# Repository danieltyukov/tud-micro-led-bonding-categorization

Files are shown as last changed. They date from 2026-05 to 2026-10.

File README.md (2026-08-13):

# Micro-LED Bonding Categorization

**A PCB test vehicle, a cleanroom bonding campaign, and an electrical characterization of eight micro-LED assembly conditions.**

TU Delft ECTM + ITEC B.V., February to August 2026. Course project (ET4277 + ET4391) and research contribution, supervised by M. Mastrangeli, H. van Zeijl and A. Abdelwahab, with R. van Hoorn and H. Kuipers (ITEC B.V. / Nexperia). Financed by ITEC B.V. and co-financed by RVO. Extends the v1 board published at [ECTC 2025](https://doi.org/10.1109/ECTC51687.2025.00363).

The question behind the work: when a ~1 mm² LED die is attached to a PCB without mounting pressure (pick-and-release / air-drop), how good is the resulting bond, and what instrument does it take to tell one bonding process from another?

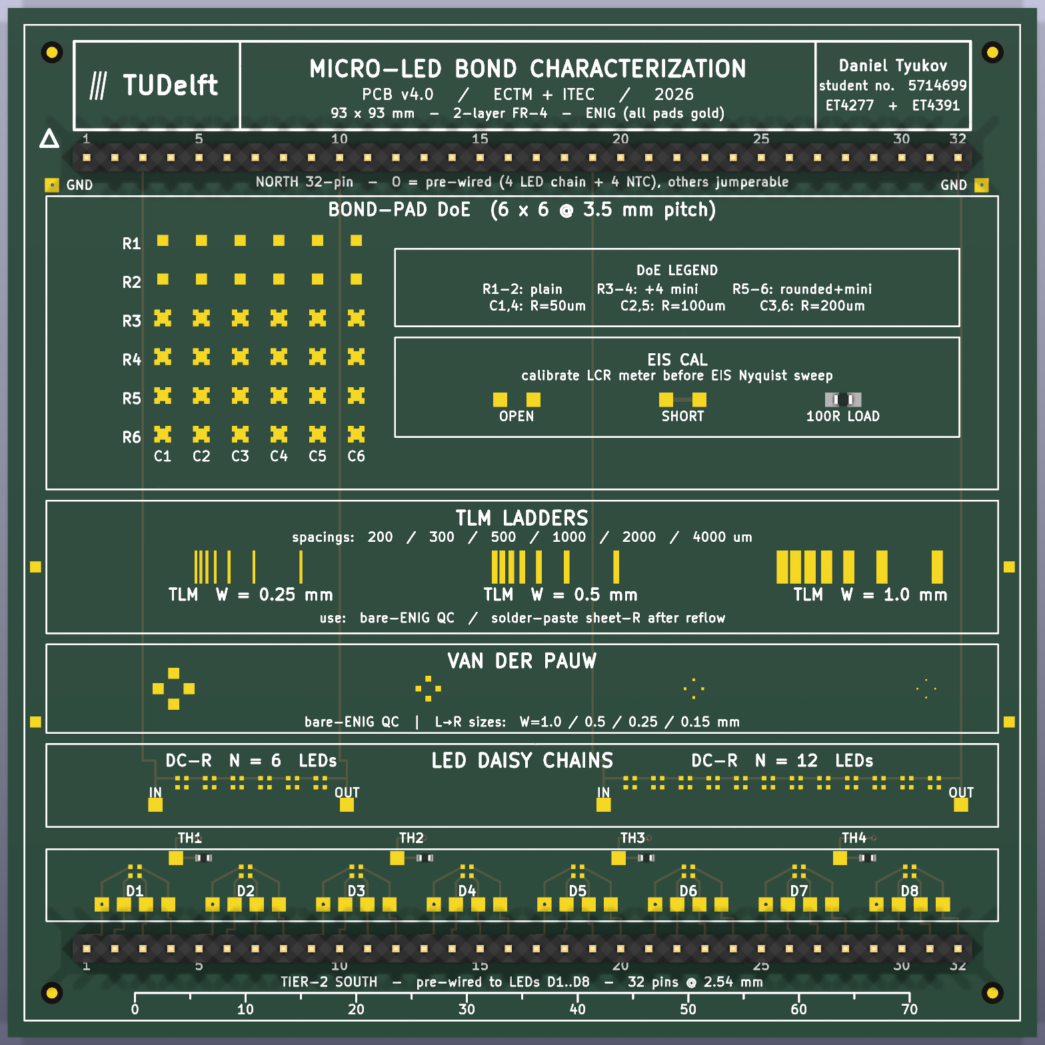
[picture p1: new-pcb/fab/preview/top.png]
Annotated fab render of the v4 micro-LED bond characterization board


---

## Headline result

**Yield and failure mode separate the eight assembly conditions. Series resistance cannot, and the reason is measured rather than assumed.**

| Condition | Channel yield | Failure modes | Assessment |
|---|---:|---|---|
| 1 | 83.3 % | 1 open, 3 detached | under-bonded |
| 2 | 58.3 % | 4 open, 6 detached | under-bonded |
| 3 | 25.0 % | 4 short, 2 open, 2 cross-lit, 1 suspect | over-bonded, 1 shunt confirmed |
| 4 | 66.7 % | 1 short, 1 open, 1 cross-lit, 1 suspect | over-bonded |
| 5 | **100 %** | none | in window |
| 6 | 75.0 % | 3 detached | under-bonded |
| 7 | **100 %** | none | in window |
| 8 | 83.3 % | 2 short | over-bonded, survivors clean |

A χ² test on the yield and failure-mode distribution gives p = 2.2 × 10⁻⁴. Conditions 5 and 7 lost nothing across every channel.

Series resistance does not discriminate: one-way ANOVA over the seven samples with n ≥ 3 gives F(6,21) = 1.96, not significant. Re-seating the same two jumpers on an unchanged channel moves R_s by **0.84 Ω**, which is 85 % of the apparent die-to-die spread, while the bond resistances being chased are **10 to 100 mΩ**. The experiment was never capable of resolving them, and the repeatability study is what proves it.

<table>
<tr>
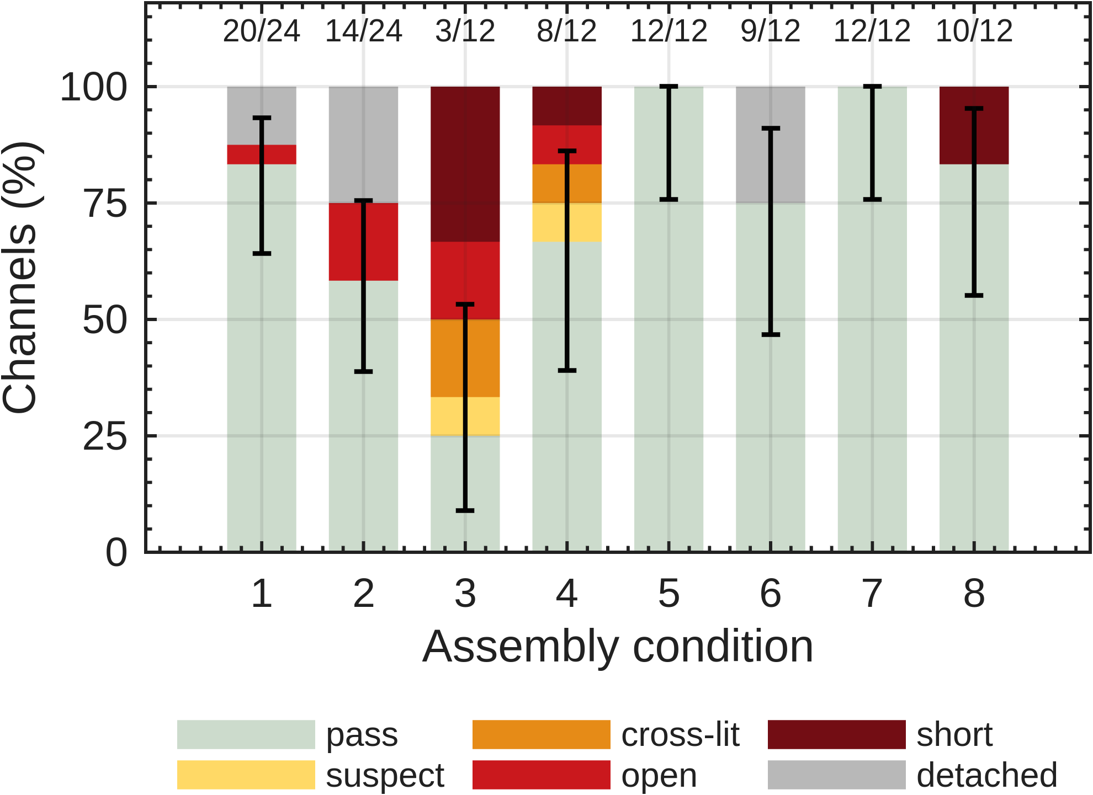
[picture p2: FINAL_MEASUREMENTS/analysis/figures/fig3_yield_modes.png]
Channel yield and failure mode by assembly condition
<td width="50%"></td>
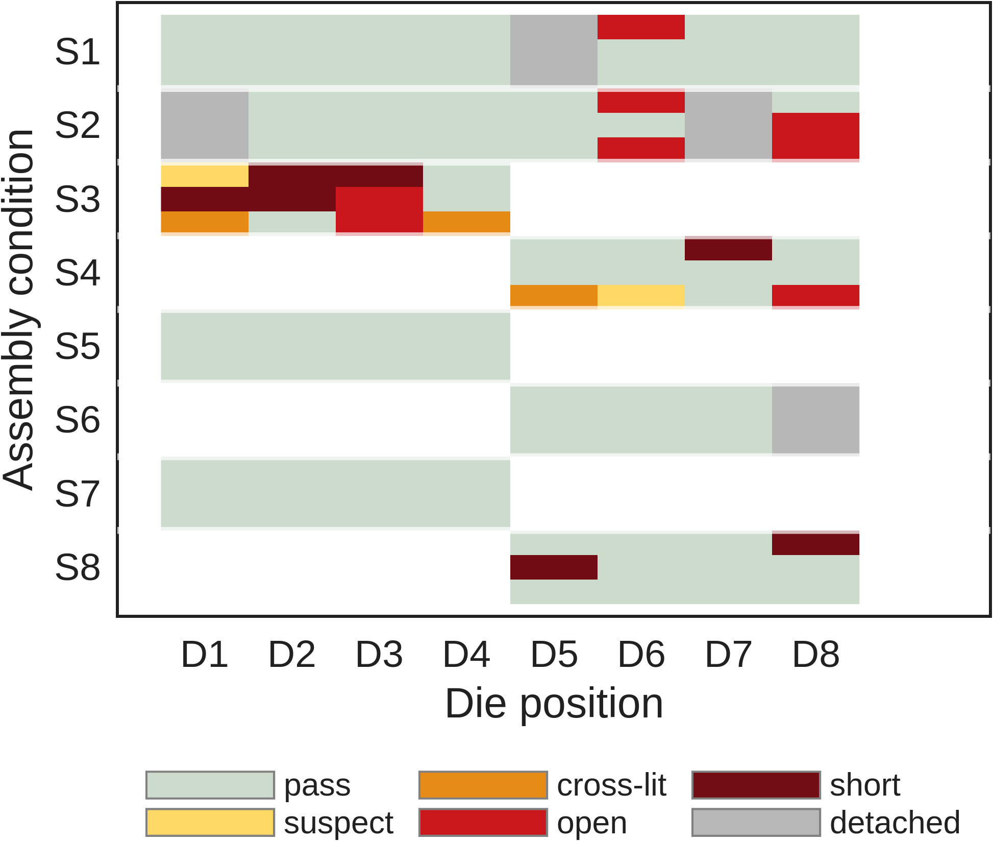
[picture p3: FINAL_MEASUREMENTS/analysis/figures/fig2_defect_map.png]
Per-die defect map across the eight conditions
<td width="50%"></td>
</tr>
<tr>
<td>Yield and failure mode per condition, with Wilson intervals.</td>
<td>Defect map: every die position, every condition.</td>
</tr>
</table>

---

## The three parts of the work

### 1. Board design

A single 93 × 93 mm two-layer FR-4 board (ENIG, all pads gold) carrying every structure needed to characterize a bond on one substrate, so that one cleanroom session yields bond resistance, contact resistivity, sheet resistance and junction thermometry from the same hardware:

- **6 × 6 bond-pad design of experiments** at 3.5 mm pitch: three pad geometries (plain, four corner mini-pads, rounded + mini) crossed with three fillet radii (50 / 100 / 200 µm).
- **TLM ladders** at W = 0.25 / 0.5 / 1.0 mm with spacings 200 to 4000 µm, and **van der Pauw cloverleaves** at W = 1.0 / 0.5 / 0.25 / 0.15 mm.
- **26 Würth WL-SFCC 0404 RGB LEDs**: eight individually addressable, eighteen in 6- and 12-die daisy chains.
- **Four 0402 NTCs** for V_F-based junction thermometry, and an **LCR calibration set** (open / short / 100 Ω 0.1 %).
- Two 32-pin headers breaking every active net out to a breadboard.

Designed in KiCad 9, DRC-clean with full schematic parity, exported fab-ready to the Eurocircuits standard pool. The five SMT parts are reflowed by the fab; the 26 LED bond pads ship as bare gold, because the joint itself is the research subject and has to form under controlled conditions.

Sources, Python generators and the full fab package (gerbers, BOM, CPL, STEP, PDFs) are in [`new-pcb/`](new-pcb/). Report: [`part1/`](part1/ET4277_ET4391_DanielTyukov_5714699_part1_microLED_PCB_electrical_characterization.pdf).

### 2. Cleanroom bonding

Solder paste printed by hand through a 100 µm stencil, dies placed with a Tresky T-3000-PRO die bonder, joint formed on a hot plate with Sn42/Bi57.6/Ag0.4 (T_melt = 138 °C). When the paste melts, surface tension pulls each die toward the centre of its pad set. The same forces can tilt a die and lock it in a crooked position that never recovers, because tilt is the one non-restoring self-alignment mode for a rectangular chip.

<table>
<tr>
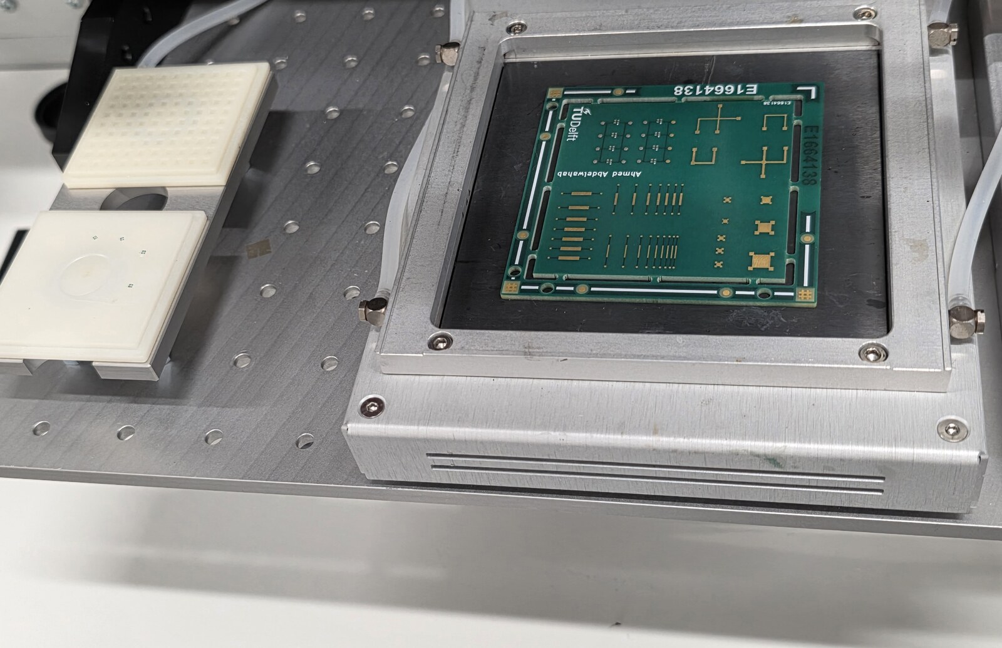
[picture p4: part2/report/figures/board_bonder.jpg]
v1 board mounted in the Tresky die bonder
<td width="50%"></td>
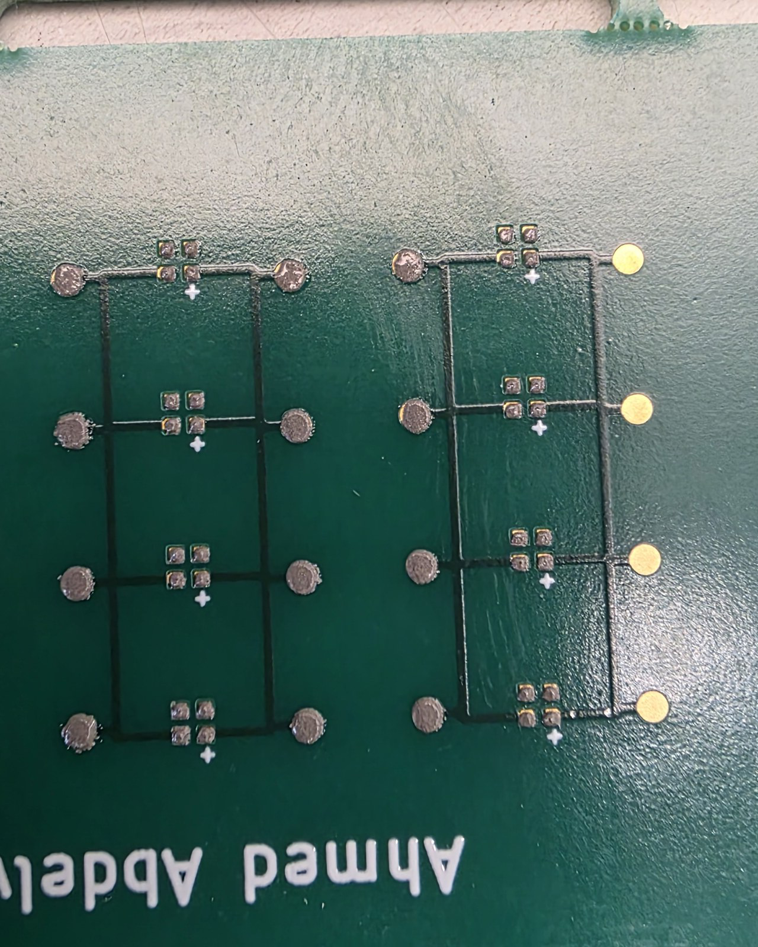
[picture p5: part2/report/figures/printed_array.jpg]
Solder-paste printed bond-pad array before die placement
<td width="50%"></td>
</tr>
<tr>
<td>Board fixtured in the Tresky T-3000-PRO.</td>
<td>Printed bond-pad array before placement.</td>
</tr>
</table>

The analytical contribution is reading the observed self-alignment and tilt against the capillary self-alignment literature to identify which process variable dominates. It is **solder volume**: manual stencil printing gives no volume metering, and volume is exactly the quantity the literature ties most strongly to both placement accuracy and the non-restoring tilt mode.

Report: [`part2/`](part2/ET4277_ET4391_DanielTyukov_5714699_part2_microLED_bonding_self_alignment_die_tilt.pdf). Session photos in [`part2/photos-during-lab2/`](part2/photos-during-lab2/), references in [`part2/downloaded_references/`](part2/downloaded_references/).

### 3. Electrical characterization

Eight blind-coded assembly conditions across five coupons, 40 dice bonded, 4 detached in handling, 36 measurable, 120 individual-die channels. Run as two rounds so that a cheap screen filtered the expensive one.

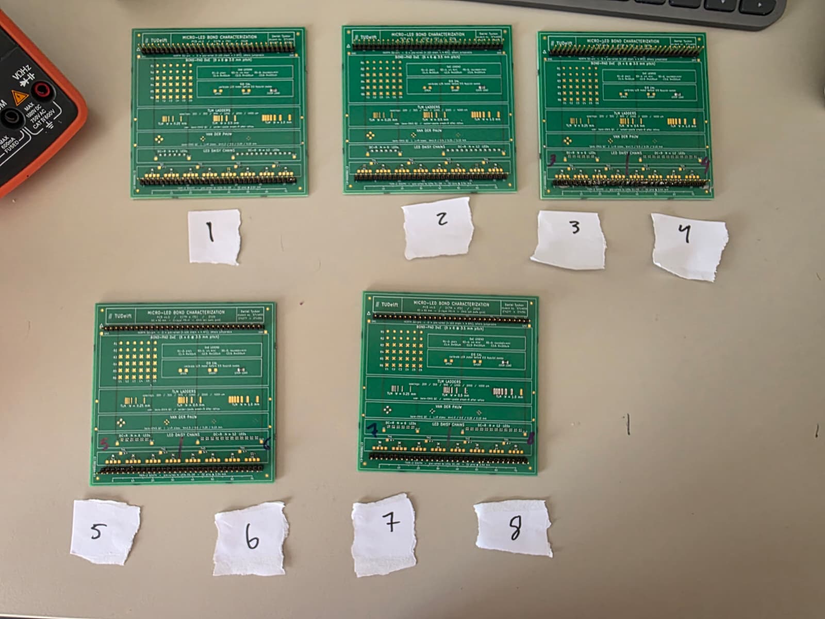
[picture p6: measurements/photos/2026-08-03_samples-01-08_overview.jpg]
The five coupons carrying the eight blind-coded assembly conditions


**Round 1, DMM screen.** Every channel screened for opens, shorts, cross-lighting and detachment with a handheld meter. It called six channels bad; the sweep rig later agreed on all six and disagreed on none in 89 sweeps.

**Round 2, current sweep.** An Arduino UNO rig switching a six-resistor bank (220 Ω to 10 kΩ) against a 100 Ω sense resistor, 63 current levels per sweep, fitting V = V₀ + n·V_T·ln(I) + I·R_s to each channel. 89 channel sweeps plus 9 re-seating repeatability runs.

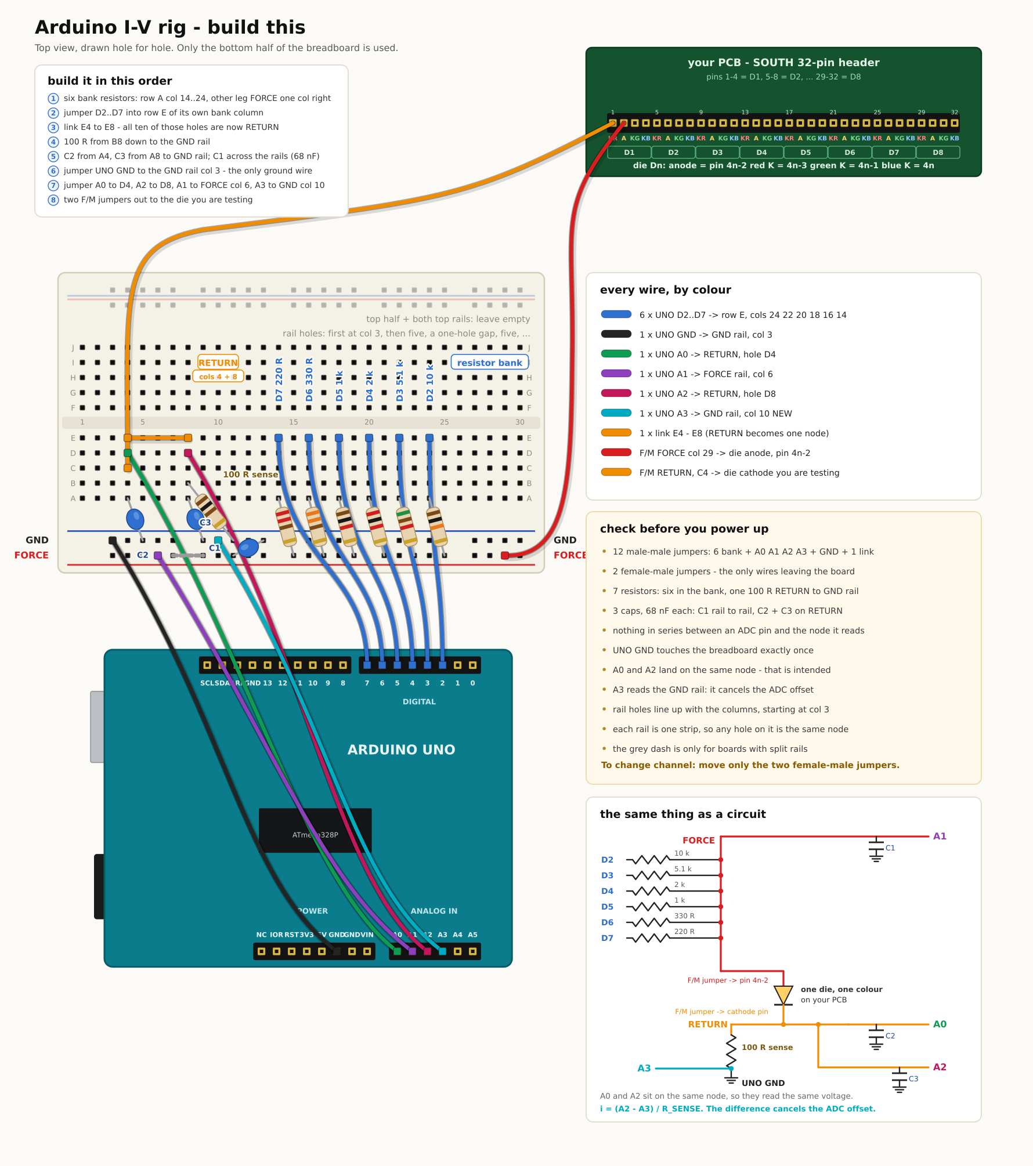
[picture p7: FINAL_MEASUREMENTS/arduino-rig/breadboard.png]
Arduino I-V rig build drawing


<table>
<tr>
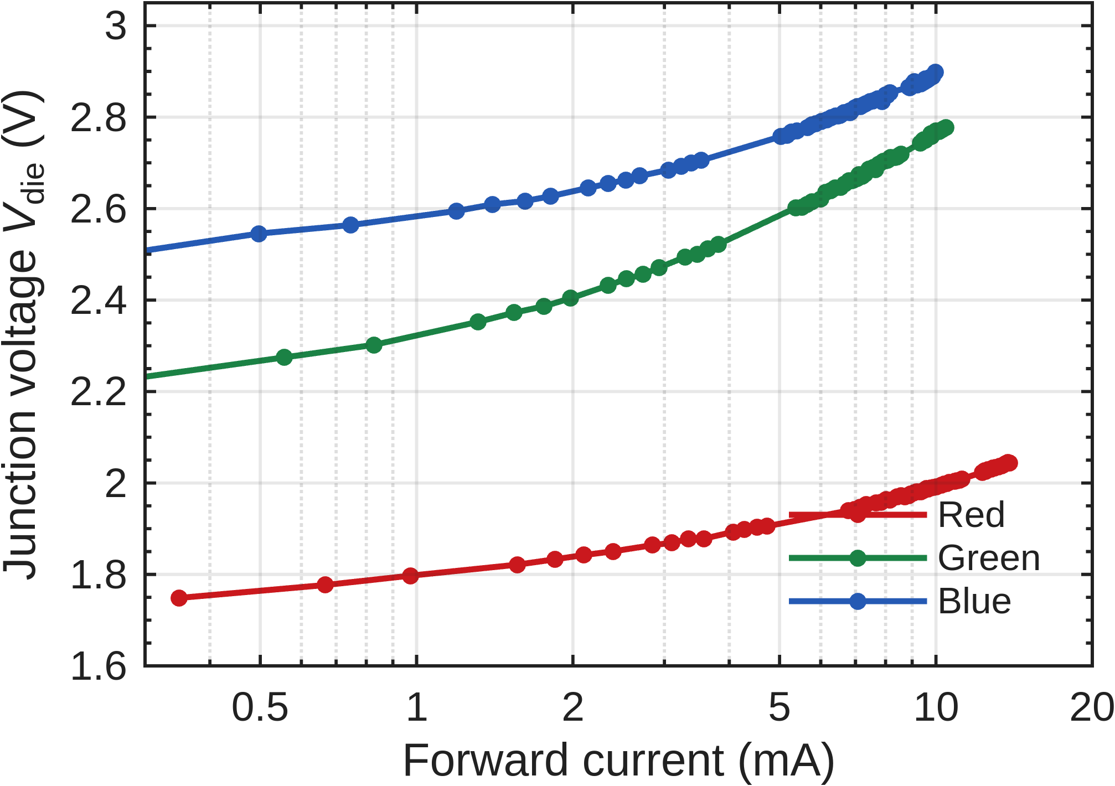
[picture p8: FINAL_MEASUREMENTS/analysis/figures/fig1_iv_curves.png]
I-V curves for the red, green and blue junctions of one die
<td width="50%"></td>
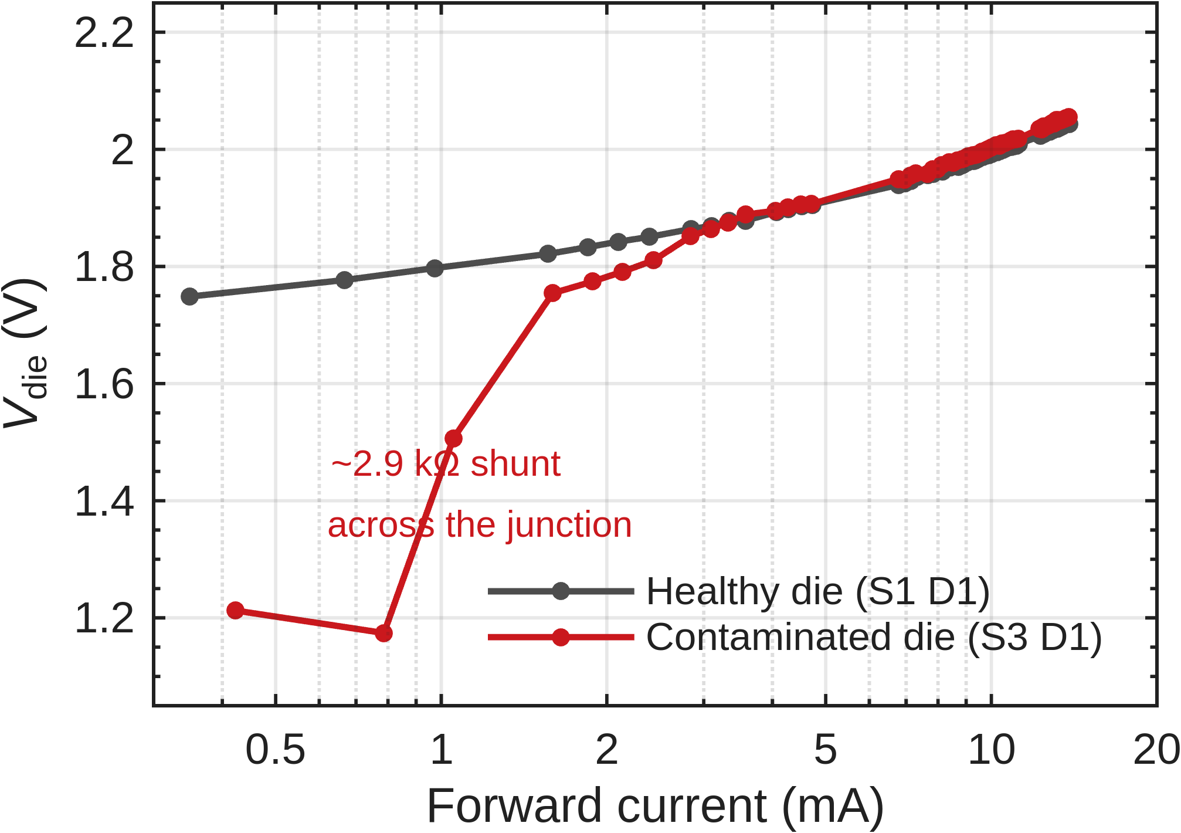
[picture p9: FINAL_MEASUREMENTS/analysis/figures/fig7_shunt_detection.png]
Ideality check exposing a 2.9 kilohm shunt across a contaminated junction
<td width="50%"></td>
</tr>
<tr>
<td>Red, green and blue junctions of one die.</td>
<td>The defect only a current sweep could see.</td>
</tr>
</table>

Three findings about the measurement itself carried more weight than the bond numbers:

- **The ideality factor is a free defect detector.** Any channel fitting outside n = 1.2 to 2.4 has something in parallel with the junction, however normal its curve looks at working current. It caught a ~2.9 kΩ shunt on a contaminated die that the DMM passed at 1.781 V.
- **Green and blue are not fittable at 5 V.** With V_F near 2.8 V the rail leaves only a 20× current range, so V₀, n and R_s trade off and green fits at an unphysical n = 3.2 to 4.0. Red gets 30× and fits cleanly at n = 1.60 to 2.06. Red only.
- **Four instrument defects were found and fixed mid-campaign**, including a hardcoded oversampling shift that would have rescaled every voltage, a 14.4 mV common ADC offset worth 26 % current error at the bottom of the sweep, and an integer-truncated bandgap reference putting a 2 to 3 mV floor on every reading.

Full working log with per-channel results: [`RESULTS/R2_REPORT.md`](RESULTS/R2_REPORT.md). Packaged deliverable with figures, MATLAB and raw data: [`deliverable/`](deliverable/microLED_electrical_characterization/).

**Dummy-die daisy chains (separate experiment, v1 board).** Measured by A. Abdelwahab on the v1 PCB in its own session, six Au-coated 1 mm² dummy dies per chain, one chain per condition. It resolves bond resistance where the LED coupons could not: 0.22 Ω on condition 5 against 0.61 Ω on condition 4, roughly 30 mΩ per joint, with a reported deviation of 11 to 20 mΩ. Its ranking agrees with the LED yield ranking at ρ = −0.92 (p = 0.003). That is agreement between assembly conditions across two different test vehicles and two campaigns, not two structures on one coupon, and it assumes the condition numbering matches. The v2 board carries daisy chains as well, but none were measured: a layout fault left them dead, so they were diagnosed and excluded rather than characterized (see Known limits). Data and figure: [`RESULTS/daisy_chain/`](RESULTS/daisy_chain/).

---

## Known limits

Stated up front, because they decide what these numbers can be used for.

| Limit | Consequence |
|---|---|
| Both voltage taps sit on the breadboard, not on the Tier-1 probe pads | Two female-male jumpers fall inside the measured loop. R_s is not usable for comparing bonds in this build. Kelvin sensing at the probe pads fixes it. |
| 5 V supply | Green and blue fits are unphysical. Red only. |
| Reverse bias measured through the meter's own 10 MΩ input impedance | Detects shunts below ~10 MΩ, cannot grade healthy dies. It confirmed the yield ranking rather than adding to it. |
| Daisy chains read open on every coupon | Layout fault, not a bonding failure: the dice sit rotated 90°, so the chain joins each die's red cathode to its blue cathode and leaves the anode floating. Fixed in the next revision. |
| One coupon carries uncleanable solder smear | Its readings characterize a post-process contamination failure and are excluded from V_F statistics. |
| No NTC readings collected | Ambient drift cannot be separated from self-heating at analysis time. |
| TLM, van der Pauw and impedance spectroscopy | Designed into the board, but the instruments were not available during the campaign. The structures are there for whoever has them. |

---

## Repository layout

| Path | Contents |
|---|---|
| [`new-pcb/`](new-pcb/) | v4 KiCad project, Python generators, Eurocircuits fab package, design notes |
| [`part1/`](part1/) | Board design and characterization-methodology report, project archive, fab quote |
| [`part2/`](part2/) | Bonding process report, cleanroom photos, self-alignment literature |
| [`FINAL_MEASUREMENTS/`](FINAL_MEASUREMENTS/) | Bench procedures, Arduino rig build drawings, MATLAB analysis, figures |
| [`RESULTS/`](RESULTS/) | Raw round 1 and round 2 data, per-channel results, round 2 report |
| [`measurements/`](measurements/) | Measurement plan, equipment limits, sample inventory, decision log |
| [`deliverable/`](deliverable/) | Self-contained characterization package: report, figures, code, data |
| [`old-pcb/`](old-pcb/) | v1 board (ECTC 2025), kept for reference |
| [`docs/`](docs/) | Datasheets, published papers, patent, collaboration notes |
| [`PROJECT_DETAILS.md`](PROJECT_DETAILS.md) | Full project context, v1 board teardown, literature notes |

## Reproducing the analysis

```
cd deliverable/microLED_electrical_characterization/matlab
matlab -batch figures
```

Reads `../data/`, refits every sweep, writes all eight figures, and prints every number quoted in the report. MATLAB R2025b with the Statistics and Machine Learning Toolbox (`anova1`, `chi2cdf`).

Board previews and fab outputs regenerate from `new-pcb/tools/`; see [`new-pcb/README.md`](new-pcb/README.md) and [`new-pcb/FABRICATION_ORDER.md`](new-pcb/FABRICATION_ORDER.md) for the ordering workflow.

## Reports

| Report | File |
|---|---|
| Part 1: A PCB Test Board for Electrical Characterization of Solder-Bonded Micro-LEDs | [PDF](part1/ET4277_ET4391_DanielTyukov_5714699_part1_microLED_PCB_electrical_characterization.pdf) |
| Part 2: Solder-Paste Printing and Die-Bonder Placement of Micro-LEDs, Capillary Self-Alignment and Die Tilt | [PDF](part2/ET4277_ET4391_DanielTyukov_5714699_part2_microLED_bonding_self_alignment_die_tilt.pdf) |
| Electrical characterization section (group deliverable) | [PDF](deliverable/Electrical_Characterization_section.pdf) |

## Tooling

KiCad 9, Python (fab, BOM and drawing generators), MATLAB R2025b, Arduino UNO / ATmega328P firmware, Eurocircuits PCB + PCBA, Tresky T-3000-PRO die bonder, eC-stencil-mate, handheld DMM.

## Credits

Daniel Tyukov (student no. 5714699), MSc Microelectronics, TU Delft. Supervision and cleanroom training: A. Abdelwahab, H. van Zeijl, M. Mastrangeli (TU Delft ECTM). Industrial partner: R. van Hoorn, H. Kuipers (ITEC B.V. / Nexperia). The v1 board and the pick-and-release method are the work of Abdelwahab et al., ECTC 2025, DOI [10.1109/ECTC51687.2025.00363](https://doi.org/10.1109/ECTC51687.2025.00363).

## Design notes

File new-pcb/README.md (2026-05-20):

# new-pcb — v2 Micro-LED Bonding Characterization PCB

**Status: fab-ready.** DRC clean (0 violations, 0 unconnected, 0 schematic-parity). Workflow: *Eurocircuits PCB + PCBA-proto*, all 3 BOM lines set to "Place on board" so the 4 NTC + 1 R + 2 header strips are reflowed / soldered by Eurocircuits. F.Paste has 10 apertures (NTC + R only); the 26 LED footprints stay paste-free and ship as bare ENIG gold for cleanroom bonding at TU Delft EKL.

## Quick links

- **Order from Eurocircuits** → `FABRICATION_ORDER.md`
- **As-built design notes** → `V2_DESIGN_NOTES.md`
- **Original spec** → `PCB_DESIGN_PLAN.md`
- **Electrical characterization workflow** → `ELECTRICAL_CHARACTERIZATION.md`
- **What this v2 contributes vs ECTC 2025** → `PUBLICATION_CONTRIBUTION.md`

## Folder layout

```
new-pcb/
├── tud-microled-v2.kicad_pro     KiCad 9.0.8 project
├── tud-microled-v2.kicad_pcb     PCB layout (130 footprints, DRC clean)
├── tud-microled-v2.kicad_sch     single-sheet A2 schematic
├── PCB_DESIGN_PLAN.md            original design spec
├── V2_DESIGN_NOTES.md            as-built notes
├── VERIFICATION_v4.md            electrical-characterization verification
├── ELECTRICAL_CHARACTERIZATION.md measurement plan + lab tools
├── FABRICATION_ORDER.md          Eurocircuits "Place loose" order checklist
├── PUBLICATION_CONTRIBUTION.md   v2 contributions vs ECTC 2025
├── library/                      Würth WL-SFCC LED symbol/footprint/3D
├── tools/                        Python helpers (PCB patcher, BOM generator)
└── fab/                          gerbers, BOM, pos, PDFs, STEP, top.png
    ├── tud-microled-v2-fab-bom.csv          BOM with TDK + Yageo + Samtec MPNs (Mouser PNs included)
    ├── tud-microled-v2-fab-bom-assembly-only.csv  slim BOM (the 3 assembled rows only)
    ├── tud-microled-v2-pos.csv               7 placements
    ├── tud-microled-v2-top.pdf / -bot.pdf    visual review
    ├── tud-microled-v2-gerbers.zip           26-file gerber + drill bundle
    ├── tud-microled-v2.step                  3D model
    └── preview/top.png                       1600×1600 raytraced render
```

## Design summary

| | |
|---|---|
| Board | 93 × 93 mm, 2-layer FR-4, 1.55 mm |
| Finish | ENIG (Ni 4 µm / Au 0.075 µm) |
| Min track / clearance | 0.20 / 0.30 mm (Eurocircuits Class 4 minimum is 0.15 mm) |
| Min drill / annular ring | 0.30 / 0.15 mm |
| Footprints on board | **130** (1 R + 4 NTC + 2 multi-pin headers + 26 LEDs DNP) |
| Distinct components | **3** (Yageo R, TDK NTC, Samtec header) |
| Placements per board (assembled) | **7** (1 R + 4 NTC + 2 header strips) |
| LED bonding | 26 × Würth WL-SFCC RGB at customer cleanroom (Tresky T-3000-PRO) |
| Solder-paste apertures | **10** on F.Paste (4 NTC × 2 + 1 R × 2). B.Paste empty. 26 LED footprints intentionally paste-free. |

## Bill of materials

3 distinct part numbers — all stocked at Mouser EU (1-day NL delivery) and resolvable through Eurocircuits' supplier scanner:

| Ref(s) | Manufacturer | MPN | Mouser PN |
|---|---|---|---|
| R_EIS_LOAD | Yageo | RT0603BRB07100RL | 603-RT0603BRB07100RL |
| H_N + H_S | Samtec | TSW-140-07-G-S | 200-TSW14007GS |
| TH1..TH4 | TDK | NTCG104BH103HT1 | 810-NTCG104BH103HT1 |

## Quick start

1. Open `tud-microled-v2.kicad_pro` in KiCad 9.0 or newer.
2. Confirm `WE_3DMODEL_DIR` is set in **Preferences → Configure Paths** (see `library/README.md`).
3. Run checks: `kicad-cli pcb drc tud-microled-v2.kicad_pcb` and `kicad-cli sch erc tud-microled-v2.kicad_sch` — both should report 0 violations.
4. Regenerate fab outputs after any PCB edit:
   - `kicad-cli pcb export gerbers --output fab/gerbers/ tud-microled-v2.kicad_pcb`
   - `kicad-cli pcb export drill --output fab/gerbers/ tud-microled-v2.kicad_pcb`
   - `kicad-cli pcb export pos --format csv --units mm --use-drill-file-origin --output fab/tud-microled-v2-pos.csv tud-microled-v2.kicad_pcb`
   - `kicad-cli pcb export pdf --layers F.Cu,F.Silkscreen,F.Mask,Edge.Cuts -o fab/tud-microled-v2-top.pdf tud-microled-v2.kicad_pcb`
   - `kicad-cli pcb render --side top --width 1600 --height 1600 --quality high --output fab/preview/top.png tud-microled-v2.kicad_pcb`
   - `python3 tools/gen_fab_bom.py` to refresh the BOM CSV
   - `(cd fab/gerbers && zip -q ../tud-microled-v2-gerbers.zip *)` to rebundle for Eurocircuits

## tools/ scripts

| Script | Purpose |
|---|---|
| `gen_fab_bom.py` | Reads `fab/tud-microled-v2-pos.csv`, emits `tud-microled-v2-fab-bom.csv` + slim variant |
| `patch_aisler_mpns.py` | Adds Manufacturer + MPN custom fields to each footprint so any fab auto-detects them |
| `consolidate_pcb.py` | One-time refactor that collapsed 64 single-pin headers into 2 multi-pin strips and deleted the 123 bare-pad design-only footprints |
| `strip_all_paste.py` | Removes F.Paste / B.Paste from every pad in the design (used for the loose-components workflow) |
| `clean_dangling.py` | Removes orphan tracks/vias left over by `consolidate_pcb.py` |
| `unify_values.py` | Sets the `Value` field of every footprint to its MPN so Aisler/EC Grouped views collapse them properly |
| `inspect_headers.py` | Read-only debug helper |

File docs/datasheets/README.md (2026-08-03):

# Component Datasheets — v2 PCB

Datasheets for every component ordered for the v2 PCB. All MPNs match the BOM in `new-pcb/fab/tud-microled-v2-fab-bom.csv` and are verified in stock on Mouser EU at order time.

**Components ship loose from Eurocircuits ("Place loose") and are hand-soldered at TU Delft EKL. The 26 LEDs are customer-supplied and bonded at EKL under the Tresky T-3000-PRO with a controlled paste profile.**

---

## Final BOM (3 distinct parts, 7 placements per board)

| Designator(s) | Qty / board | Manufacturer | MPN | Mouser PN | Datasheet file |
|---|---:|---|---|---|---|
| TH1, TH2, TH3, TH4 | 4 | TDK | `NTCG104BH103HT1` | 810-NTCG104BH103HT1 | `TDK-NTCG104BH103HT1-NTC.pdf` |
| R_EIS_LOAD | 1 | Yageo | `RT0603BRB07100RL` | 603-RT0603BRB07100RL | `Yageo-RT0603BRB07100RL-Resistor.pdf` |
| H_N, H_S | 2 | Samtec | `TSW-140-07-G-S` (cut to 1×32) | 200-TSW14007GS | `Samtec-TSW-Series-PinHeader.pdf` |
| D1-D8 + DCL6_L1..6 + DCL12_L1..12 | 26 | Würth | `150044M155220` | 710-150044M155220 | `Wurth-WL-SFCC-0404-RGB-LED-150044M155220.pdf` |

---

## Datasheets in this folder

| File | Pages | Component | Where on PCB |
|---|---:|---|---|
| `TDK-NTCG104BH103HT1-NTC.pdf` | 20 | TDK NTCG104 series — NTC 10 kΩ ±3% 0402, AEC-Q200 | TH1..TH4 |
| `Yageo-RT0603BRB07100RL-Resistor.pdf` | 10 | Yageo RT series — 100 Ω ±0.1% 0603 thin-film, 10 ppm/°C | R_EIS_LOAD |
| `Samtec-TSW-Series-PinHeader.pdf` | 6 | Samtec TSW series — product specification sheet (electrical, mechanical) | H_N + H_S |
| `Wurth-WL-SFCC-0404-RGB-LED-150044M155220.pdf` | 10 | Würth WL-SFCC RGB LED — full electrical/optical/mechanical/reflow | D1..D8, DCL6_L1..6, DCL12_L1..12 |

All downloaded from manufacturer / Mouser EU on **2026-05-19**.

---

## Test-equipment documentation (added 2026-08-03)

For the measurement campaign in `FINAL_MEASUREMENTS/`.

| File | Pages | What it is |
|---|---:|---|
| `INSTRUMENTS.md` | - | **Start here.** Extracted specs for the multimeter and the Arduino, with what is documented, what is not, and the numbers that must be measured at the bench instead. |
| `Arduino-UNO-R3-Datasheet.pdf` | 26 | Arduino UNO R3 board datasheet |
| `Microchip-ATmega328P-Datasheet.pdf` | 294 | Microchip 7810D-AVR-01/15. Source of the ADC specs and the absolute maximum ratings that constrain the current bank |
| `Thsinde-18B-plus-Independent-Review-N8FDY.pdf` | 8 | Independent bench review of this exact meter against a calibrated Keithley DMM6500. **The only source for its diode-test voltage and current.** |
| `Fluke-15B-17B-18B-plus-Users-Manual.pdf` | 23 | **A different instrument.** Cross-reference only, see below |

### On the Thsinde 18B+ multimeter

**No manufacturer manual exists.** The only page that claims to be one
(`manuals.plus/thsinde/...`) is AI-generated SEO filler carrying the Amazon listing spec
table plus invented reviews and a price. It contains no operating instructions, no button
behaviour, and no diode-test specification. It is not worth storing, so its usable content
is transcribed into `INSTRUMENTS.md` instead.

The Fluke 15B+/17B+/18B+ manual is stored as a cross-reference **only**. It is a different
instrument: 4000 counts rather than 6000, no NCV, no REL, no MAX/MIN, and it has a
dedicated LED TEST dial position that the Thsinde does not. The Thsinde borrowed the model
number and the styling. Do not quote its specifications as if they were the Thsinde's.

The gap is filled by the N8FDY independent review, which measured the meter against a
calibrated Keithley DMM6500. Its key result for this project: **diode test open-circuit
voltage 3.245 V, short-circuit current 1.49 mA.** 3.245 V clears the forward voltage of
red, green and blue, so all three channels are testable in round 1 step 6. That had been
the largest open risk in the measurement plan. It is still re-confirmed on the board's own
100 Ω 0.1 % reference at the start of each session.

---

## Component summary

### TDK NTCG104BH103HT1 — SMD 0402 NTC
- 1.0 × 0.5 mm body, 2 SMD pads
- R(25 °C) = 10 kΩ ±3 %, **B25/85 = 4100 K** (datasheet row for this MPN: 4067 / 4092 / 4100 / 4110 K for B25/50, B25/80, B25/85, B25/100)
- **Correction 2026-08-03:** this file previously said 3380 K. That is the B25/50 figure for the *NTCG10xJF/JH* family, a different B-constant grade. The ordered part is the `BH` grade, which is the 4067-4110 K row.
- AEC-Q200 qualified, −55 °C to +125 °C operating range
- Sense current ≤ 100 µA to keep self-heating < 0.01 °C
- For V_F-TSP thermometry calibration: see `new-pcb/VERIFICATION_v4.md` §6.2
- Mouser EU stock: 12,207 (verified 2026-05-19)

### Yageo RT0603BRB07100RL — SMD 0603 thin-film
- 1.6 × 0.8 mm body
- 100 Ω, ±0.1 %, **10 ppm/°C** TCR, 100 mW (1/10 W)
- −55 °C to +155 °C operating range, 75 V max
- Used as the EIS reference load for LCR-meter calibration before Nyquist sweeps
- Mouser EU stock: 15,867 (verified 2026-05-19)
- Note: chosen over the original RT0603BRD07100RL because BRD was out of stock (backorder to Sep 2026); BRB is a strict upgrade (10 ppm/°C vs 25 ppm/°C TCR) at the same form factor

### Samtec TSW-140-07-G-S — THT 1×40 single-row male pin header
- 2.54 mm pitch, gold-plated contacts (Ni underplate + Au flash)
- Pin cross-section: 0.64 mm square
- Pin length above board: 5.84 mm
- Insulator height: 2.54 mm
- Each board uses 2 strips (one trimmed to 32 pins for the north row, one for the south row)
- Drill 1.0 mm, pad 1.7 mm Ø → annular ring 0.35 mm
- Mouser EU stock: 338 (verified 2026-05-19) — sufficient for 20 strips needed by 10 boards

### Würth WL-SFCC 0404 RGB LED — SMD (customer-bonded)
- 0.95 × 0.95 × 0.25 mm body, 4 contact pads at corners (one anode + R/G/B cathodes)
- V_F red ≈ 2.05 V, green/blue ≈ 3.05 V at 10 mA
- Reflow recommended per Würth profile §6 of the datasheet — *not used here* because we bond at EKL with the Tresky's controlled profile
- Bond pads ship as bare ENIG gold (F.Paste gerber is empty — fab applies no paste)

---

## NTC R-T equation (for V_F-TSP calibration)

T(K) = 1 / [ (1/T₀) + (1/B) · ln(R / R₀) ]

with T₀ = 298.15 K, R₀ = 10 000 Ω, **B = 4100 K**. See `new-pcb/VERIFICATION_v4.md` §6.2 for the full thermal-resistance test procedure.

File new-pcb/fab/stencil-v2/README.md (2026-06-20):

# Stencil v2 — corrected solder-paste stencil (Eurocircuits)

Generated from `tud-microled-v2.kicad_pcb` (KiCad 9.0). This folder contains the
data to order a **new top-side solder-paste stencil** that fixes the previous one.

## What was wrong with the first stencil

The previous stencil had apertures on **only 10 pads** — `TH1–TH4` (thermistors)
and `R_EIS_LOAD` — because those were the only pads carrying an `F.Paste` layer.
Every bond/LED/test pad lacked a paste aperture, so the stencil came back
effectively "reversed": openings only where solder had already been hand-applied,
and nothing where paste actually needs to be printed.

## What this stencil does (two aperture types on `F.Paste`)

1. **Paste apertures** (1:1 with the copper pad) on the **277 bond/characterization
   pads**: DoE bond pads (`BP_*`), WL-SFCC LED lands (`D1–D8`, `DCL6_*`, `DCL12_*`),
   thermocouple pads (`TC*`), and the TLM ladders + Van der Pauw structures
   (`TLM_*`, `VDP_*`) — those are part of the solder/contact-resistance
   characterization, so they get solder.

   **Deliberately left bare (no paste)** — only where a probe tip or vision system
   touches: all probe pads (`PP_*` — daisy-chain in/out, per-LED A/KB/KG/KR, NTC,
   GND, EIS open/short cal) and the fiducials (`FID*`). These keep their soldermask
   opening but get no solder.

2. **Clearance reliefs** (a window drawn *around the component body*, not a paste
   dot) so the foil lies flat over parts already on the board — **no bulges**:
   | Part | Relief window (mm) |
   |------|--------------------|
   | `H_N` header (top pin row) | 5.68,12.05 → 87.32,14.95 |
   | `H_S` header (bottom pin row) | 5.68,83.55 → 87.32,86.45 |
   | `TH1` | 16.6,76.15 → 18.8,77.45 |
   | `TH2` | 36.6,76.15 → 38.8,77.45 |
   | `TH3` | 56.6,76.15 → 58.8,77.45 |
   | `TH4` | 76.6,76.15 → 78.8,77.45 |
   | `R_EIS_LOAD` | 73.52,34.41 → 77.48,36.38 |

   The header pins/bodies and the soldered thermistors/resistor pass through these
   windows. **Note:** these are open windows in the paste layer — if you don't want
   paste falling through over the already-soldered parts, simply don't squeegee
   across those windows (or tape them off during print).

## Files

- `tud-microled-v2-F_Paste.gbr` — the stencil aperture layer (**this is the stencil**)
- `tud-microled-v2-Edge_Cuts.gbr` — board outline, for alignment/registration
- `tud-microled-v2-stencil-v2.zip` — both of the above, zipped for upload
- `paste_preview.svg` / `paste_preview.png` — visual check of the aperture pattern
- `drc_report.txt` — KiCad DRC result (0 violations)

## Ordering notes (Eurocircuits stencil service)

- Order **top stencil only** (no bottom-side components/paste).
- Suggested foil thickness **100–120 µm**. The bond pads (0.4 mm LED, 0.5 mm DoE)
  and the wide TLM bars print fine. **Fine-feature caveat:** the smallest Van der
  Pauw apertures are 0.15 mm and 0.25 mm squares — below the reliable paste-release
  limit (area ratio < 0.66) even with a 100 µm foil, so those central squares may
  transfer little or no paste. The openings are there; just don't count on a clean
  deposit on the 0.15/0.25 mm VDP squares. A thinner foil helps marginally.
- The foil can be larger than the 93 × 93 mm board and trimmed after, as discussed.

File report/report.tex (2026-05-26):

\documentclass[conference]{IEEEtran}
\IEEEoverridecommandlockouts

\usepackage{cite}
\usepackage{amsmath,amssymb,amsfonts}
\usepackage{graphicx}
\usepackage{textcomp}
\usepackage[official]{eurosym}
\usepackage{xcolor}
\usepackage{booktabs}
\usepackage{siunitx}
\usepackage{url}
\usepackage{hyperref}
\hypersetup{colorlinks=true,linkcolor=blue,citecolor=blue,urlcolor=blue}

\def\BibTeX{{\rm B\kern-.05em{\sc i\kern-.025em b}\kern-.08em
    T\kern-.1667em\lower.7ex\hbox{E}\kern-.125emX}}

\begin{document}

\title{A PCB Test Board for Electrical Characterization of Solder-Bonded Micro-LEDs\\
{\normalsize Course report — ET4277 + ET4391 — Part 1}}

\author{\IEEEauthorblockN{Daniel Tyukov}
\IEEEauthorblockA{\textit{Department of Microelectronics, ECTM + ITEC}\\
\textit{Delft University of Technology}\\
Delft, the Netherlands \\
Student no. 5714699 \;\textbar\; \texttt{d.a.tyukov@student.tudelft.nl}}
}

\maketitle

\begin{figure}[!t]
  \centering
  
\end{figure}

\begin{abstract}
This work presents a 93~mm $\times$ 93~mm two-layer FR-4 PCB designed to
characterize how different solder pastes perform when bonding micro-LEDs.
The board carries 26 Würth WL-SFCC 0404 RGB LEDs (8 addressable, 18 in two
daisy chains), four 0402 NTCs for forward-voltage thermometry, a 100~$\Omega$
0.1\% reference resistor with OPEN/SHORT/LOAD pads for impedance
spectroscopy, and a set of TLM ladders and van der Pauw cloverleaves on the
same substrate. Putting all of this on one PCB means a single cleanroom
session yields bond resistance, contact resistivity, sheet resistance, and
junction-to-substrate thermal resistance from the same hardware. No
separate test coupons, no inter-board correlation. Two 32-pin headers break
every active net out to a breadboard. The board is fab-ready for the
Aisler or Eurocircuits standard pool with ENIG plating; LEDs are
deliberately left unassembled,
since the bond joint itself is the research subject and has to form under
controlled cleanroom conditions. The report covers the schematic, the
characterization methods, the tools needed to run them, and the four-paste
comparison the design was built for.
\end{abstract}

\begin{IEEEkeywords}
micro-LED, die bonding, solder paste, V$_F$-TSP, electrochemical impedance
spectroscopy, transmission line method, van der Pauw, daisy chain, electrical
characterization, PCB test vehicle
\end{IEEEkeywords}

\section{Introduction}

Mounting a sub-millimeter LED die on a PCB sounds simple until you measure
it. The joint has to carry current with a low voltage drop, pull heat out
of the die fast enough to keep it from cooking itself, and survive whatever
thermomechanical cycling the application throws at it. With SAC305 reflow
paste, the cheap default, the quality of that joint depends on paste
rheology, stencil aperture, reflow profile, and substrate finish.
Alternative chemistries (Au-Sn eutectic \cite{yin2024ausn}, Cu-Cu direct
bonding \cite{wang2023cucu}, polymer-reinforced pastes
\cite{ji2023polymer}) trade one of those parameters for another.

This board extends the v1 design Abdelwahab et al.\ shipped at ECTC 2025
\cite{abdelwahab2025ectc}. The v1 measured bond yield and V$_F$ only. v2
adds three more characterization methods (TLM contact resistivity, van der
Pauw sheet resistance, EIS impedance) on the same substrate, so one
cleanroom session produces a complete electrical fingerprint of whatever
paste-and-reflow combination was run. The design deliberately targets the
Aisler / Eurocircuits standard pool, not a semiconductor fab, to keep the
boards cheap (\textasciitilde\euro40--50 each) and reproducible at any
university lab.

\section{Board Architecture}

\begin{figure*}[!t]
  \centering
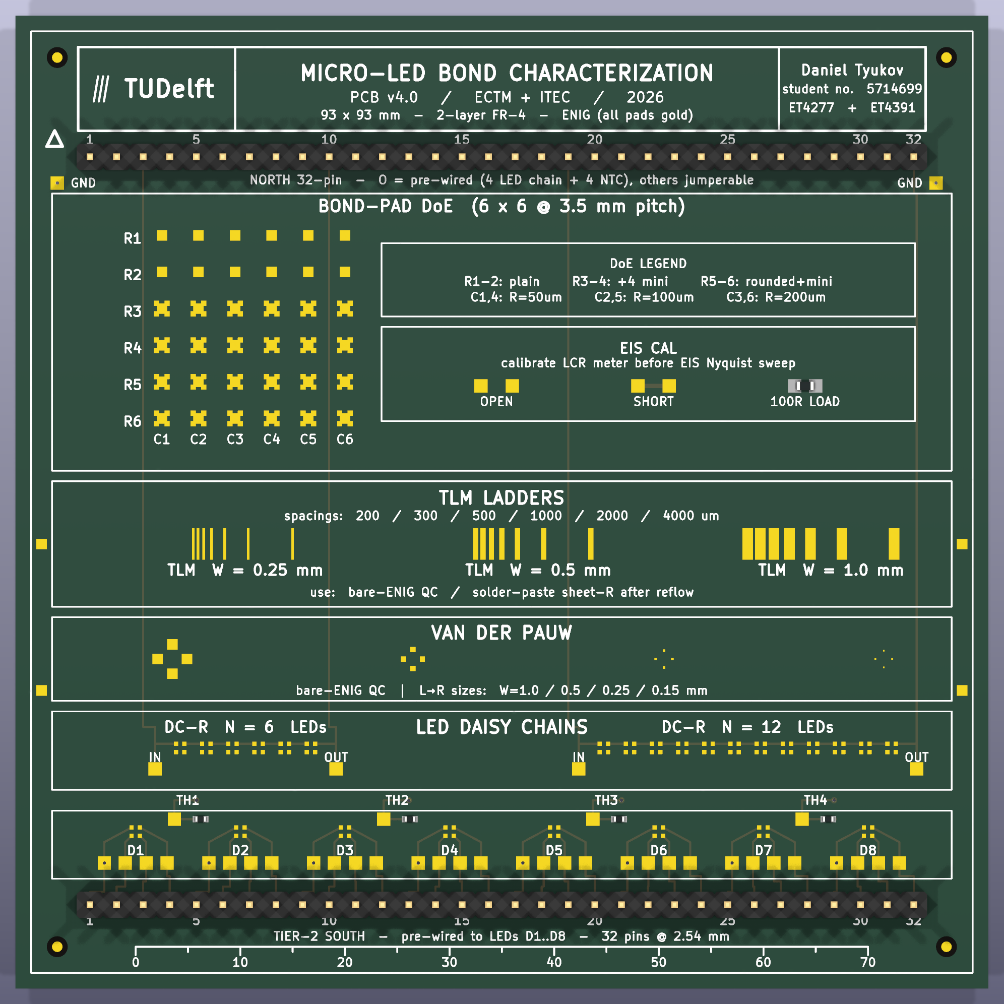
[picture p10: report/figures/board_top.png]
  \hspace{0.04\textwidth}
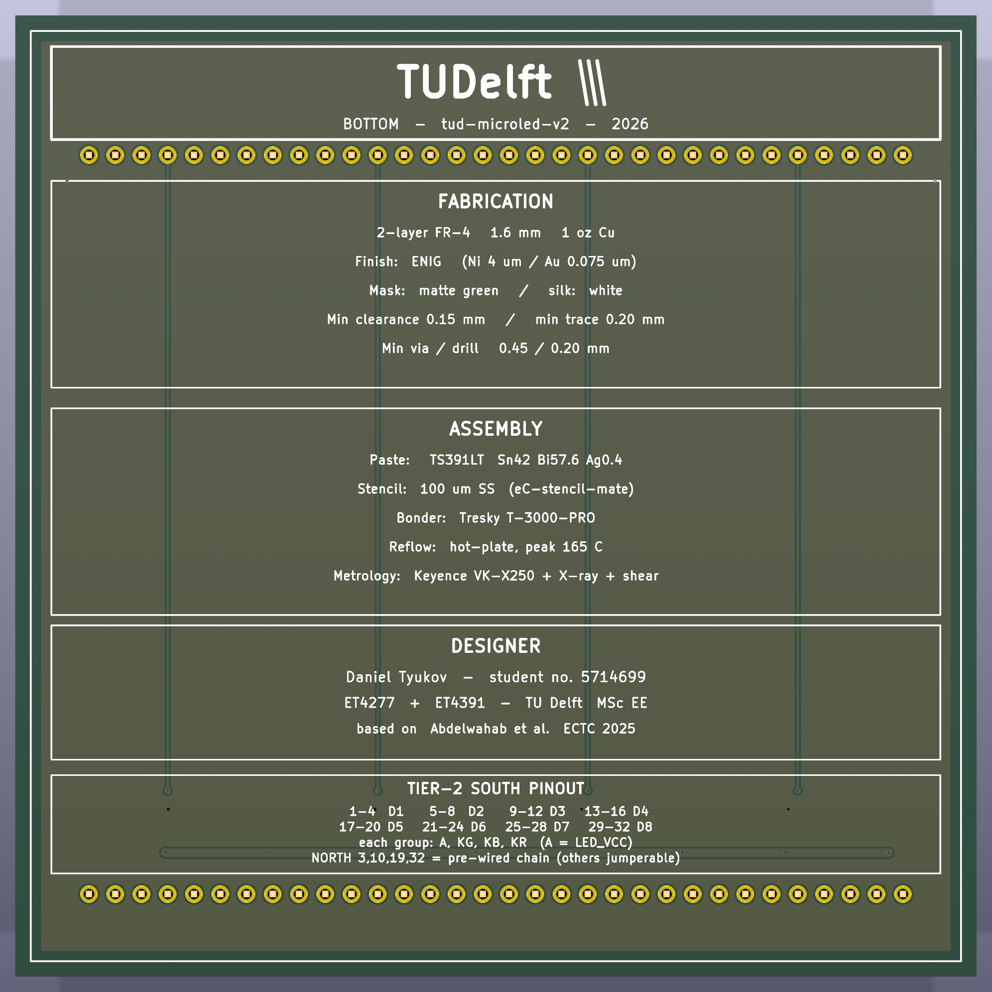
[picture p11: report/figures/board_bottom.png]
  
  \caption{v4.0.7 PCB, 93~mm $\times$ 93~mm, two-layer FR-4, ENIG finish.
  Left: top side, with the DoE bond-pad array and EIS calibration block in
  the upper half, the TLM ladders and VDP cloverleaves in the middle, and
  the LED row plus NTCs at the bottom. Right: bottom side, with the
  fabrication / assembly / designer text blocks and the south-header pinout
  legend that maps the 32 cable wires to the eight LED slots.}
  \label{fig:board}
\end{figure*}

The board (Fig.~\ref{fig:board}) is organized top to bottom into five
strips. The top edge has the title block and the north 32-pin header. Of
the 32 pins, 8 are pre-routed to the chain endpoints and the NTC sense
lines; the other 24 are bare for jumpering, which is useful when bypassing
the breadboard to probe a test structure directly. Below the header sits
the 6$\times$6 DoE bond-pad array at 3.5~mm pitch, with the EIS
calibration block in the same horizontal band: bare OPEN/SHORT pads and a
100~$\Omega$ 0.1\% reference resistor that doubles as the LOAD reference.
The middle strip is the test-structure zone: three TLM ladders at
$W \in \{0.25, 0.5, 1.0\}$~mm with gaps of 200, 300, 500, 1000, 2000, and
4000~$\mu$m, plus four VDP cloverleaves at $W \in \{1.0, 0.5, 0.25, 0.15\}$~mm.
The smallest TLM gap stays above the standard-pool minimum at both Aisler
and Eurocircuits, so the ladders fab in the same run, on the same ENIG
surface, as the LED-side traces. The bottom strip carries the eight WL-SFCC LEDs (D1--D8) with the
four NTCs interleaved between them, the DCL6 and DCL12 daisy chains
(wired through the K$_R$ cathode), and the 32-pin south header that
pre-routes every D1--D8 signal out to a ribbon cable.

Design rule budget: 0.20~mm minimum copper track, 0.30~mm minimum copper
clearance (1.3$\times$ and 2$\times$ over the 0.15~mm standard-pool minimum
at both Aisler and Eurocircuits), 0.30~mm minimum drill, 0.15~mm via
annular ring. DRC returns zero violations and zero unconnected items. ENIG
plating (Ni 4~$\mu$m, Au 0.075~$\mu$m) is non-negotiable: every probe pad
has to be gold for reliable probe contact, and the customer-bonded LEDs
need a gold surface to wet against. Component count: 130 footprints in
total, 7 assembled by the fab (4 NTCs, the reference resistor, and two
32-pin header strips) and 123 left for the customer (the 26 LEDs bonded in
the cleanroom and 97 bare-ENIG test lands).

The companion KiCad schematic captures the 36 electrically active
components (the 26 LEDs, 4 NTCs, the resistor, 3 EIS test points, and the
two connectors) and the 164 named nets. The remaining 123 footprints are
isolated single-pad test structures; they appear on the PCB and in the BOM
but adding them to the schematic would clutter it without information, so
they are documented through the on-board silk and the project README
instead.

\section{Characterization Methods}

\subsection{Forward-voltage thermometry (V$_F$-TSP)}

A diode's forward voltage at a fixed, low sense current falls roughly
linearly with junction temperature over a wide range
\cite{pangallo2018direct}. The slope, $S \equiv -\partial V_F / \partial
T_J$, is constant enough to invert for $T_J$ in real time. For a sense
current $I_S \ll I_{op}$,
\begin{equation}
  T_J(t) \;=\; T_{J,0} \;-\; \frac{1}{S}\bigl[V_F(t) - V_{F,0}\bigr],
  \label{eq:vftsp}
\end{equation}
where $V_{F,0}$ is the forward voltage at the calibration temperature
$T_{J,0}$. The LED $V_F$ is read across the four bonded contacts of the
device under test via the south header. The substrate reference comes from the four
NTCs (TH1--TH4, TDK NTCG104BH103HT1, $R_{25}=10$~k$\Omega$, $B_{25/85}=3380$~K
\cite{tdk_ntcg104}) interleaved between the LED pairs and read through
the north header. The Steinhart-B equation maps NTC resistance to
temperature:
\begin{equation}
  \frac{1}{T} \;=\; \frac{1}{T_0} \;+\; \frac{1}{B}\,\ln\!\left(\frac{R}{R_0}\right),
  \label{eq:ntc}
\end{equation}
with $T_0 = 298.15$~K, $R_0 = 10$~k$\Omega$. To avoid self-heating bias
the sense current is pulsed (100~$\mu$A, 1~ms, 10\% duty), following the
pulsed differential V/I technique of Roscam Abbing and Pertijs
\cite{roscamabbing2011led}, which also has the advantage of requiring
calibration at only a single temperature. The bond-joint thermal resistance is then the
steady-state ratio of the junction-to-substrate temperature difference to
the dissipated power:
\begin{equation}
  R_{th,bond} \;=\; \lim_{t \to \infty}\frac{T_J(t) - T_{NTC}(t)}{P_{op}}.
\end{equation}

\subsection{Electrochemical impedance spectroscopy (EIS)}

EIS sweeps a 10~mV AC excitation from 10$^{-1}$~Hz to 10$^{6}$~Hz and
records the complex impedance $Z(j\omega) = Z' + jZ''$. The Nyquist plot
$Z''(Z')$ separates the series bond resistance (the high-frequency
intercept, $Z' \rightarrow R_s$ as $\omega \rightarrow \infty$) from the
diode's parallel RC dynamics (the low-frequency semicircle). For the
standard LED equivalent circuit ($R_s$ in series with $R_p \parallel C_j$),
\begin{equation}
  Z(j\omega) \;=\; R_s \;+\; \frac{R_p}{1 + j\omega R_p C_j}.
  \label{eq:eis}
\end{equation}
EIS is only as good as its calibration. The board carries three on-PCB
references: \texttt{EIS\_OPEN} (two isolated 1.27~mm gold pads,
$Z \rightarrow \infty$), \texttt{EIS\_SHORT} (paired pads joined by a
solder bridge, $Z \rightarrow 0$), and \texttt{EIS\_LOAD} (the 100~$\Omega$
0.1\% reference resistor, Yageo RT0603BRB07100RL, TCR 10~ppm/K
\cite{yageo_rt0603}). The resistor
pads are oversized so they double as four-wire Kelvin probe lands.

\subsection{Transmission line model (TLM)}

TLM gives sheet resistance $R_{sh}$ and specific contact resistivity
$\rho_c$ from one set of resistance measurements between successive
finger pairs at known gaps $d$. For $N$ identical contacts of width $W$
and characteristic transfer length $L_T$,
\begin{equation}
  R_{tot}(d) \;=\; \frac{R_{sh}}{W}\,d \;+\; 2\,R_c,
  \quad
  R_c \;=\; \frac{R_{sh}\,L_T}{W}\coth\!\left(\frac{L}{L_T}\right),
  \label{eq:tlm}
\end{equation}
where $L$ is the contact length. A linear fit of $R_{tot}$ vs $d$ gives
$R_{sh}$ from the slope and $2 R_c$ from the intercept; $\rho_c$ then
follows from $\rho_c = R_c \cdot W \cdot L_T \cdot \tanh(L/L_T)$. The
three widths in the ladder set make the transfer length's width
dependence directly measurable.

\subsection{Van der Pauw (VDP)}

A symmetric cloverleaf gives $R_{sh}$ directly, with no contact-geometry
correction, from the implicit relation
\begin{equation}
  \exp\!\left(-\pi\,\frac{R_A}{R_{sh}}\right) \;+\;
  \exp\!\left(-\pi\,\frac{R_B}{R_{sh}}\right) \;=\; 1,
  \label{eq:vdp}
\end{equation}
where $R_A$ and $R_B$ are transverse four-point resistances measured
at 90$^\circ$ rotation. For $R_A \approx R_B \equiv R$, this collapses to
$R_{sh} = (\pi / \ln 2)\,R$. The four cloverleaves cross-check the TLM
slope and surface any width-dependent edge effects.

\subsection{Daisy-chain bond yield}

DCL6 and DCL12 put 6 and 12 LEDs in series through the K$_R$ cathode. One
I-V sweep across the endpoints (\texttt{DCL$n$\_IN}/\texttt{OUT}) exercises
$2N$ bonds per chain. A bad bond shows up as a discontinuity in $I(V)$
or a chain $V_F$ that overshoots $N \cdot V_{F,\text{nominal}}$. For
WL-SFCC red at 10~mA, $V_{F,R} \approx 2.05$~V \cite{wurth_wlsfcc}, so the
DCL12 threshold is roughly 25~V at 10~mA. The K$_G$ and K$_B$ cathodes of
every chain LED route to isolated probe pads, so a failure can be
localized to a specific die and a specific color rather than blamed on
the whole chain.

\section{Tooling and Workflow}

\textbf{Software.} KiCad 9.0.8. The \texttt{.kicad\_pcb} is written
programmatically by a Python script
(\texttt{tools/generate\_pcb\_text.py}) rather than placed through the
GUI. Fab outputs come out of \texttt{kicad-cli}: gerbers and drill
(required for Eurocircuits, optional for Aisler since Aisler reads the
native \texttt{.kicad\_pcb}), pick-and-place CSV, top and bottom review
PDFs, a 3D STEP model, and the fab-neutral BOM
(\texttt{tools/gen\_fab\_bom.py}) which parses identically at Aisler
Beagle and Eurocircuits.

\textbf{Fabrication.} Either Aisler or Eurocircuits can produce the board
on a 2-layer FR-4 1.55~mm pool with ENIG. The fab solders the 4 NTCs,
the reference resistor, and the two 32-pin header strips (cut from
1$\times$40 stock). The 26 WL-SFCC LED footprints are marked \emph{do
not populate} in the BOM and called out explicitly in the order notes,
since the LED bonding is the research subject and has to happen in the
TU~Delft cleanroom under controlled paste, reflow, and die-bonder
conditions. Three boards delivered, fully assembled apart from the LEDs,
costs roughly \euro115--125 at Aisler or \euro135--160 at Eurocircuits.

\textbf{Bonding.} LED placement runs on the Tresky T-3000-PRO. Its
95~$\times$~95~mm work envelope fits the 93~$\times$~93~mm board with 1~mm
of margin per side. Solder paste goes down through a 100~$\mu$m laser-cut
stencil keyed to the WL-SFCC pad layout (four corner pads, each
0.4~$\times$~0.4~mm at 0.8~mm pitch \cite{wurth_wlsfcc}). Reflow follows
IPC J-STD-020E with a peak between 245 and 260~$^\circ$C, the exact
profile depending on the paste vendor's datasheet.

\textbf{Measurement.} Keithley 2450 SourceMeter for V$_F$-TSP and DC I-V.
Solartron 1260A frequency response analyzer with a 1296A dielectric
interface for EIS. HP4156 parameter analyzer for the TLM and VDP fits.
T-type thermocouples soldered to the four \texttt{TC$n$} gold lands log
in-situ reflow temperature, which is useful when a paste lot starts
behaving oddly. Probe access is either through 1.27~mm Kelvin tips on the
\texttt{PP\_*} pads or through ribbon-cable breakouts on the 32-pin
headers.

\section{Solder-Paste Comparison}

The motivating experiment is a comparison of four commercial solder pastes
on identical hardware: same LED part, same substrate, same reflow profile
(within vendor spec), same characterization protocol. The four candidates:
\begin{enumerate}
  \item \textbf{SAC305} (Sn 96.5\% / Ag 3.0\% / Cu 0.5\%), the industry baseline.
  \item \textbf{SAC0307}, a low-silver variant. Cheaper, slightly worse on
        thermal cycling, similar V$_F$ drop.
  \item \textbf{Au-Sn eutectic}, the canonical micro-LED flip-chip
        bonding alloy, with reported low post-bond leakage current and
        high shear strength but a strong sensitivity to bonding
        temperature \cite{yin2024ausn}.
  \item \textbf{Polymer-reinforced solder paste}, an impact-tolerant
        chemistry developed for laser-assisted mass transfer that
        preserves solder-joint reliability while absorbing chip-drop
        energy \cite{ji2023polymer}.
\end{enumerate}
For each paste, a three-board batch (1 trial + 1 real + 1 spare, matching
Aisler's bundle size and convenient at Eurocircuits too). Per board,
measure: chain yield ($N_{ok}/N$ across
both DCL6 and DCL12), per-LED V$_F$ at 10~mA, $R_{th,bond}$ from the
V$_F$-TSP transient, $R_s$, $R_p$, and $C_j$ from a fit of EIS data to
(\ref{eq:eis}), and $\rho_c$ from a fit of TLM data to (\ref{eq:tlm}).
Cross-board variance is the headline number, since it captures how wide
each paste's process window actually is.

The same hardware supports a few other experiments. The 6$\times$6 DoE
bond-pad array (plain, minis, rounded variants) quantifies capillary
self-alignment yield against pad geometry. The four TC pads let the
reflow profile be measured and iterated against the paste datasheet. The
daisy chains, driven with a programmable current source, run accelerated
thermomechanical fatigue on a known set of bonds.

\section{Conclusion}

This v2 board puts four characterization methods (V$_F$-TSP, EIS, TLM,
VDP) and a daisy-chain go/no-go test on a single 93~$\times$~93~mm
substrate, so one cleanroom session produces a self-consistent measurement
of bond resistance, contact resistivity, sheet resistance, and thermal
resistance from the same hardware. The board is fab-ready on the
standard pool at both Aisler and Eurocircuits with ENIG plating, with the
design rules cleared at twice the published manufacturing minima. The
schematic, BOM, and tool chain are committed alongside this report so
anyone with KiCad and an account at either fab can re-fab a copy. Part 2 will report the first measurement
results from the four-paste comparison once the boards land and the
cleanroom session is done.

\section*{Acknowledgment}

This work builds on the v1 board of A.\ Abdelwahab \cite{abdelwahab2025ectc}.

\bibliographystyle{IEEEtran}
\bibliography{refs}

\end{document}

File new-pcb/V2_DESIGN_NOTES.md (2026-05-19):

# v2 PCB — Design Notes (v3 iteration, delivered)

> **As-built note (May 2026):** Notes below were written for the v4.0.7 layout (192 footprints). The fab-ordered version has been simplified: 64 single-pin headers consolidated into 2 multi-pin strips, F.Paste/B.Paste gerbers emptied, 26 LED footprints marked DNP. **All bare-pad test structures (BondPad_DoE, TLM, VDP, Probe_1.27mm, TC_Pad_1mm, Fiducial_1mm) remain on the board as bare ENIG gold lands** — they're flagged `exclude_from_bom` + `exclude_from_pos_files` so Eurocircuits ignores them as parts. Current as-built footprint count: **130** (4 NTC + 1 R + 2 strips + 26 LEDs DNP + 97 bare-pad test structures). See `FABRICATION_ORDER.md` and `README.md` for the as-built scope.

What's actually shipped in `tud-microled-v2.kicad_pcb`. Companion to
`PCB_DESIGN_PLAN.md` (spec) and `ELECTRICAL_CHARACTERIZATION.md` (test plan).

---

## Status: **fab-ready** ✅

| Check | Result |
|---|---|
| KiCad version | 9.0.8 (file format 20241229) |
| Board | **100 × 100 mm**, 2-layer FR-4, 1.6 mm |
| Surface finish | ENIG (Ni 4 µm / Au 0.075 µm) |
| Board size | **93 × 93 mm** (under Tresky T-3000-PRO envelope of 95 × 95 mm) |
| **DRC violations** | **0** |
| **Unconnected pads** | **0** |
| Footprints | 194 (incl. 26 WL-SFCC LEDs, 4 NTCs, 1 EIS load R, 64 header pins) |
| Headers | 32 + 32 = 64 pins, both rows aligned to same X grid for breadboard mating |
| Calibration | EIS CAL pads added in v4.0 (OPEN / SHORT / 100Ω LOAD) for full Nyquist calibration |
| Designer | **Daniel Tyukov · student no. 5714699 · ET4277 / ET4391** |

Generated procedurally by `tools/generate_pcb_text.py` (fully reproducible).
Re-run any time to regenerate from scratch.

---

## What's on the board

### Front side (F.Cu + F.SilkS)

| Section | Y range | Contents |
|---|---|---|
| Title block | 3 – 11 | 3 zones: TUDelft mark / project + version + size / Daniel Tyukov + student no. + course codes |
| TIER-2 NORTH header | 13.5 | 30 × 2.54 mm PTH pins, **user-jumperable** |
| DoE BOND-PAD array | 17 – 43 | 6 × 6 isolated test pads at 3.5 mm pitch; plain → +4 minis → rounded; LEGEND box on right |
| TLM LADDERS | 45 – 58 | 3 banks (W = 0.25 / 0.5 / 1.0 mm) × 7 fingers × spacings 5/10/20/50/100/200 µm |
| VAN DER PAUW | 59 – 67 | 4 cloverleaves (W = 1.0 / 0.5 / 0.25 / 0.1 mm) |
| LED DAISY CHAINS | 68 – 77.5 | N=6 + N=12 WL-SFCC LEDs in series via RED chain (A → K_R). 2N bonds tested per chain. K_G / K_B isolated per-LED (probe directly on pad). IN/OUT probe pads at each chain end. |
| WL-SFCC LEDs | 79.5 – 86.7 | 8 × Würth 0404 super-flat RGB; A bus on B.Cu |
| TIER-2 SOUTH header | 89 | **32 × 2.54 mm PTH pins, pre-wired to all 32 LED signals** |
| mm ruler | 93.5 | 0–80 mm with major + minor ticks |

### Back side (B.SilkS)

| Section | Y range | Contents |
|---|---|---|
| Title block | 3 – 12 | TUDelft mark + project name + date |
| FABRICATION | 16 – 36 | Stack-up, finish, mask, clearance/trace specs |
| ASSEMBLY | 38 – 58 | Paste, stencil, bonder, reflow, metrology toolchain |
| DESIGNER | 60 – 72 | Daniel Tyukov, student #, courses, ECTM + ITEC, prior work attribution |
| TIER-2 SOUTH PINOUT | 73.5 – 86 | Pin→LED mapping: `1-4 D1, 5-8 D2, ... 29-32 D8` (A, KG, KB, KR) |

---

## Routing summary

### South header — pre-wired (F.Cu)

**32 of 32 pins routed.** Each pin → its assigned LED probe pad through a 3-segment
Manhattan route:
- Vertical from pin pad → 4-lane horizontal jog → vertical to probe pad
- 4 horizontal lanes (Y = 87.7 / 87.3 / 86.9 / 86.5 mm) — one per role (A / KG / KB / KR)
- All on F.Cu, lanes sit in the 2 mm gap between header pad keepout (y > 88.15) and probe pad top (y < 86.135)

**Common-anode B.Cu bus** ties together all 8 LED A-probe pads via vias at each
A probe, with a horizontal trace on B.Cu at y = 85.5 mm.

### North header — user-jumperable

The 30 north pins are pre-assigned to specific VDP / DC / TLM nets in the
pin pad's NET field, but **no copper traces are routed** to those targets.
The user solders a 0.1" header into the holes and runs jumper wires from
the header pins to the Tier-1 probe pads of whichever structure they want
to access.

Why not pre-route? Several attempts to route 26 long B.Cu traces from
2.54 mm-pitch header pins to scattered VDP/DC/TLM contacts (some at sub-mm
spacing per VDP) introduced unavoidable clearance violations: pin pitch
(2.54 mm) is barely larger than via diameter + clearance, and the per-VDP
contact spacing means horizontal jogs collide with adjacent verticals.

Freerouting got 24 of 26 in one run but was inconsistent across runs.
Manual routing with per-zone fanout reached down to ~46 violations
(crossings between adjacent pin verticals and horizontals) but never to
zero. Deferring to v3.1 (4-layer board with B.Cu fanout bus zone).

---

## Design rules

| Rule | Value |
|---|---|
| Clearance | 0.15 mm |
| Min track width | 0.15 mm |
| Default track width | 0.20 mm |
| Via | 0.6 mm Ø / 0.3 mm drill |
| Min via | 0.45 / 0.20 mm |
| Min hole | 0.20 mm |

Matches both Aisler standard pool and Eurocircuits Class-4 capability.

---

## Fab outputs (in `fab/`)

| File | Purpose |
|---|---|
| `gerbers/` | Per-layer Gerber files (X2 format) + drill `.drl` + `.gbrjob` |
| `tud-microled-v2-gerbers.zip` | Gerber bundle — required for Eurocircuits; optional for Aisler (Aisler reads `.kicad_pcb` natively) |
| `tud-microled-v2.step` | 3D model for mechanical fit |
| `tud-microled-v2-top.pdf` | Top-side review PDF (F.Cu + F.Mask + F.SilkS + Edge.Cuts) |
| `tud-microled-v2-bot.pdf` | Bottom-side review PDF (mirrored, B.Cu + B.Mask + B.SilkS + Edge.Cuts) |
| `tud-microled-v2-pos.csv` | Pick-and-place position file (mm, both sides) |
| `tud-microled-v2-bom.csv` | BOM (LEDs + optional headers) |
| `preview/board_top.png` | 1800×1800 top 3D render |
| `preview/board_bottom.png` | 1800×1800 bottom 3D render |

---

## How to use the south header

1. Solder a 32-pin 0.1" male header strip into the south through-holes (5 min).
2. Plug a 32-pin ribbon cable.
3. The other end maps as follows:

| Cable wire | Pin | Signal |
|---:|---:|---|
| 1 | 1 | `LED_VCC` (D1 A) |
| 2 | 2 | `LED1_KG` |
| 3 | 3 | `LED1_KB` |
| 4 | 4 | `LED1_KR` |
| 5 | 5 | `LED_VCC` (D2 A — redundant) |
| 6 | 6 | `LED2_KG` |
| ⋮ | ⋮ | (pattern repeats for D1…D8) |
| 32 | 32 | `LED8_KR` |

Every 4-pin block = 1 LED. Pin 1 of each block is anode (= common LED_VCC).

---

## Iteration log

| Iter | DRC | Highlight |
|---|---:|---|
| 8 (first routing attempt) | 1802 | Pad SetPosition() bug — all pads stacked at (0,0) |
| ... | ... | (geometric layout convergence) |
| 16 (south routing v2) | 0 | South pre-wired D1–D7, north user-jumperable |
| 19 (silkscreen polish) | 0 | TIER-2 SOUTH PINOUT box on back, all 8 LEDs documented |
| 22-25 (north routing attempts) | 46–293 | Tried manual + freerouting; both hit fundamental geometric limits |
| 27 | 0 | South to D1-D8 (32 pins), north user-jumperable, silkscreen polished |
| 28 (v3.6) | 1 cosmetic | Dummy-die DC replaced with WL-SFCC LED chains (N=6 + N=12, R-series) |
| 29 (v3.7) | 0 | Compressed to 95×95 mm, 4 north pins (1/10/22/30) routed to chain endpoints |
| 30 (v3.8) | 0 | 32-pin north header aligned with south, silk circles on routed pins (pins 3/10/19/32) |
| 31 (v3.9) | 0 | Compressed to 93×93 mm with breathing room, ruler restored, TH1-4 labels relocated |
| 32 (v3.9.1) | 0 | Back-side PINOUT compacted to single line (no truncation, no ambiguous O→U) |
| **33 (v4.0 — delivered)** | **0** | **EIS CAL section added (OPEN/SHORT/100Ω LOAD) — full Nyquist calibration capability for impedance spectroscopy of bonded LEDs** |

---

## What's NOT in this build

- North header pre-routed traces — see "Routing summary" above
~~- Schematic — research test boards traditionally ship PCB-only; can be
  added in a future iteration by reverse-engineering the placement script~~

**Update (v4.0.7):** Single-sheet A2 schematic added — see
`tud-microled-v2.kicad_sch` and `fab/tud-microled-v2-schematic.pdf`.
Generated via KiCad MCP tools, linked to the PCB by matching component
references and footprint paths. 36 components placed (26 LEDs + 4 NTCs +
1 resistor + 3 test points + 2 × 32-pin connectors), 129 net labels
snap-connected to pin endpoints, 24 NC markers on user-jumperable north
pins. ERC residual: 21 expected "single-pin net" warnings on EIS probe
test points and LEDn_{KG,KB} south-header labels (by design — these nets
go to PCB probe pads only, not other components).

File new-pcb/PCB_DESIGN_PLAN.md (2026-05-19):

# Micro-LED Bonding Characterization PCB — v2 Design Plan

> **As-built note (May 2026):** This document captures the full original design scope (LED daisy chains + DoE bond-pad array + TLM/VDP test structures + V_F-TSP probe pads). The version sent to fab (Eurocircuits, "Place loose") was **simplified to LED-bonding only** — bare-pad test structures (BondPad_DoE, Probe_1.27mm, TC_Pad_1mm, TLM, VDP, Fiducial_1mm) were removed from the layout, and the 64 individual single-pin headers were consolidated into 2 multi-pin 1×32 strips. Remaining footprints: 4 NTC + 1 R + 2 header strips + 26 LEDs (DNP). See `FABRICATION_ORDER.md` for the as-built fab spec.

**Status:** Draft. Owner: Daniel (PCB) + Ahmed (process). Target tape-out: TBD.
**Predecessor:** `old-pcb/Electrical test + LED-no solder.kicad_pcb` (ECTC 2025).
**Companion docs:** `../PROJECT_DETAILS.md`, `ELECTRICAL_CHARACTERIZATION.md` (measurements + ports + lab tools), `../docs/ECTC-2025-published Ahmed Abdelwahab.pdf`.

---

## 1. Goals

The v2 board must let us answer the questions that v1 raised but could not
fully close. In priority order:

1. **Reduce die tilt to < 0.5°** on **every** bond pad — by adopting the
   *"four-corner mini-pad"* geometry universally (it eliminated tilt on the
   limited subset where v1 used it).
2. **Quantify the geometry → tilt relationship** with a clean Design Of
   Experiments (DoE): pad shape (square / rounded-corner / circle / cross),
   corner radius (R = 0 / 50 / 100 / 200 µm), and mini-pad spacing.
3. **Measure contact resistivity ρ_c with a proper TLM ladder** — fixed
   finger width, **swept contact-spacing** (5/10/20/50/100/200 µm). The v1
   TLM had only a fixed spacing.
4. **Verify electrical performance on real RGB LEDs** using the Würth WL-SFCC
   super-flat 0404 (`150044M155220`) — the part we already have in the BOM
   and whose KiCad library is now vendored in `library/`.
5. **Be tooling-ready out of the box** — fiducials for the Tresky bonder and
   eC-stencil-mate, silkscreen IDs on every structure, separate paste-layer
   file so the stencil can be re-cut without re-tooling the PCB.

---

## 2. Lessons from v1 (`old-pcb/`)

| v1 behaviour | v2 response |
|---|---|
| Die tilt 5°–8° on plain square pads | Apply 4 corner mini-pads (0.5 × 0.5 mm at the corners of each 1 × 1 mm bond pad) everywhere |
| Tilt only solved on one pad geometry | Sweep geometry: square / rounded / circle / cross + radius sweep |
| TLM fingers fixed | TLM ladder with 6 contact spacings (5/10/20/50/100/200 µm) per finger width |
| No structure labels on silkscreen | Every structure carries an ID ("BP-Sq-R0-A1", "TLM-W0.5-S20", "DC-N6-1", "VDP-1", "LED-R1C1") |
| 165 footprints with empty references | Keep references *populated* but parked off-board on the F.Fab layer — no silkscreen text on bond/probe pads (keeps Keyence scans clean) |
| No fiducials | 3 × 1 mm copper fiducials (top-left / top-right / bottom-right asymmetric) + 4 × 1 mm corner fiducials on the Eco1.User layer for the stencil printer |
| Solder paste off-board | Keep that. Generate F.Paste apertures procedurally and provide both "with stencil" (paste defined) and "no stencil" (current behaviour) variants |
| 165 manually-placed footprints, hand routed | v2 footprints generated from a CSV table → KiCad scripting (see §11) so DoE expansion is just a CSV row |

---

## 3. Board outline & stack-up

- **Outline:** keep 58.75 × 61.51 mm (drop-in compatible with the bonder
  fixture and the stencil frame). Slightly chamfered top-left corner for
  unambiguous orientation.
- **Stack-up:** 2-layer FR-4, 1.6 mm finished thickness, 35 µm (1 oz) copper.
  Top side carries all bond pads and test structures; bottom side carries
  routing only.
- **Solder mask:** matte black or matte green, **opening = pad + 0.0 mm**
  (defined by the pad, NSMD where possible to reproduce v1 behaviour). The
  paper relied on the contact-angle of solder on ENIG (~18°) — keep the
  geometry identical.
- **Surface finish:** **ENIG** (Ni 4–5 µm / Au 0.05–0.12 µm) — paper §III-B,
  Fig. 4(b). Quote both lead-free and RoHS to the fab.
- **Silkscreen:** white, 0.15 mm line / 1.0 mm height; **none** on bond pads
  or probe pads — only in dedicated label rows between rows of structures.

---

## 4. Test-structure inventory (v2 target)

For every structure, give it an on-silkscreen ID matching the table below.
Coordinates are notional — final placement is done after the structure-by-
structure layout.

### 4.1 Main bond-pad DoE array (centre of board, ~30 × 30 mm region)

A 10 × 10 grid (100 sites) at **2.0 mm pitch** centre-to-centre — fits in
20 × 20 mm. ID format: `BP-<shape>-<R>-<row><col>`.

| Site count | Shape | Size (mm) | Corner radius (µm) | Mini-pad corners? |
|---:|---|---|---|---|
| 16 | Square plain | 1 × 1 | 0 | No (control / reference)  |
| 16 | Square + minis | 1 × 1 | 0 | **Yes** (4 × 0.5 × 0.5 mm)|
| 16 | Square rounded | 1 × 1 | 50 | Yes |
| 16 | Square rounded | 1 × 1 | 100 | Yes |
| 16 | Square rounded | 1 × 1 | 200 | Yes |
| 8 | Circle | Ø 1.0 | — | Yes (4 × 0.5 × 0.5 mm at ±45°) |
| 8 | Cross / "+" | 1 × 1 (200 µm w) | — | No |
| 4 | Reference 2 mm | 2 × 2 | 0 | No |

Each site is **electrically isolated** — they connect to two **1.27 × 1.27
mm probe pads** on the side of the board via 0.2 mm traces, so you can
do 4-wire die-shear-and-resistance after bonding.

### 4.2 Daisy chains (north edge of board)

- 3 chains: **N = 6 / 12 / 24** dies in series. v1 had only N = 6.
- Chain ID: `DC-N6-1`, `DC-N12-1`, `DC-N24-1`.
- Bond pad geometry: 1 × 1 mm + 4-corner-mini, **same** as the DoE control
  to make the resistance comparable.
- Each chain terminated by two 1.27 × 1.27 mm probe pads (4-wire access:
  two more probe pads tap the chain mid-point for split measurement).

### 4.3 Van der Pauw (VDP) (west edge)

- 4 VDP cloverleaf structures with 1.0 / 0.5 / 0.25 / 0.1 mm arm width to
  cross-check sheet-resistance scaling.
- ID: `VDP-W1`, `VDP-W0.5`, `VDP-W0.25`, `VDP-W0.1`.

### 4.4 TLM ladders (south edge)

- 3 ladder banks at finger width **W = 0.25 / 0.5 / 1.0 mm**.
- Each bank has 7 identical fingers with **contact spacings** 5 / 10 / 20 /
  50 / 100 / 200 µm (6 gaps between 7 fingers).
- Each finger terminates in a 1.27 × 1.27 mm probe pad.
- ID: `TLM-W0.5-S20` = bank W = 0.5 mm, spacing 20 µm.

### 4.5 RGB LED test row (east edge)

- 8 footprints of **D_Wurth_WL-SFCC-0404superflat** (`150044M155220`).
- 4 wired so all 8 share **anode + 3 individually accessible R/G/B cathodes**
  → smoke-test the assembly visually (just like Fig. 23b of the paper).
- 4 wired into a "small daisy chain" through the LED bodies (anode of LED N
  to common cathode of LED N+1) so a single bonded-joint failure breaks the
  light. Useful go/no-go.
- ID: `LED-R1C1` … `LED-R1C8`.

### 4.6 Connectors / probe access (3-tier strategy)

See `ELECTRICAL_CHARACTERIZATION.md` §4 for the full rationale. Summary:

- **Tier 1 — 1.27 mm probe pads**: on every structure, 4-wire where it
  matters (silkscreened FH/SH/SL/FL). Manual probe station.
- **Tier 2 — 2.54 mm pin-header rows**: two 40-pin rows along N/S edges,
  for soldering 0.1" headers when running repeated / lifetime tests.
- **Tier 3 — Edge / FFC connector**: optional 30-pin connector for
  hot-swap into a benchtop SMU fixture.

### 4.7 Calibration / metrology assists

- 4 × **1.0 mm copper fiducials** (filled circles, 2 mm solder-mask opening)
  near the corners — for the stencil printer and the bonder.
- 1 × asymmetric **L-shape fiducial** top-left so orientation is
  unambiguous even with the board rotated.
- A **graduated mm/µm ruler** along the south edge etched into copper for
  Keyence calibration.

---

## 5. Pad-geometry library (the heart of the DoE)

All bond pads are 1 × 1 mm reference area unless stated. Variations:

```
            Plain        Rounded R = X        +Corner-minis      Circle
            ┌─────┐      ╭─────╮              ┌─────┐ ◾◾         ┌─────╮
            │     │      │     │              │     │            │     │
            │     │      │     │              │     │            │     │
            └─────┘      ╰─────╯              └─────┘ ◾◾         ╰─────╯
```

- **Mini-pad** dimensions per paper: 0.5 × 0.5 mm, placed so their inner
  edge sits 100 µm outside the main pad edge at the corner. Connected to
  the same net as the main pad with a 0.15 mm trace under solder mask.
- **Cross / "+"** uses arm width 0.2 mm; envelope still 1 × 1 mm.
- **Circle** Ø = 1.0 mm (same area envelope, ~78 % of pad copper area).

Document each entry as its own KiCad footprint so the DoE layout is just
placing footprints from the project library.

---

## 6. Schematics & nets

Every structure is its own self-contained sub-schematic. Net naming:

- Bond-pad DoE: `BP_<ID>_P1`, `BP_<ID>_P2` (probe-side high / low).
- Daisy chain: `DC<N>_IN`, `DC<N>_OUT`, `DC<N>_MID`.
- VDP: `VDP_<W>_A` … `VDP_<W>_D` for the four cloverleaf contacts.
- TLM: `TLM_<W>_F1` … `TLM_<W>_F7` for the seven fingers.
- LED row: `LED_<col>_A` (anode), `LED_<col>_KR/KG/KB` (cathodes).

Probe-pad pitch: **2.54 mm** centre-to-centre on a regular grid along the
left/right edges so a Pogo-pin fixture can be used in addition to the
manual probe station.

---

## 7. Solder-paste / stencil strategy

Keep v1's "**-no solder**" convention: the master `.kicad_pcb` does **NOT**
define paste apertures, and the stencil is cut from a separate Gerber set.

- Primary stencil: **100 µm laser-cut SS**, aperture = pad area × 0.9
  (10 % reduction is paper §III-A's working value, ratio matches TS391LT
  Type 4 mesh).
- Secondary stencil: **50 µm**, aperture = pad area × 1.0 (for the smallest
  test pads where 100 µm starves the joint).
- The Gerber set ships with **two** F.Paste layers for each variant
  (`*.gtp`) — produced by a Python script in `tools/gen-paste.py` (see
  §11) so the master never gets two paste layers in conflict.

---

## 8. Bill of Materials (PCB-side)

The board itself only has the LEDs as active parts; everything else is
empty pads.

| Designator | Part | Qty | Source | Notes |
|---|---|----:|---|---|
| D1 … D8 | Würth WL-SFCC 150044M155220 (super-flat RGB) | 8 | DigiKey / Würth | Use vendored footprint in `library/` |
| — | TS391LT Sn42/Bi57.6/Ag0.4 solder paste T4 (jar) | 1 | Chip Quik | Same as paper |
| — | 100 µm SS stencil (eC-stencil-mate frame) | 1 | Eurocircuits | Order with the PCB |
| — | 50 µm SS stencil (secondary) | 1 | Eurocircuits | Optional, for smallest pads only |
| — | 1 mm² test dies (Cu / Au / Ag finish on Si) |  ~60 | EKL clean-room | Wafer-diced 1 × 1 × 0.525 mm |

The dies are fabricated, not bought; spec is in paper §III-B.

---

## 9. Fab & assembly flow

1. **PCB fab** (Eurocircuits, lead-time 5 d): 2-layer FR-4, 1.6 mm, ENIG,
   black mask, **white silk except on metrology areas**, edge-rail tabs
   (3 × 1 mm) for the bonder fixture.
2. **Stencil fab** (Eurocircuits, same lot): 100 µm SS stencil, eC-stencil-
   mate compatible frame.
3. **Paste print** (clean-room, ISO 7): manual print on the eC-stencil-
   mate, inspect 100 % with the **Keyence VK-X250** (3D paste volume + footprint).
4. **Die prep** (EKL): wafer-dice the test dies, verify surface finish
   thickness with ellipsometry.
5. **Die bonding** (Tresky T-3000-PRO):
   - Pick-and-release on the DoE pads (the main experiment).
   - Pick-and-place at 1 MPa on a control row (so we have within-board
     reference).
   - 8 LEDs placed by the same Tresky on the LED row.
6. **Reflow** (hot-plate on the die bonder, paper §III-A reflow profile):
   RT → 90 °C @ 0.72 °C/s → 130 °C @ 0.44 °C/s → 138 °C @ 0.27 °C/s →
   165 °C @ 0.9 °C/s → unforced cooldown.
7. **Geometric metrology** (Keyence VK-X250): 3D scan every site for BLT
   and tilt (paper §IV).
8. **Electrical** (Summit 11K/12K probe station + Keithley): DC chain,
   VDP, TLM, light-on the LED row.
9. **Mechanical** (Nordson DAGE 4000 Bondtester): die-shear at 500 µm/s on
   each DoE site → strength vs. geometry plot.
10. **Failure analysis** (Keyence VK + SEM/EDS) on failed bonds.

---

## 10. Test & data plan

Output of the experiment is a CSV with one row per bonded site:

```
site_id, shape, R_um, mini_pads, die_finish, mounting_pressure_MPa,
BLT_um, tilt_high_deg, tilt_low_deg, shear_MPa, R_chain_ohm, R_contact_ohm
```

Sample sizes per cell of the DoE matrix:

- **n ≥ 5** per (shape, R, die_finish, pressure) combination → tolerable
  variance on tilt (paper reported ±0.93°–±3.02° per cell at n ≈ 5).
- Two replicate boards per condition → 2× the n above.

The CSV feeds a Jupyter notebook (`tools/analysis.ipynb`) that re-makes
the paper's Fig. 10 / 12 / 13 with the new geometry sweep.

---

## 11. Tooling

- `tools/gen-pads.py` — read a CSV of (id, shape, R, mini_pads, x, y,
  rotation) and emit a `.kicad_mod` per geometry plus a `.kicad_sch` /
  `.kicad_pcb` patch placing them. Idempotent.
- `tools/gen-paste.py` — read the master `.kicad_pcb` and the stencil
  shrink % and emit a F.Paste Gerber. Generated, never edited by hand.
- `tools/check-drc.sh` — run `kicad-cli pcb drc` and fail CI if violations.
- `tools/build.sh` — full pipeline: gen-pads → gen-paste → DRC → Gerber
  export → zip for Eurocircuits.

---

## 12. Risks & open questions

| Risk | Mitigation |
|---|---|
| ENIG-finish lot variation skews TLM ρ_c readings | Order all boards in **one fab lot**; record fab batch ID on silkscreen. |
| 50 µm stencil aperture under-prints below process window | Keep 100 µm as primary; 50 µm is an experimental side study. |
| 4 mini-pads on circle / cross is geometrically ambiguous | Specify mini-pad placement at ±45° (circle) or aligned to arms (cross). |
| Pogo fixture vs. manual probe — pad pitch trade-off | Probe pads at 2.54 mm pitch, manual probe still fits because pad = 1.27 mm.|
| Patent: any IP exposure in publishing this PCB? | Cross-check `docs/patent-published-2024-2026.pdf` before open-sourcing the .kicad_pcb (the pick-and-release **method** is patented; the **PCB test substrate** isn't).|
| ECTC paper used a 5 × 5 LED matrix, v2 uses 1 × 8 | Keep one row of v1-style 5 × 5 on a future v2.1 if Ahmed prefers parity. |

---

## 13. Schedule (placeholder)

| Phase | Calendar weeks |
|---|---:|
| Schematic + custom footprint library | 2 |
| Layout + DRC | 2 |
| Review with Ahmed / Massimo | 1 |
| Fab + stencil order | 1 |
| Receive + incoming inspection | 1 |
| Assembly + metrology + electrical | 3 |
| Write-up | 2 |
| **Total** | **12 weeks** |

---

## 14. Deliverables

When this plan is executed, the `new-pcb/` folder should contain:

```
new-pcb/
├── PCB_DESIGN_PLAN.md                    ← this file
├── README.md                             ← getting started
├── library/                              ← vendored Würth + custom DoE footprints
│   ├── symbols/LED_Wurth_WL-SFCC.kicad_sym
│   ├── footprints/LED_SMD_Wurth.pretty/...
│   ├── footprints/BondPads_DoE.pretty/   ← custom (generated)
│   └── 3dmodels/...
├── tud-microled-v2.kicad_pro             ← KiCad project
├── tud-microled-v2.kicad_sch             ← top-level schematic
├── tud-microled-v2.kicad_pcb             ← layout
├── tools/
│   ├── gen-pads.py
│   ├── gen-paste.py
│   ├── check-drc.sh
│   └── build.sh
├── fab/                                  ← Gerbers + drill + paste, zipped per variant
│   ├── tud-microled-v2-PCB.zip
│   ├── tud-microled-v2-stencil-100um.zip
│   └── tud-microled-v2-stencil-50um.zip
└── data/
    ├── doe-matrix.csv                    ← drives gen-pads.py
    ├── results.csv                       ← post-experiment dataset
    └── analysis.ipynb
```

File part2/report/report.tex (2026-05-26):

\documentclass[conference]{IEEEtran}
\IEEEoverridecommandlockouts

\usepackage{cite}
\usepackage{amsmath,amssymb,amsfonts}
\usepackage{graphicx}
\usepackage{textcomp}
\usepackage[official]{eurosym}
\usepackage{xcolor}
\usepackage{booktabs}
\usepackage{siunitx}
\usepackage{url}
\usepackage{hyperref}
\hypersetup{colorlinks=true,linkcolor=blue,citecolor=blue,urlcolor=blue}

\def\BibTeX{{\rm B\kern-.05em{\sc i\kern-.025em b}\kern-.08em
    T\kern-.1667em\lower.7ex\hbox{E}\kern-.125emX}}

\begin{document}

\title{Solder-Paste Printing and Die-Bonder Placement of Micro-LEDs:\\
Capillary Self-Alignment and Die Tilt\\
{\normalsize Course report — ET4277 + ET4391 — Part 2}}

\author{\IEEEauthorblockN{Daniel Tyukov}
\IEEEauthorblockA{\textit{Department of Microelectronics, ECTM + ITEC}\\
\textit{Delft University of Technology}\\
Delft, the Netherlands \\
Student no. 5714699 \;\textbar\; \texttt{d.a.tyukov@student.tudelft.nl}}
}

\maketitle

\begin{figure}[!t]
  \centering
  
\end{figure}

\begin{abstract}
Part 1 described the test board. This part documents the die-bonding
process used to populate it with micro-LEDs and analyses the physics that
governs the result. After completing the EKL safety training and gaining
access to the cleanroom measurement lab, I attended a bonding session run
by Ahmed Abdelwahab, who placed W\"urth WL-SFCC 0404 RGB LEDs on the
existing v1 board and trained me on the workflow. The v2 board from Part 1
was still in fabrication, so the session used the v1 board, which carries
the same LED footprint. The process is deliberately low-tech: solder paste
is printed by hand through a
100~$\mu$m stencil, the dies are placed with a Tresky die bonder, and the
joint forms on a hot plate. The physics worth studying is in the last step.
When the Sn42/Bi57.6/Ag0.4 paste melts, surface tension pulls each die
toward the centre of its pad set, which is convenient, but the same forces
can tilt a die and lock it in a crooked position that never recovers. The
contribution of this report is on the analysis side: it documents the
printing and placement steps, then reads the self-alignment and tilt
behaviour against the capillary self-alignment literature to identify which
process variable matters most. That variable is solder volume. Manual
stencil printing gives no volume metering, and volume is exactly the
quantity the literature ties most strongly to both placement accuracy and
the non-restoring tilt mode.
\end{abstract}

\begin{IEEEkeywords}
micro-LED, die bonding, solder paste, stencil printing, capillary
self-alignment, die tilt, reflow, cleanroom
\end{IEEEkeywords}

\section{Introduction}

The bond joint under a micro-LED is the part of the device that the
electrical tests in Part 1 were built to characterize. Before any of those
measurements can run, the LEDs have to be on the board, and how they get
there decides what the joint looks like. This part documents that step and
analyses why it behaves the way it does.

The plan with Ahmed was straightforward. Part 1 was the design mini-project.
For Part 2, since I am taking ET4277 and ET4391 together, we agreed that he
would assemble LEDs on the die bonder while I documented the workflow and
wrote a literature-based analysis of self-alignment and die
tilt~\cite{abdelwahab2025ectc}. The one hard constraint on the board came
out of this: it has to fit the die-bonder chuck, so the outline was kept at
9.3~cm $\times$ 9.3~cm, inside the 9.5~cm limit.

Solder bonding is attractive for micro-LEDs because it does three things at
once: it mechanically fixes the die, it makes the electrical contact, and,
if the geometry is right, it pulls the die into alignment on its own as the
solder melts~\cite{mastrangeli2017csa}. That last effect, capillary
self-alignment, is the reason this is worth studying rather than just
doing. It can reach micron-level accuracy with no extra
equipment~\cite{vareilles2024solder}, but it is not free of failure modes,
and the dominant one for small dies is tilt~\cite{berthier2015tilt}.

\section{Background: How Micro-LEDs Get onto a Substrate}

A micro-LED is a GaN die between roughly 1 and 100~$\mu$m on a side, grown on
a donor wafer and then moved onto a display or test substrate where it has
to be both mechanically held and electrically
contacted~\cite{li2020masstransfer}. Moving millions of them is the step the
field calls mass transfer, and it is the recognized bottleneck for micro-LED
commercialization~\cite{li2020masstransfer}. The methods split into two
families, and it helps to place where the bonding done in this work sits.

\textbf{Pick-and-place and its variants.} Fine pick-and-place, roll
printing, and laser-assisted transfer move dies deterministically, one or a
batch at a time. They are accurate but serial, and the placement machine's
own accuracy becomes the limit as the die
shrinks~\cite{ji2022selfassembly}. The die-bonder flow in this report is the
prototyping-scale version of this family: a machine picks each die and sets
it on a pad.

\textbf{Self-assembly.} The alternative lets the dies place themselves in
parallel under a field, gravity, or, most relevant here, the capillary force
of a molten alloy~\cite{ji2022selfassembly}. Cho et al.\ pushed this to an
extreme, assembling 19{,}663 GaN micro-LEDs of 45~$\mu$m diameter at 99.9\%
yield in under a minute by shaking them over a substrate patterned with
molten low-melting-point alloy on gold pads, where the capillary force of
the wetting alloy pulls each die onto its site~\cite{cho2019fsa}. The
throughput is enormous because no machine places the dies.

The two families share the physics this report is about. Even in
deterministic placement, once the solder melts the capillary force corrects
the position, so the machine only has to get the die close; self-assembly
takes that same force and makes it do the whole job. Either way the molten
joint aligns the die, and either way the failure mode is the same: the die
can tilt rather than settle flat. Studying self-alignment and tilt on a
die-bonder-placed LED is therefore directly informative for where the field
is heading. The gold (ENIG) pads of the board matter here too, since wetting
of the molten alloy to gold is what generates the aligning
force~\cite{cho2019fsa}.

\section{Cleanroom Access and Training}

Access to the EKL cleanroom needed two things first. I completed the EKL
safety training and was granted access to the cleanroom and its measurement
lab. Ahmed then ran a die-bonding session and trained me on the full flow:
how the stencil and paste are handled, how the Tresky die bonder is set up
and jogged, how the dies are picked and placed, and how the board is
reflowed. The session used Ahmed's existing v1 board (panel E1664138) from
the ECTC 2025 work~\cite{abdelwahab2025ectc}, not the v2 board from Part 1,
which was still in fabrication at the time. The v1 board carries the same
W\"urth WL-SFCC 0404 footprint, so the process and the pad geometry
transfer directly to the v2 board once it arrives. The figures in this
report are from that session; the analysis that follows is my own, built
from the workflow and the self-alignment literature.

\section{Printing and Placement}

\begin{figure}[!t]
  \centering
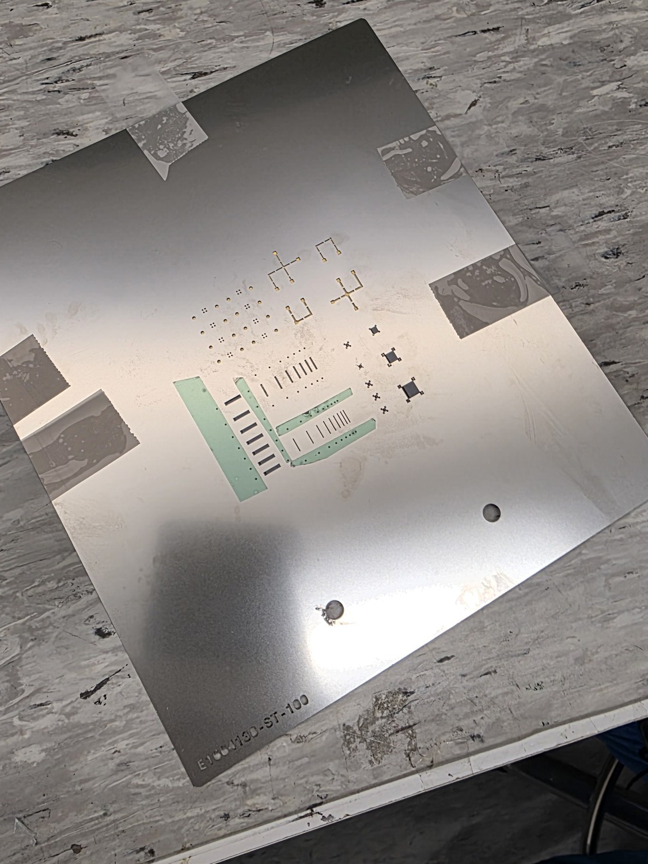
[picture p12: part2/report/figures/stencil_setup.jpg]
  
  \caption{Manual stencil printing. The 100~$\mu$m laser-cut stainless
  stencil is taped flat over the PCB with green polyimide tape; paste is
  pushed across the apertures with a plastic spatula and the excess scraped
  back with a razor blade.}
  \label{fig:stencil}
\end{figure}

\subsection{Stencil printing}

The deposition is manual. The tools are a roll of green polyimide tape, the
PCB, a 100~$\mu$m laser-cut stainless-steel stencil (the same eC-stencil-mate
type Eurocircuits ships with their boards), a plastic spatula, and a razor
blade (Fig.~\ref{fig:stencil}). The stencil is aligned over the board and
taped down flat, paste is dragged across the apertures with the spatula,
and the blade scrapes the excess back. Lifting the stencil leaves a paste
deposit on each LED pad.

The paste is Chip Quik TS391LT, a thermally stable no-clean
Sn42/Bi57.6/Ag0.4 alloy, T4 mesh (20--38~$\mu$m particles), 87\% metal by
weight, with a 138~$^\circ$C melting point~\cite{chipquik_ts391lt}. The low
melting point is the point: a bismuth alloy reflows around
138--165~$^\circ$C instead of the 217~$^\circ$C+ of SAC305, which keeps the
thermal load on the die low.

This method has real advantages. It needs no equipment, it is fast, it is
portable, and it works directly with the Eurocircuits stencils and boards.
The catch is that the deposit is whatever the operator and the stencil give
you: there is no volume metering, the reproducibility is medium, and the
smallest aperture that printed cleanly was 0.4~$\times$~0.4~mm$^2$, right at
the LED pad size. Fig.~\ref{fig:array} shows printed deposits across the
LED array, and Fig.~\ref{fig:paste} is a single site under the die-bonder
camera. The deposits are usable but visibly uneven from pad to pad.

\begin{figure}[!t]
  \centering
  
  \caption{LED footprints after printing, board still in its Eurocircuits
  panel. Each four-pad site carries a small paste deposit; deposit size and
  shape vary noticeably between sites, which is the main limitation of
  hand printing.}
  \label{fig:array}
\end{figure}

\subsection{Die placement}

\begin{figure}[!t]
  \centering
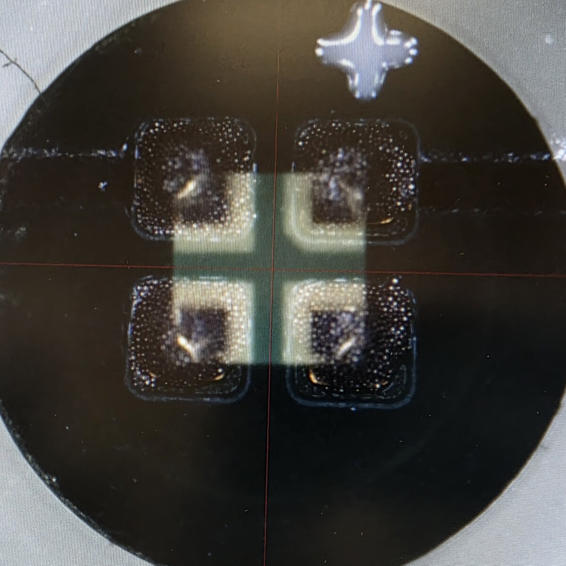
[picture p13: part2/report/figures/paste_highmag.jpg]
  
  \caption{One LED footprint at high magnification through the die-bonder
  camera. The four 0.4~mm pads each hold a grainy paste deposit; the cross
  is a placement fiducial. The dark cross between the pads is the
  soldermask web that separates the anode and the three cathodes.}
  \label{fig:paste}
\end{figure}

Placement runs on a Tresky die bonder (Fig.~\ref{fig:bonder}). The board
sits on the heated vacuum chuck and the dies wait in a ceramic tray. The
machine picks a die, the camera lines it up against the pad fiducial, and
it sets the die down on the paste. The placement parameters used were a
100~g place force, a 20~ms place time, and a 40~ms blow-off. These are
gentle numbers, which is what you want: the paste has to hold the die by
tack until reflow, and pressing too hard squeezes paste out from under the
die and starves the joint.

Placement accuracy by hand-jogged die bonder is only moderate.
Fig.~\ref{fig:placed} shows a die just after it was set down: it sits low
and slightly rotated relative to the crosshair that marks the pad centre.
This offset is normal and, within limits, fine, because the next step is
supposed to correct it.

\subsection{Paste and reflow}

The choice of paste shapes the whole alignment step, because the die only
moves while the solder is liquid. The TS391LT is a near-eutectic
Sn42/Bi57.6/Ag0.4 alloy with a 138~$^\circ$C melting point, well below the
217~$^\circ$C of SAC305. For a GaN micro-LED this low budget matters: less
heat into the die means less thermal stress on the epitaxy and on the
nascent joint. The trade-off is that bismuth alloys are more brittle than
SAC, so the joint is mechanically weaker, which is acceptable here because
the boards are for characterization rather than field service.

Reflow was done on a hot plate toward a peak near 165~$^\circ$C. The window
between melting at 138~$^\circ$C and the peak is the time the joint is
liquid and therefore the time available for self-alignment to act. This is
the part of the process least under control in a manual flow: a hot plate
heats from the bottom and the board's thermal mass and contact set the real
profile, so the liquidus time varies between runs. Since the capillary
restoring motion needs a finite time to bring the die home before the
solder freezes, an inconsistent profile turns directly into inconsistent
alignment, on top of the volume variation from hand printing.

\begin{figure}[!t]
  \centering
  
  \caption{The board mounted on the Tresky die bonder's heated chuck, with
  the LED dies in the white ceramic tray at left. The optical breadboard
  underneath isolates the placement head from vibration.}
  \label{fig:bonder}
\end{figure}

\section{Self-Alignment and Die Tilt}

\subsection{Why the die moves on its own}

When the paste melts, the joint becomes a liquid bridge between the die and
its pads. Surface tension tries to minimize the surface energy of that
bridge, which means it pulls the die toward the position where the molten
solder columns are shortest and most symmetric, i.e.\ centred on the
pads~\cite{mastrangeli2015fluidjoint, mastrangeli2017csa}. For a molten
solder the surface tension is around 500~mN/m and the capillary length is
about 2~mm~\cite{mastrangeli2015fluidjoint}, so for a sub-millimetre die
the capillary force easily dominates gravity. The restoring force scales
with the in-plane offset, so a die placed slightly off-centre
(Fig.~\ref{fig:placed}) gets dragged back during reflow. This is the
mechanism that makes the moderate placement accuracy acceptable.

How much offset the joint can absorb is not small. Krammer et al.\ modelled
the chip during reflow with four forces — surface tension, hydrostatic and
capillary pressure, gravity, and dynamic friction — and showed by
experiment that surface tension dominates the in-plane
motion~\cite{krammer2007reflow}. In their measurements, surface-mount chips
self-aligned even from initial misplacements of
400--500~$\mu$m~\cite{krammer2007reflow}, with average correction distances
around 249~$\mu$m along one axis~\cite{krammer2008movement}. They also found
the alignment is anisotropic and geometry-dependent: parts with metallized
sidewalls (so the solder can wet a vertical face) self-align noticeably
better than parts without~\cite{krammer2008movement}. That is encouraging
for the WL-SFCC, whose four bottom contacts give the molten joint defined
features to pull against, and it sets a generous tolerance budget against
the moderate die-bonder placement of Fig.~\ref{fig:placed}.

The recent work of Lesueur et al.\ puts numbers on the accuracy ceiling.
Using mass reflow of corner solder pillars they reached lateral alignment
better than 2~$\mu$m, and in some configurations under 1~$\mu$m, with
measured z-tilt variation also below 1~$\mu$m, and they showed this
self-alignment absorbs standard flip-chip pick-and-place placement
tolerances outright~\cite{lesueur2025selfalign}. The lesson for the manual
process here is that the achievable accuracy is set by the joint geometry
and the solder, not by how carefully the die is placed.

\begin{figure}[!t]
  \centering
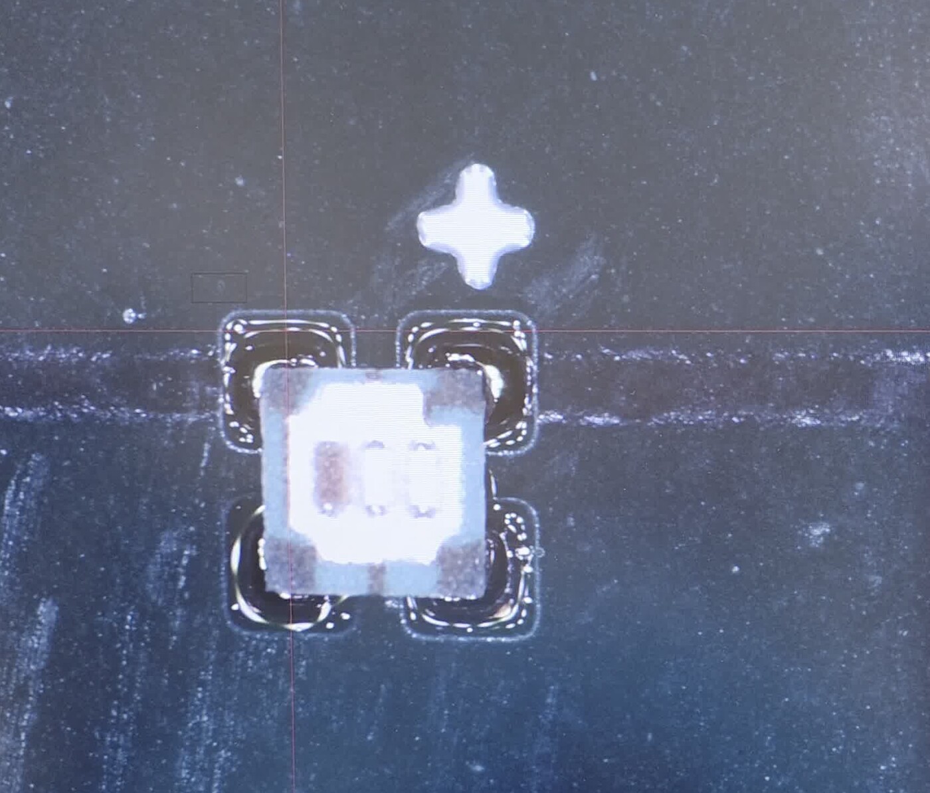
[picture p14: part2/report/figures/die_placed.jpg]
  
  \caption{A WL-SFCC die set down on the printed paste, seen through the
  die-bonder camera. The die straddles the four pads but sits offset and
  rotated relative to the crosshair (pad centre) and the cross fiducial
  above it. Capillary forces are expected to pull this offset out during
  reflow; the risk is that the same forces tilt the die instead.}
  \label{fig:placed}
\end{figure}

\subsection{The tilt problem}

A floating die has four ways to move: shift, twist, lift, and tilt. Three
of them are stable, meaning the capillary force restores the die toward
alignment if it is perturbed. Tilt is the exception: it is
non-restoring~\cite{berthier2015tilt}. Once a die starts to rock, the
solder geometry does not push it flat again, and for a small die with a
thin solder layer the low corner can touch the pad and pin the die in a
tilted position that reflow never undoes. Berthier et al.\ show exactly
this with an LED on solder, and note that avoiding it otherwise requires
near-perfect horizontality at drop-off, which is hard to guarantee on a
hand-jogged machine~\cite{berthier2015tilt}. The older reflow-dynamics
models capture why: the Ellis-Masada picture has the chip rotate about a
corner that stays pinned to the pad~\cite{krammer2008movement}, so any
asymmetry in the solder under the four corners feeds straight into a tilt
the joint cannot correct.

The variable that couples placement, alignment, and tilt is the solder
volume. Vareilles et al.\ measured this directly for sub-millimetre cells
and found the best placement accuracy with low solder volume, a receptor
pad smaller than the die, and an initial offset of about 10\% of the die
size; too much solder both shifts and tilts the part~\cite{vareilles2024solder}.
That is the uncomfortable conclusion for the process I ran: hand stencil
printing has no volume control, and volume is the one knob that matters
most. The uneven deposits in Figs.~\ref{fig:array} and~\ref{fig:paste} are
the visible form of that problem.

\section{Analysis and Suggestions}

Reading the process against the literature, and discussing it with Ahmed,
points to four conclusions:

\textbf{The print is the weak link, not the placement.} The die bonder
places to moderate accuracy and the capillary force forgives the rest, so
chasing tighter placement is not where the effort should go. The deposit
volume and its pad-to-pad consistency are what set how well, and how flat,
each die ends up. A finer or volume-controlled deposition (a thinner
stencil for these pads, or jetting the paste) would attack the actual
limiting variable.

\textbf{Keep the solder volume low and the pad inside the die footprint.}
Following Vareilles et al., a pad slightly smaller than the die and a
modest deposit should give a stronger, flatter pull than a generous
deposit on a matched pad~\cite{vareilles2024solder}. The current 0.4~mm
pads sit right at the die contact size, so there is room to trim them.

\textbf{Tilt is the failure to watch, not shift.} Because shift and twist
self-correct and tilt does not, inspection should look for rocked dies
specifically, ideally in cross-section or with side-view imaging rather
than top-down, which hides tilt. If tilt turns out to be common, the
lyophilic-band trick from Berthier et al.\ — patterning the wettable area
to constrain the liquid and stabilize the tilt mode — is the
design-side fix~\cite{berthier2015tilt}, and it would go straight onto a
future revision of the board.

\textbf{Mind the reflow profile.} The TS391LT melts at 138~$^\circ$C and we
reflowed on a hot plate toward a peak near 165~$^\circ$C. Hot-plate reflow
heats from the bottom and the temperature is not as controlled as an oven
profile, so the time the joint spends liquid, which is the time available
for self-alignment, varies. A logged profile would make the alignment
window repeatable.

\begin{figure}[!t]
  \centering
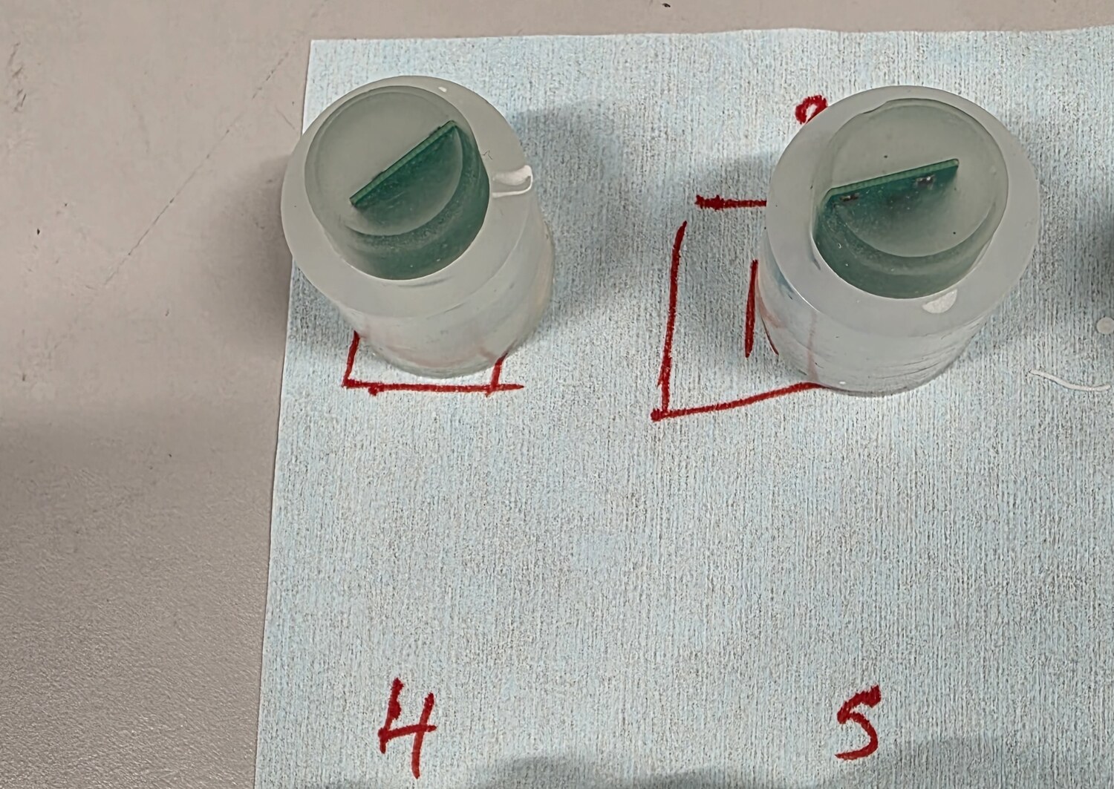
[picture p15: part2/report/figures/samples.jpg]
  
  \caption{Diced board coupons with bonded LEDs, sealed in labelled vials
  after the session. Cutting the board into per-site coupons lets each
  bonded LED be cross-sectioned or imaged from the side, which is the view
  that actually reveals tilt.}
  \label{fig:samples}
\end{figure}

\section{Conclusion}

WL-SFCC micro-LEDs were bonded in the EKL cleanroom in a session run by
Ahmed, which I attended after completing the EKL safety training, gaining
cleanroom and measurement-lab access, and being trained on the die-bonding
flow. The process — hand stencil printing of a low-melting Sn/Bi/Ag paste,
die-bonder placement, hot-plate reflow — is cheap and fast, and the
capillary self-alignment of the molten joint covers the moderate placement
accuracy. The analysis here identifies solder-volume control as the
limiting variable: the literature ties volume to both alignment accuracy
and the non-restoring tilt mode, and hand printing does not control it. The
concrete next steps that follow from this are tighter deposit control, pads
trimmed inside the die footprint, tilt-aware inspection, and a logged
reflow profile. The session was run on the v1 board; once the v2 boards
from Part 1 arrive from the fab, the same process and these same
conclusions apply directly, and the bonded v2 boards are what the
electrical characterization will run on. The samples from this session were
diced and stored for inspection (Fig.~\ref{fig:samples}); side-view imaging
of those coupons is the natural next check, since it is the one view that
shows tilt directly rather than hiding it.

\section*{Acknowledgment}

I thank Ahmed Abdelwahab for the cleanroom training and for the
discussions on self-alignment and tilt that shaped this report.

\bibliographystyle{IEEEtran}
\bibliography{refs}

\end{document}

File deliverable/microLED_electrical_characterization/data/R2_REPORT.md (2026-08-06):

# Round 2 — Arduino I-V sweep: results and conclusions

Written by the analysis side. 89 channel sweeps across 5 boards / 8 samples,
plus 9 repeatability sweeps. Raw data in `../FINAL_MEASUREMENTS/data/R2_sweeps/`.

---

## The headline

**The eight bonding conditions cannot be distinguished by series resistance, and
the reason is now measured rather than assumed: the rig's own repeatability is
larger than the effect.**

    one-way ANOVA over the 7 samples with n>=3:  F(6,21) = 1.96   not significant
    between-sample sd 1.28 ohm    within-sample sd 0.92 ohm

**85 % of that within-sample "die-to-die" scatter is the female-male jumpers, not
the dice.** Three channels re-seated three times each:

| channel | seat 1 | seat 2 | seat 3 | sd |
|---|---|---|---|---|
| s7 D1 R | 10.323 | 12.365 | 10.329 | 1.177 |
| s7 D3 R | 10.424 | 11.130 | 11.769 | 0.673 |
| s8 D6 R | 10.984 | 11.939 | 11.900 | 0.541 |

Pooled seat-to-seat sd **0.843 ohm**, against a within-sample sd of 0.915. Every
channel's minimum is its cleanest seating, and contact resistance can only add, so
the true red R_s is near the **mean of the minima, 10.58 ohm**, with roughly
**0.85 ohm of wiring** sitting on top of every reported number.

Bond resistances are 10-100 mOhm. The instrument floor is 840 mOhm. The experiment
was never capable of resolving them.

### Root cause

`2_ARDUINO_IV.md` takes both sense taps from the breadboard (A1 on FORCE, A0 on
RETURN) rather than from the Tier-1 probe pads. That folds both female-male
jumpers and both header contacts into `v_die`. `ARDUINO_IV_RIG.md` section 4.2
specified the Kelvin arrangement precisely to keep them out. Dropping it is the
single most consequential decision in the round 2 design.

---

## What the data does support

**Yield separates the conditions clearly, and R_s does not.**

| sample | channels lost / 24 | failure modes |
|---|---|---|
| 1 | 2 | 1 detached die, 1 open |
| 2 | 7 | 2 detached dice, 4 opens |
| 3 | 9 of 12 | 5 shorts, 3 opens, 4 cross-lit, 1 shunted — solder contamination |
| 4 | 3 of 12 | 1 short, 1 open, 1 cross-lit |
| 5 | 0 | — |
| 6 | 3 | 1 detached die |
| 7 | 0 | — |
| 8 | 2 | 2 shorts |

Samples 5 and 7 lost nothing. Sample 3 lost 75 %. That is a far stronger
discriminator between processes than any R_s difference, and it does not depend on
the instrument at all.

---

## Findings about the measurement itself

**Round 1's DMM screening was completely reliable.** Six channels it called open
or shorted drew no current on the rig; every channel it passed swept normally.
Zero disagreements in 89 sweeps.

**The rig found one defect the DMM could not.** `s3 D1 R` fits to ideality 13.0 and
R_s = -27 ohm, which is impossible. Below 3 mA the junction sits at 1.21 V — under a
red LED's turn-on — while 0.42 mA flows, so the current is going around the die. A
~2.9 kOhm shunt, consistent with the solder smear round 1 noted. A DMM diode test at
1 mA reads 1.781 V and passes it. Only a current sweep resolves it. Round 1 flagged
it "suspect" without knowing why; that instinct was right.

**The ideality check is a defect detector.** Any channel fitting outside
n = 1.2 to 2.4 has something in parallel with the junction regardless of how normal
its curve looks at working current. It cost nothing and caught the one defect the
DMM missed. All 29 usable reds fit at n = 1.60 to 2.06.

**Green and blue R_s are not usable at 5 V.** Green fits at ideality 3.2 to 4.0,
which is unphysical; blue at 2.2 to 2.5 is borderline. With V_F near 2.8 V the bank
only spans 20x in current, so V0, n and R_s trade off against each other. Red gets
30x and fits cleanly. **Report red only.** More current range would fix this; more
current precision would not, so an SMU is not the answer for green.

---

## Rig defects found and fixed during the campaign

| defect | effect | resolution |
|---|---|---|
| `SHIFT = 4` hardcoded in the original sketch | correct only at OVERSAMPLE 256; step 4 would have rescaled every voltage 4x and 1/4x | divide by `1024 * OVERSAMPLE` |
| Common ADC offset, 14.4 mV | cancels in `v_die`, not in current; 26 % current error at the bottom of the sweep | measured three independent ways, added back in firmware |
| `bandgapRaw()` truncated to integer | quantised the rail to 0.455 %, putting a 2-3 mV floor on `v_die` and costing ~13x in fit precision | return a float over 64 samples |
| Link jumper contact, 2.9 ohm | outside both measurement loops, but a canary | reseated to 0.4-0.7 ohm |

The differential-current fix (A3 to the GND rail) **did not work** and could not:
the GND rail sits at ~0 V, and a channel reading low cannot report a negative count,
so the offset is clipped there and subtracting it does nothing. A3 remains as a
monitor of the ground path.

Verification was bracketed with a 100 ohm dummy. Boards 1, 2 and 5/6 closed at
98.398 / 98.626 / 100.372 ohm with intercepts of -0.72 / -0.78 / -0.42 mV. Board 3/4's
verify failed on a worn dummy fixture, not on the rig: its die sweeps have fit
residuals of 1.29-1.54 mV, indistinguishable from the other boards' 1.55.

---

## Per-channel results, red

| sample | die | R_s (Ω) | n |
|---|---|---|---|
| 1 | D1 | 10.01 | 1.74 |
| 1 | D2 | 11.12 | 1.78 |
| 1 | D3 | 10.05 | 1.75 |
| 1 | D4 | 10.55 | 1.74 |
| 1 | D7 | 12.12 | 1.81 |
| 1 | D8 | 10.77 | 1.67 |
| 2 | D2 | 10.88 | 1.80 |
| 2 | D3 | 10.75 | 1.66 |
| 2 | D4 | 11.22 | 1.77 |
| 2 | D5 | 11.64 | 1.66 |
| 2 | D8 | 11.11 | 1.66 |
| 3 | D1 | -27.46 **excluded** | 12.98 |
| 3 | D4 | 10.92 | 1.65 |
| 4 | D5 | 12.13 | 1.81 |
| 4 | D6 | 13.43 | 1.69 |
| 4 | D8 | 12.81 | 1.78 |
| 5 | D1 | 10.43 | 1.70 |
| 5 | D2 | 12.79 | 1.82 |
| 5 | D3 | 11.24 | 1.81 |
| 5 | D4 | 10.67 | 1.92 |
| 6 | D5 | 10.69 | 1.69 |
| 6 | D6 | 12.37 | 1.67 |
| 6 | D7 | 13.01 | 1.80 |
| 7 | D1 | 10.32 | 1.79 |
| 7 | D2 | 12.03 | 1.87 |
| 7 | D3 | 10.42 | 1.76 |
| 7 | D4 | 13.05 | 1.77 |
| 8 | D5 | 12.66 | 2.06 |
| 8 | D6 | 10.98 | 1.93 |
| 8 | D7 | 11.18 | 1.75 |

| sample | n | mean R_s | sd |
|---|---|---|---|
| 1 | 6 | 10.770 | 0.785 |
| 2 | 5 | 11.120 | 0.344 |
| 3 | 1 | 10.918 | — |
| 4 | 3 | 12.788 | 0.650 |
| 5 | 4 | 11.283 | 1.062 |
| 6 | 3 | 12.023 | 1.201 |
| 7 | 4 | 11.456 | 1.319 |
| 8 | 3 | 11.606 | 0.916 |

Grand mean 11.426 ohm, sd 0.995, N = 29. Corrected for the wiring term, true red
R_s is approximately **10.6 ohm**.

---

## Not collected

- **NTC readings.** None, for any board. Ambient drift cannot be separated from
  self-heating at analysis time.
- **Step 6, reverse leakage.** Skipped by operator decision after the rig was
  assembled. It was the only remaining measurement insensitive to contact
  resistance, and the only one that would have quantified the s3 D1 R shunt.
  Rewire diagram kept at `../FINAL_MEASUREMENTS/arduino-rig/leakage_step6.pdf`.
- **Opening verifies** for boards 2 and 3/4.

---

## If this were repeated

1. **Sense at the Tier-1 probe pads, not the breadboard.** This is the whole
   result. Without it, R_s measures the jumpers.
2. **Report red only,** or raise the supply above 5 V so green and blue get a
   usable current range.
3. **Seat repeats from the start,** not at the end. Three seatings on one channel
   per board would have exposed the problem on day one.
4. **Keep the ideality check.** It is a free defect detector.
5. Self-heating is real but not limiting: R_s falls 1.49 ohm between a 5 ms and an
   80 ms pulse, and 64x oversampling (5 ms) is indistinguishable from 256x.

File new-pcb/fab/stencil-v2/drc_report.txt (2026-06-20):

** Drc report for tud-microled-v2.kicad_pcb **
** Created on 2026-06-20T11:40:44+0200 **
** Report includes: Errors, Warnings **

** Found 0 DRC violations **

** Found 0 unconnected pads **

** Found 0 Footprint errors **

** End of Report **

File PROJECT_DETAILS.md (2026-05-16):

# TU Delft / ITEC — Micro-LED Bonding Categorization Project

Working notes that consolidate everything in this repository: project goal, the
existing KiCad PCB, the supporting papers and datasheet, and links to outside
designs that can serve as inspiration for a new board revision.

---

## 1. Project Goal

This project investigates how to attach small (≈1 mm²) semiconductor / LED dies
onto a PCB **without applying mounting pressure** (the "pick-and-release" / air
drop method) and to **characterize the resulting bonds** geometrically,
mechanically and electrically. It is a collaboration between
**TU Delft (ECTM / Microelectronics, M. Mastrangeli, H. van Zeijl, A. Abdelwahab)**
and **ITEC B.V. / Nexperia (R. van Hoorn, H. Kuipers)**, financed by ITEC B.V.
and co-financed by the Netherlands Enterprise Agency (RVO).

### Work-plan with Ahmed (`Work with Ahmed.md`)

1. **Design of the PCB** for LED characterization.
2. **Clean-room assembly**: solder-paste stencil printing → pick-and-place /
   pick-and-release of LED dies onto either the existing PCB or a newly
   shipped revision.
3. **Geometric characterization** of the LED dies: 3-D laser scans, **bond
   line thickness (BLT)** and **die tilt**. Post-bonding alignment is *not*
   expected to be corrected.
4. **Electrical measurement** and full characterization once assembly is
   complete.

---

## 2. Existing PCB — `Electrical test + LED-no solder.kicad_pcb`

KiCad 6 board (file format version `20221018`, `pcbnew` generator). 4,141
lines of S-expression source.

### Board outline

- **Size**: 58.75 mm × 61.51 mm (Edge.Cuts rectangle `47.85,15.77` →
  `106.6,77.28`).
- **Stack-up**: standard 1.6 mm two-layer FR-4 (`thickness 1.6`), F.Cu / B.Cu.
- **Surface finish (per paper)**: **ENIG** — chosen for solderability and the
  reliable electrical connectivity it gives to the test structures.
- **Silkscreen designer credit**: "Ahmed Abdelwahab" at `(84.1, 50.96)`.

### Footprint inventory

165 footprints total. None carry a populated `reference` or `value` — every
text field is empty / hidden, which is intentional for a research test
board (no part numbers; structures are identified by position only).

Pad-size histogram (count × `width × height` mm):

| Count | Size (mm) | Likely role |
|---:|---|---|
| 645 | 1.27 × 1.27 | Probe pads for VDP / TLM / DC structures |
|  68 | 0.5  × 0.5  | Bond-pad geometry under test |
|  43 | 1.0  × 1.0  | "Reference" 1 mm² bond pad (matches die size) |
|  32 | 0.4  × 0.4  | Bond-pad geometry under test (matches LED land)  |
|  16 | 0.64 × 0.64 | Bond-pad geometry under test |
|  16 | 0.48 × 0.48 | Bond-pad geometry under test |
| 9 | 0.25 × 4 | TLM-style elongated finger |
| 8 | 0.5  × 5 | TLM / current-injection finger |
| 8 | 0.3  × 5 | TLM / current-injection finger |
| 7 | 1.0  × 5 | Wide TLM finger |
| 7 | 0.5  × 4 | TLM finger |
| 4 | 0.25× 0.25  | Smallest bond-pad geometry under test |
| 1 | 4 × 4 / 3 × 3 / 2 × 2 / 1.5 × 1.5 | Larger reference pads |

Pads use both **rect** and **circle** primitives at varying rotations (0°,
90°, 180°, 270°). According to Fig. 12 of the ECTC paper the board also
features the **"+ four corner mini-pads" geometry** (0.5 mm pads added to
the four corners of the 1 mm² bond pads) that *almost eliminated die tilt*
in their experiments.

### Test structures present (from the paper, Fig. 23a)

The PCB integrates:

- **5 × 5 array of 1 mm² bond pads** — the main array on which dummy dies and
  LEDs are mounted (Cu, Ag, Au, ENIG finish variants on the *die* side).
- **Daisy-chain (DC)** structure — bridges six 1 mm × 1 mm dummy dies so a
  single current path runs through six bonds in series → catches detached
  dies and broken chains via X-ray follow-up.
- **Van der Pauw (VDP)** structure — measures **effective sheet resistivity
  of the ENIG-finished pads**: reported value 2.94 × 10⁻⁵ Ω·m.
- **Transmission Line Model (TLM)** structures — measure contact resistivity
  ρ_c via ρ_c = R_c · W · a (Eq. 2 of the paper). The 0.25/0.3/0.5/1 mm × 4–5 mm
  rectangular fingers in the pad table above are the TLM fingers.
- **RGB-LED footprints** matching the **Würth WL-SFCC 0404** (see §3) — used
  to verify that current actually flows through the bonded joints (Fig. 23b
  in the paper shows the LEDs lit up).

The file name **"…-no solder"** signals this is the version with **no solder-
paste apertures defined on the Paste layers**; the solder is screen-printed
through a separate 100 µm laser-cut stainless-steel **stencil with TS391LT
Sn42 / Bi57.6 / Ag0.4 paste**, applied with a manual Eurocircuits
**eC-stencil-mate**.

---

## 3. Supporting Documents in the Repo

### 3.1 `ECTC-2025-published Ahmed Abdelwahab.pdf`
A. Abdelwahab, H. van Zeijl, R. van Hoorn, H. Kuipers, M. Mastrangeli,
**"Pick-and-Release: A Novel Contactless Bonding Method for Die Attachment"**,
*2025 IEEE 75th ECTC*, pp. 2125–2132, **DOI: 10.1109/ECTC51687.2025.00363**.

The directly relevant publication for this PCB. Headline numbers:

- Dies: **1 mm × 1 mm × 525 µm** silicon with Cu / Au / Ag (200–300 nm)
  top finishes over the appropriate adhesion stack (Si₃N₄ or SiO₂ + Cr/Ti).
- Solder: **TS391LT Sn42Bi57.6Ag0.4**, T_melt = 138 °C; reflow peak 165 °C.
- Pick-and-release: free-fall drop from **100–250 µm**, terminal velocity
  ≈ **125 µm/ms** (boosted from gravitational 44–70 µm/ms by the release air
  pulse).
- Contact angle of solder on ENIG pad: **≈ 18°** (lowest of all surfaces
  tested — Si, Cu, Ag, Au all > 18°).
- **Bond Line Thickness (BLT)**: 50–75 µm depending on finish and pressure
  (lower & more reproducible with 1 MPa pick-and-place, irrespective of
  finish).
- **Die tilt**: 5.4°–8.1° "high-tilt" axis without optimization. With the
  **rounded-corner + four corner mini-pads** geometry tilt is reduced to
  **≈ 0.2°** (Ag die, with pressure, Fig. 12).
- **Die-shear strength**: 42.99 ± 4.76 MPa for Ag (best); 9–11 MPa for Cu
  (worst — Cu dies lack an adhesion layer between Cu and Si₃N₄ so failure is
  adhesive at the solder/die interface).
- **Voiding**: 1 MPa mounting pressure eliminates voids for Cu and Ag;
  negligible effect for Au.
- **Electrical**: DC chain resistance lowest for Ag-with-pressure (0.199 ±
  0.019 Ω); highest for Au-without-pressure (0.380 ± 0.025 Ω). Sheet
  resistance of the solder on ENIG: **4.404 × 10⁻⁸ Ω·m**.

### 3.2 `Stabilization of the tilt motion during capillary self-alignment of.pdf`
J. Berthier, K. A. Brakke, S. Mermoz, C. Frétigny, L. Di Cioccio,
**"Stabilization of the tilt motion during capillary self-alignment of
rectangular chips"**, *Sensors and Actuators A*, **234** (2015) 180–187,
DOI: 10.1016/j.sna.2015.09.008.

Foundational reference for the *tilt problem*: among the four self-alignment
modes (shift, twist, lift, tilt), only **tilt is non-restoring** for square /
rectangular chips. Their remedy — **lyophilic / wetting bands patterned on
the substrate** — is conceptually the same trick as the four mini-corner
pads added in §3.1.

### 3.3 `s41586-023-06167-5 (1).pdf`
Lee *et al.*, **"Fluidic self-assembly for MicroLED displays by controlled
viscosity"**, *Nature* **619**, 755 (2023), DOI: 10.1038/s41586-023-06167-5.

State of the art for **massively-parallel** microLED assembly: 19 000 disk-
shaped 45 µm × 5 µm GaN chiplets self-assembled at **99.88 % yield** in 60 s
by adding poloxamer to thicken the carrier liquid. Different regime
(thousands of LEDs, liquid-phase agitation) but the same surface-tension
physics drives the placement.

### 3.4 `patent-published-2024-2026.pdf`
B. V. Nexperia, **"A method for mounting an electronics component at a
particular placement location on a carrier as well as a pick-and-place
apparatus for mounting an electronics component at a particular placement
location on a carrier"**, *PCT Patent Application PCT/EP2024/070643*, 2024.

The patent covers the **pick-and-release / air-drop** method itself (gripper
120, die 11, substrate 50, solder droplet 60 in Fig. 1; controller 140
issues a release pulse at height Δh). Reference [9] of the ECTC paper.

### 3.5 `150044M155220-RGB LEDs.pdf`
Würth Elektronik **WL-SFCC 150044M155220** SMT Full-color (RGB) Chip LED,
0404 package. Key dimensions for the PCB:

- Body: **0.95 mm × 0.95 mm × 0.25 mm**.
- Four pads, **0.275 mm × 0.275 mm**, on a 0.4 mm pitch grid (recommended
  land pattern: **0.4 × 0.4 mm pads, 0.4 mm gap**).
- V_F ≈ 2.0 V (R) / 3.0 V (G,B); I_F = 10 mA nominal, 20 mA peak.
- Peak λ: 630 nm (R) / 520 nm (G) / 460 nm (B).
- Polarity mark on pad 1; common anode (pin 1) per the schematic.
- Operating range −30 °C … +85 °C; ESD HBM 1 kV; MSL 3.

---

## 4. KiCad / PCB Inspiration Found Online

No public open-source KiCad project exactly matches this purpose
(micro-LED-die capillary-bonding characterization with VDP / TLM / DC test
structures on a single board). The relevant building blocks live in
separate repos / datasheets:

### 4.1 RGB-LED footprint for the 0404 Würth WL-SFCC
- **SnapEDA** — `150044M155220` footprint & symbol downloadable as KiCad:
  https://www.snapeda.com/parts/150044M155220/Wurth%20Elektronik/view-part/
- **Ultra Librarian** — companion 150044M155260 part (same family) with
  KiCad export and STEP model:
  https://app.ultralibrarian.com/details/fd6816a2-515d-11ea-a124-0ad2c9526b44/Wurth-Electronics/150044M155260
- **Würth official datasheet** (recommended land pattern, top of §3.5):
  https://www.we-online.com/components/products/datasheet/150044M155220.pdf

Use any of the above and *verify* against the 0.4 × 0.4 mm pads / 0.4 mm
pitch land pattern before committing.

### 4.2 LED sample / reference card boards
- **Kaouthia/LED-Sample-Board** (GPL-3.0): a small KiCad / Gerber project
  whose only purpose is to expose SMT LEDs on solderable pads, useful as a
  layout reference for densely-packed LED footprints —
  https://github.com/Kaouthia/LED-Sample-Board

### 4.3 Flip-chip / die-attach templates
- **jaylogue/dec-flip-chip-templates** (CC-BY-4.0): KiCad templates for
  retro DEC flip-chip modules; uses ENIG / hard-gold finish at 1.4–1.6 mm
  thickness — same fab constraints as ours. Useful as a *pad-on-edge*
  reference even though the application is unrelated —
  https://github.com/jaylogue/dec-flip-chip-templates
- Hackaday writeup: https://hackaday.com/2021/11/07/flip-chip-kicad-templates/

### 4.4 KiCad standard footprint libraries (always check first)
- LED_SMD library: https://kicad.github.io/footprints/LED_SMD
- Würth connector library (community): https://github.com/savenlid/kicad/tree/master/footprints/Wurth-Elektronik

### 4.5 Test-structure references (not KiCad, but design-side)
- TLM theory and contact-resistance extraction:
  https://en.wikipedia.org/wiki/Transfer_length_method and
  https://cleanroom.byu.edu/contact_resistance
- Practical Components BGA daisy-chain test kit — commercial reference
  showing pad/via patterns that connect die-side and PCB-side halves of a
  daisy chain: https://www.practicalcomponents.com/Evaluation-PCB-Boards/product.cfm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

### 4.6 Underlying research literature on substrate / pad design
- M. Mastrangeli, **"Capillary self-alignment of microchips on soft
  substrates"** (open-access via PMC):
  https://pmc.ncbi.nlm.nih.gov/articles/PMC6190098/
- M. Mastrangeli profile (links to the full surface-tension-driven
  self-assembly publication list):
  https://microelectronics.tudelft.nl/People/bio.php?id=514

---

## 5. Suggested next steps for a board revision

Driven by the paper's own conclusions:

1. **Always include the four-corner mini-pads** on every 1 mm² bond pad
   variant — die tilt drops from ~6° to ~0.2°.
2. Add a **rounded-corner** variant of the 1 mm² pads explicitly; the paper
   only references it qualitatively. A radius sweep (R = 50 / 100 / 200 µm)
   would close that gap.
3. **Increase TLM finger length range**: current 4–5 mm fingers; a
   conventional TLM ladder uses contact spacings of e.g. 5/10/20/50/100/200 µm
   between identical fingers. Verify the pattern is a true TLM ladder, not
   a single width-varied finger set.
4. **Bring the Würth WL-SFCC 0404 land pattern** in as official Würth
   footprint (SnapEDA / Ultra Librarian) rather than a hand-drawn copy —
   future-proofs against tolerance creep.
5. **Add fiducials** for the Tresky T-3000-PRO bonder and stencil-mate
   alignment.
6. **Annotate** the silkscreen with structure IDs ("DC1", "VDP1", "TLM-W0.5",
   etc.). The current board carries no on-board labels at all.

---

## 6. Quick filesystem map

```
.
├── Electrical test + LED-no solder.kicad_pcb   # KiCad 6 board, 165 footprints, 58.75 × 61.51 mm
├── Work with Ahmed.md                          # 4-step work-plan with Ahmed Abdelwahab
├── ECTC-2025-published Ahmed Abdelwahab.pdf    # The published paper this PCB was used for
├── Stabilization of the tilt motion ...pdf     # Berthier 2015, tilt-instability theory
├── s41586-023-06167-5 (1).pdf                  # Nature 2023, FSA microLED at 99.88 % yield
├── patent-published-2024-2026.pdf              # PCT/EP2024/070643, pick-and-release patent
└── 150044M155220-RGB LEDs.pdf                  # Würth WL-SFCC 0404 RGB LED datasheet
```

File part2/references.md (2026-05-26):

# Part 2 — References (micro-LED bonding, capillary self-alignment, die tilt)

All IEEE links go through the TU Delft proxy (`ieeexplore-ieee-org.tudelft.idm.oclc.org`) so they open directly with library access. Verified to exist on IEEE Xplore on 2026-05-26.

## Already downloaded (shared by Ahmed, in `RE_ PCB Design for electrical tests/`)

1. **J. Berthier, K. A. Brakke, S. Mermoz, C. Frétigny, L. Di Cioccio**, "Stabilization of the tilt motion during capillary self-alignment of rectangular chips," *Sensors and Actuators A: Physical*, vol. 234, pp. 180–187, 2015. DOI: 10.1016/j.sna.2015.09.008
   - The key tilt reference: of the four CSA displacement modes (shift, twist, lift, tilt), only **tilt is non-restoring/unstable**; tilting can trigger direct chip–pad contact that jams alignment. Shows an LED-on-solder tilt example. Stabilized by lyophilic bands patterned on the substrate.

2. **V. Vareilles et al.**, "Experimental and Simulative Correlations of the Influence of Solder Volume and Receptor Size on the Capillary Self-Alignment of Micro Solar Cells," *J. Microelectromechanical Systems*, vol. 33, no. 2, pp. 290–xxx, Apr. 2024. DOI: 10.1109/JMEMS.2024.3352396
   - IEEE: https://ieeexplore-ieee-org.tudelft.idm.oclc.org/document/10413356/
   - Guideline: **low solder volume + receptor pad smaller than the chip + initial offset ≈10 % of chip size → best placement accuracy.** Solder volume drives both translation and tilt.

3. **M. Mastrangeli**, "The Fluid Joint: The Soft Spot of Micro- and Nanosystems," *Advanced Materials*, vol. 27, no. 29, pp. 4254–4272, 2015. DOI: 10.1002/adma.201501260
   - Fluid-joint physics. Molten-solder surface tension γ ≈ 500 mN/m, capillary length L_c ≈ 2 mm; surface tension dominates gravity below that scale.

4. **M. Mastrangeli, Q. Zhou, V. Sariola, P. Lambert**, "Surface tension-driven self-alignment," *Soft Matter*, vol. 13, no. 2, pp. 304–327, 2017. DOI: 10.1039/C6SM02078J
   - Definitive review of capillary self-alignment statics and dynamics.

## To download from IEEE Xplore (TU Delft proxy)

5. **O. Krammer, B. Sinkovics, B. Illes**, "Studying the Dynamic Behaviour of Chip Components during Reflow Soldering," *30th ISSE*, 2007.
   - https://ieeexplore-ieee-org.tudelft.idm.oclc.org/document/4432814/
   - Chip movement and self-alignment dynamics during reflow.

6. **O. Krammer, Z. Radvanszki, Z. Illyefalvi-Vitez**, "Investigating the movement of chip components during reflow soldering," *2nd ESTC*, 2008.
   - https://ieeexplore-ieee-org.tudelft.idm.oclc.org/document/4684463/
   - Follow-up quantifying chip self-alignment displacement during reflow.

7. **T. Lesueur et al.**, "Self-Alignment of Active Si Bridge using Solder Joints Capillary Forces," *IEEE 75th ECTC*, 2025.
   - https://ieeexplore-ieee-org.tudelft.idm.oclc.org/document/11038257/
   - Most recent: solder-joint capillary self-alignment of an active component, same year as Abdelwahab's ECTC work.

8. **"Micro-LED Mass Transfer Technologies"** (review).
   - https://ieeexplore-ieee-org.tudelft.idm.oclc.org/document/9201923/
   - Context: where solder/self-assembly bonding sits among micro-LED mass-transfer methods.

9. **"An Alternative Micro LED Mass Transfer Technology: Self-Assembly."**
   - https://ieeexplore-ieee-org.tudelft.idm.oclc.org/document/9873296/

10. **"Fluidic Self-Assembly Transfer Technology for Micro-LED Display."**
    - https://ieeexplore-ieee-org.tudelft.idm.oclc.org/document/8808352/

## Component / process datasheets (already in repo)

- Würth WL-SFCC 0404 RGB LED (150044M155220) — `docs/datasheets/Wurth-WL-SFCC-0404-RGB-LED-150044M155220.pdf`
- ChipQuik TS391LT solder paste, Sn42/Bi57.6/Ag0.4 T4, mp 138 °C — from `part2/manual printing.pdf` (Ahmed's KET3 deck)

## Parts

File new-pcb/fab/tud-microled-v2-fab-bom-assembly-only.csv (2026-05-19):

Reference | Value | Footprint | Quantity | Manufacturer | MPN | Distributor | DPN | DNP
R_EIS_LOAD | 100R 0.1% 0603 thin-film 10ppm | EIS_Load_0603 | 1 | Yageo | RT0603BRB07100RL | Mouser | 603-RT0603BRB07100RL | No
H_N,H_S | Pin 2.54mm THT 1x40 single-row male gold | Header_2.54mm | 2 | Samtec | TSW-140-07-G-S | Mouser | 200-TSW14007GS | No
TH1,TH2,TH3,TH4 | NTC 10k 0402 3% AEC-Q200 | NTC_0402 | 4 | TDK | NTCG104BH103HT1 | Mouser | 810-NTCG104BH103HT1 | No

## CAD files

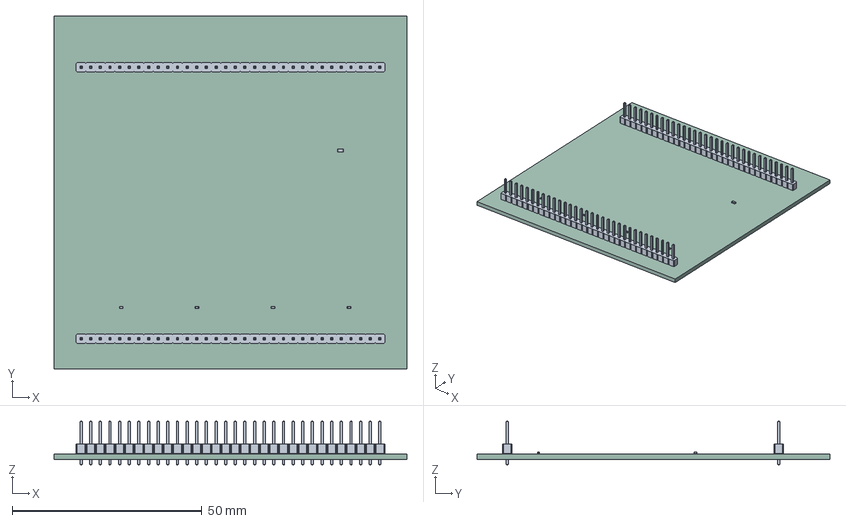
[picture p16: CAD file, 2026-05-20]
new-pcb/fab/tud-microled-v2.step
93.0 x 93.0 x 11.5 mm
R_0402_1005Metric x 4
R_0603_1608Metric
PinHeader_1x32_P2.54mm_Vertical x 2
tud-microled-v2_PCB

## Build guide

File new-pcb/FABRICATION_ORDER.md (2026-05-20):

# Fabrication Order — Eurocircuits PCB + Assembly

**Project:** TUD micro-LED v4 · **Designer:** Daniel Tyukov · 5714699 · ET4277 / ET4391
**Board:** 93 × 93 mm · 2-layer FR-4 · 1.55 mm · ENIG · DRC clean (0 violations, 0 unconnected, 0 schematic-parity)

Order path: **Eurocircuits PCB-proto + PCBA-proto, all 3 BOM lines set to "Place on board"** (Eurocircuits sources the parts through their European distributor network, reflows the 5 SMD placements on the SMT line, and hand-solders the 2 THT header strips). The 26 LEDs stay off the PCB entirely (DNP — bonded later at TU Delft EKL under the Tresky T-3000-PRO with a controlled paste profile). The boards arrive fully assembled except for the LEDs.

The PCB's F.Paste gerber has **exactly 10 apertures** — only the 4 NTCs (8 pads) and 1 resistor (2 pads). The 26 LED footprints have no paste apertures so the SMT stencil never deposits paste on the bond pads.

---

## TL;DR

1. Bare PCB: 10 × 93 mm × 93 mm, 2-layer FR-4 1.55 mm, **ENIG**, white silk, green soldermask.
2. PCBA service: upload BOM + pos, all 3 BOM lines set to **"Place on board"**, no stencil add-on needed.
3. Components sourced and assembled by Eurocircuits: 4 × TDK NTC + 1 × Yageo R + 2 × Samtec headers per board × 10 boards.
4. 26 LED footprints are marked DNP (`exclude_from_bom` + `exclude_from_pos_files` in the .kicad_pcb) — Eurocircuits ignores them entirely and the LED pads ship as bare ENIG gold.

---

## Spec

| Field | Value |
|---|---|
| Layers | 2 |
| Dimensions | **93 × 93 mm** (fits Tresky T-3000-PRO die-bonder with 1 mm margin to its 95 × 95 mm envelope) |
| Thickness | 1.55 mm |
| Quantity | **10 boards** |
| Surface finish | **ENIG (Gold)** — Ni 4 µm + Au 0.075 µm RoHS — mandatory for LED bonding and probe-pad ohmic contact |
| Outer copper | 35 µm (1 oz) |
| Solder mask | Green |
| Silk | White |
| Min clearance / track | 0.30 / 0.20 mm (design); clears Eurocircuits Class 4 (0.15 mm minimum) with 2× headroom |
| Min drill / annular ring | 0.30 / 0.15 mm |
| Solder paste | F.Paste 10 apertures (4 NTC + 1 R) · B.Paste empty · 26 LED pads paste-free |

---

## Bill of materials — 3 distinct parts, 7 placements per board

All 7 placements are soldered on the Eurocircuits SMT/THT line. Only the 26 LEDs ship as bare ENIG gold lands for EKL bonding.

| Ref(s) | Footprint | Manufacturer | MPN | Mouser part # | Qty per board | Qty for 10 boards |
|---|---|---|---|---|---:|---:|
| **R_EIS_LOAD** | 0603 thin-film | Yageo | `RT0603BRB07100RL` | 603-RT0603BRB07100RL | 1 | 10 |
| **H_N** + **H_S** | 1×32 THT (cut from 1×40) | Samtec | `TSW-140-07-G-S` | 200-TSW14007GS | 2 strips | 20 strips |
| **TH1, TH2, TH3, TH4** | 0402 NTC | TDK | `NTCG104BH103HT1` | 810-NTCG104BH103HT1 | 4 | 40 |

Total assembled placements per board: **7** (1 × R + 2 × header strips + 4 × NTC).

### Do-Not-Populate (LEDs — customer bonds at EKL)

| Ref pattern | Qty | Component |
|---|---:|---|
| `D1..D8` | 8 | Würth WL-SFCC RGB LED (`150044M155220`) |
| `DCL6_L1..L6` | 6 | same |
| `DCL12_L1..L12` | 12 | same |

**Total: 26 LEDs per board, customer-supplied, customer-bonded.** The `.kicad_pcb` flags each WL-SFCC_0404 footprint with `exclude_from_bom` + `exclude_from_pos_files` so Eurocircuits' tooling treats them as bare gold lands.

---

## Files to upload

| File | Where in Eurocircuits |
|---|---|
| `fab/tud-microled-v2-gerbers.zip` | PCB visualiser (auto-extracts gerbers + drill) |
| `fab/tud-microled-v2-fab-bom.csv` (or the slim `-assembly-only.csv` variant) | eC-stencil-mate → BOM |
| `fab/tud-microled-v2-pos.csv` | eC-stencil-mate → Pick-and-Place |
| `fab/tud-microled-v2-top.pdf` / `-bot.pdf` | Visual review |
| `fab/tud-microled-v2.step` | Optional 3D verification |

---

## Step-by-step at eurocircuits.com

1. **Create a PCB-proto order** — upload `tud-microled-v2-gerbers.zip`. Configure: 2-layer, 1.55 mm FR-4, **ENIG** (chemical Ni/Au), white silk, green mask, 10 boards.
2. **Add PCBA service** to the same order — upload `tud-microled-v2-fab-bom.csv` and `tud-microled-v2-pos.csv`.
3. In the eC-stencil-mate BOM editor, leave every line in the default **"Place on board"** mode. There are exactly 3 lines (Yageo R, Samtec strip, TDK NTC), all marked DNP=No.
4. The 26 LED rows do not appear because `exclude_from_bom` filters them out at the .kicad_pcb layer.
5. Eurocircuits' supplier scanner will resolve the 3 MPNs through Mouser/Farnell. They may show "NI" (No Info) for ~1 working day while an engineer confirms European pricing — normal.
6. Pay; lead time ~7 WD PCB + 5 WD PCBA. Fully-assembled boards (minus the 26 LEDs) arrive in one shipment.

---

## When the boards arrive — sanity-check inspection

1. **26 LED footprints are bare ENIG gold** — no solder, no tin, no paste residue. If there is ANY paste film on the LED bond pads, reject the boards (the bonding step at EKL will fail).
2. **4 NTCs and 1 resistor are reflowed cleanly** — no tombstoning, no bridging, no solder balls.
3. **2 Samtec header strips are soldered into the 64 THT holes** (32 north + 32 south), pins vertical, no missing pins, no cold joints.
4. **Probe pads, TLM/VDP, DoE bond pads, TC pads, fiducials** all bare gold — no tin, no HASL.
5. **Cross-check labels** on the parts against the BOM CSV: TDK NTCG104BH103HT1, Yageo RT0603BRB07100RL, Samtec TSW-140-07-G-S.

If anything is wrong, contact Eurocircuits within their 1-week claim window — they re-fab without quibble.

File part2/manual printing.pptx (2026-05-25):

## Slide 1

KET3
Ahmed

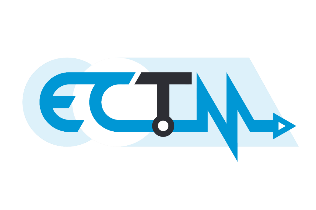
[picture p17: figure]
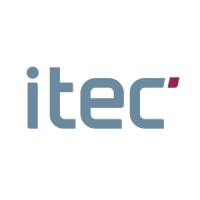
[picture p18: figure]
ITEC | LinkedIn

, 2025

## RGB-LEDs

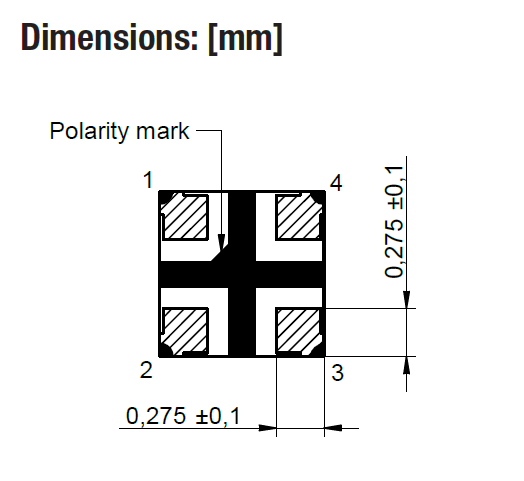
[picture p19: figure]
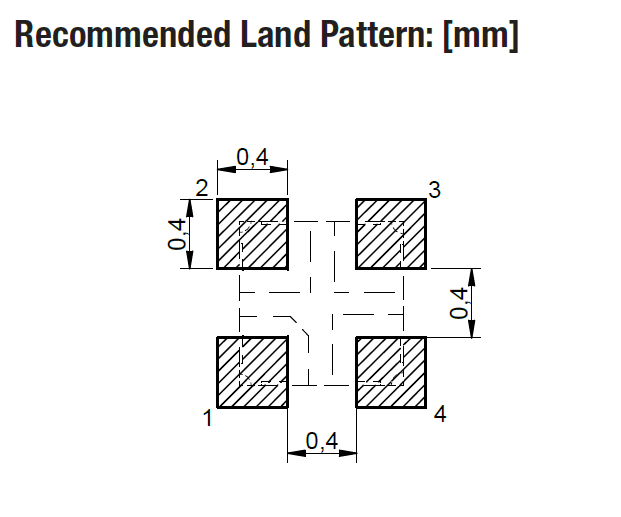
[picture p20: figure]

## PCB

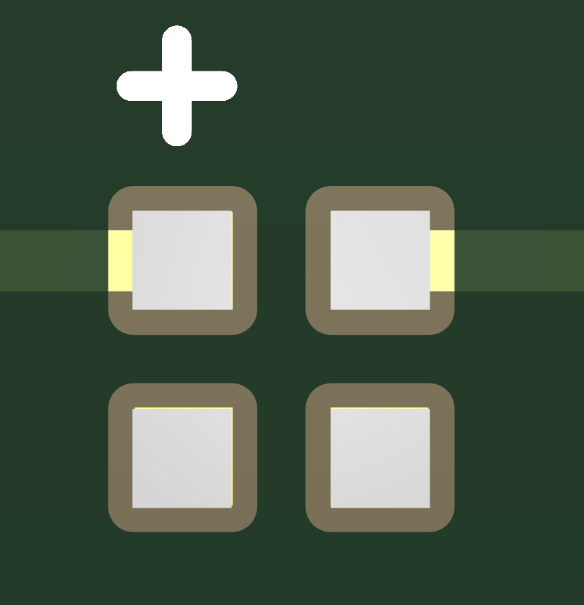
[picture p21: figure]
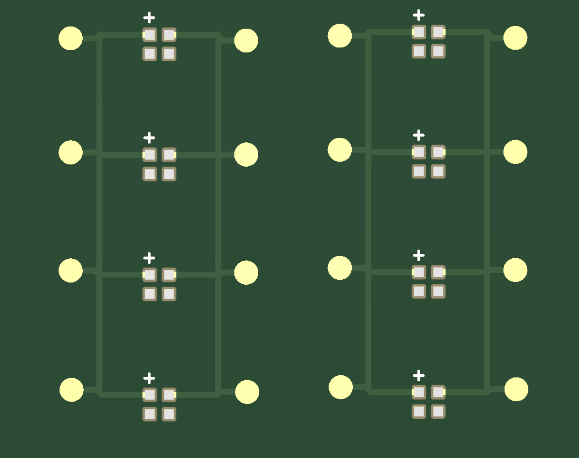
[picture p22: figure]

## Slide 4

Setup

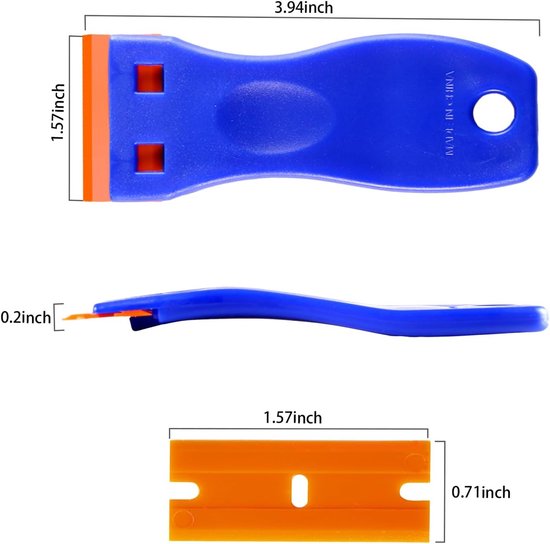
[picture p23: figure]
Kunststof schrapers - Kunststof schrapers - Krasvrije kunststof schrapers - Schrapers voor raamstickers - Reinigingsschrapers voor verwijderaars, lijmen, stickers, decals, glas, etiketten, autoruiten

Tape, PCB, stencil mask (100um), plastic mouth spatula, razor blade

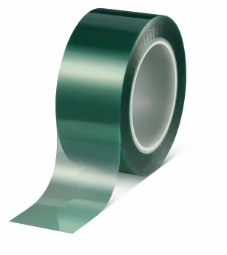
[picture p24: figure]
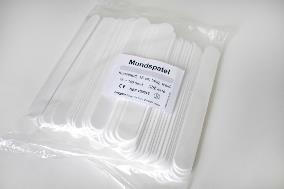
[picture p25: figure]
Mundspatel aus Kunststoff ➡ ab 8,27 €
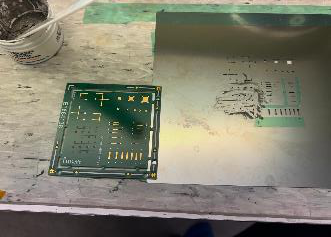
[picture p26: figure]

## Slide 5

Setup

Tape, PCB, stencil mask (100um), plastic spatula, razor blade

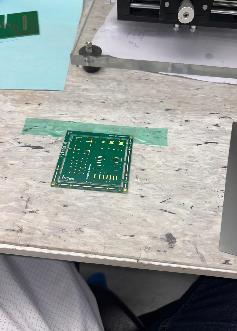
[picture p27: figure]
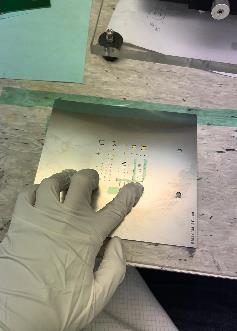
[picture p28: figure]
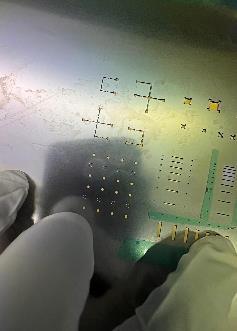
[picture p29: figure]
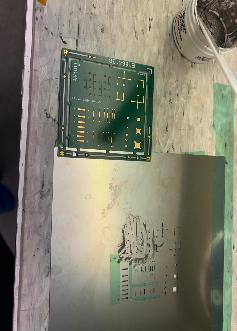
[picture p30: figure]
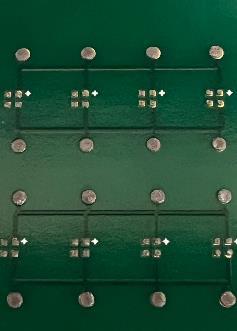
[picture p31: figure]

## Print

Die-bonder camera

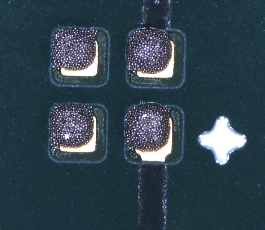
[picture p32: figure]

Advantages | Disadvantages
Very Simple (no equipment) | Medium accuracy
Fast | Only Printing on Small areas
portable | No volume control
Compatible with Eurocircuits stencils and PCBs | Medium reproducibility
| Max. resolution tested 0.4x0.4mm2

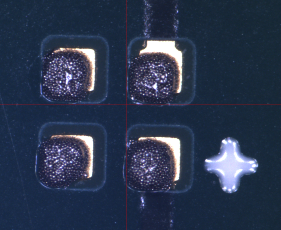
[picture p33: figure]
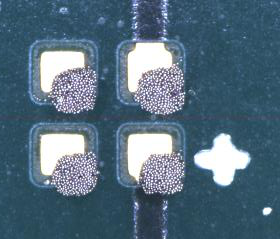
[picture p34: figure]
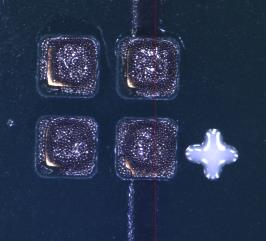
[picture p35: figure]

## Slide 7

Solder paste

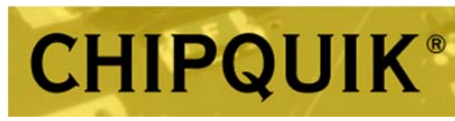
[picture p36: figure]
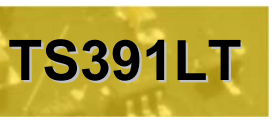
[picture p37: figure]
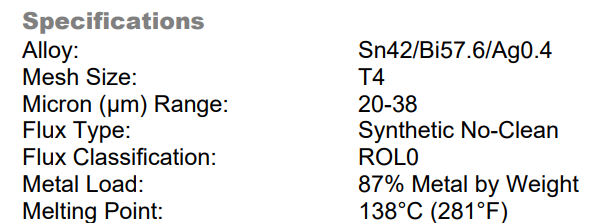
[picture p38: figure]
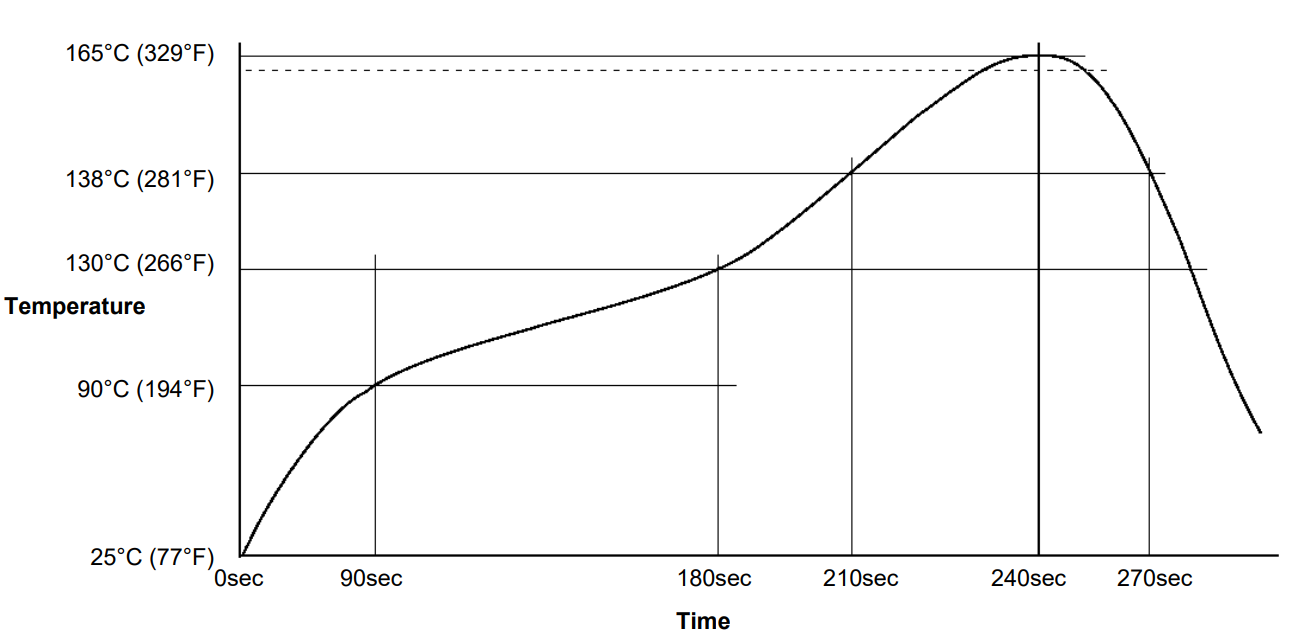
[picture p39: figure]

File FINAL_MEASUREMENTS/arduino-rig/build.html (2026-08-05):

FINAL_MEASUREMENTS / round 2

# Arduino I-V rig: the breadboard, hole for hole

This is the wiring in 2_ARDUINO_IV.md drawn out. Nothing is added and nothing is left out: 11 male-male jumpers, 2 female-male, 7 resistors, 3 caps, one Arduino UNO, one breadboard. Rail holes follow the column numbers: first one under column 3, then five in a row, a one-hole gap, five more, and so on.

## The build

Fit width Full size

Top view. Wires are drawn passing over the board where they physically would. Only the bottom half of the breadboard is used.

## Close-up: the RETURN cluster

Fit width Full size

Columns 2 to 13 at twice the size. The orange shading is one node: five holes per column joined inside the board, and the link jumper ties column 4 to column 8. Note the rail gap at column 8, which the A2 wire runs straight through.

## Every hole, by net

### FORCE

bottom outer rail

col 6

jumper to UNO A1

col 11

C1, other leg on the GND rail at col 13

15 17 19

bank resistors, lower legs

21 23 25

bank resistors, lower legs

col 29

F/M jumper out to the die anode, header pin 4n−2

7–9

a link across the gap, only if your board's rails are split rather than continuous

The rail is one strip, so any hole on it is electrically the same. These columns just keep the leads short.

### GND

bottom inner rail

col 3

jumper to UNO GND — the only ground wire in the rig

col 5

C2, other leg in A4

col 9

C3, other leg in A8

col 11

100 Ω sense, other leg in B8

col 10

jumper to UNO A3 — senses the bottom of the 100 Ω

col 13

C1, other leg on the FORCE rail at col 11

Column 3 is the first hole the rail has. Columns 8, 14, 20 and 26 are the gaps and have no hole at all.

### RETURN

cols 4 + 8, rows A–E

A4

C2 down to the GND rail

C4

F/M jumper out to the cathode of the channel under test

D4

jumper to UNO A0

E4 ↔ E8

the link that makes both columns one node

A8

C3 down to the GND rail

B8

100 Ω sense down to the GND rail

D8

jumper to UNO A2

These eight hole numbers are the only ones that matter in the whole build.

## The resistor bank

Each branch is one jumper into row E and one resistor from row A across to the FORCE rail one column to the right. The diagonal keeps the resistor body clear of the GND rail so you can see at a glance that it is not plugged into it.

UNO pin | jumper lands | resistor | row A | lower leg on FORCE | branch current, red
D7 | E14 | 220 Ω | A14 | col 15 | 10.06 mA
D6 | E16 | 330 Ω | A16 | col 17 | 7.49 mA
D5 | E18 | 1 kΩ | A18 | col 19 | 2.93 mA
D4 | E20 | 2 kΩ | A20 | col 21 | 1.53 mA
D3 | E22 | 5.1 kΩ | A22 | col 23 | 0.62 mA
D2 | E24 | 10 kΩ | A24 | col 25 | 0.32 mA

## Count before you power up

12male-male jumpers: 6 bank, A0, A1, A2, A3, GND, 1 link

2female-male jumpers, the only wires leaving the board

7resistors: six in the bank, one 100 Ω sense

3capacitors, 68 nF each: C1 rail to rail, C2 and C3 on RETURN

1. Six bank resistors: one leg in row A at columns 14, 16, 18, 20, 22, 24, the other leg in the FORCE rail one column to the right.
2. Jumper D2–D7 into row E of each bank column: D7 to E14, up to D2 at E24.
3. Link E4 to E8. All ten of those holes are now RETURN.
4. 100 Ω from B8 down to the GND rail at column 11.
5. C2 from A4 and C3 from A8 down to the GND rail; C1 from FORCE col 11 across to GND col 13.
6. Jumper UNO GND to the GND rail at column 3. No second ground wire anywhere.
7. Jumper A0 to D4, A2 to D8, A1 to the FORCE rail at column 6, and A3 to the GND rail at column 10.
8. Two female-male jumpers out to the die: FORCE to pin 4n−2, RETURN C4 to the cathode pin of the colour you are sweeping.

To move to the next channel, move only those last two jumpers. Everything else stays put for the whole session.

## Why A3 is there

Step 3 was run on a 100 Ω dummy and the rig failed it. A pure resistor must fit v_die = i·R through the origin. It fitted 99.32 Ω but with a +13.8 mV intercept, which is not something a resistor can do.

level | branch | i predicted | i measured | deficit across R_sense
1 | 10 kΩ | 0.4943 mA | 0.3634 mA | +12.9 mV
4 | 2 kΩ | 2.3030 mA | 2.1916 mA | +11.0 mV
16 | 330 Ω | 9.0636 mA | 8.9553 mA | +10.7 mV
32 | 220 Ω | 11.3966 mA | 11.2726 mA | +12.2 mV

Constant in millivolts across a 30× current range, so it is an additive ADC offset of about 10 mV, not a resistance or reference error, which would both scale with current. A diagnostic sweeping ADC prescaler (/32, /64, /128) against discarding a conversion after each mux change — six combinations — gave the same offset every time, so it is neither clock speed nor mux settling.

The offset cancels in v_die, because that is a difference of two channels. It does not cancel in the current, which was an absolute voltage. At the bottom of the sweep the current was wrong by 26 %.

A3 makes the current a difference too. It taps the GND rail in the same five-hole group as the 100 Ω's lower leg, and the sketch computes i = (v_A2 − v_A3) / R_SENSE. The offset subtracts out exactly, and the IR drop in the single GND jumper leaves the measurement with it.

### Also found: 2.9 Ω in the E4–E8 link

A0 and A2 are the same node by design and must read identically. A0 read high by an amount strictly proportional to current, 2.9 ± 0.2 Ω across levels 2 to 32. That is contact resistance in the link jumper or its sockets. In this topology it sits outside both the v_die loop and the current tap, so it is not corrupting R_s, but it is thirty times the bond resistances being measured and a joint that loose will not stay put. Reseat it.

## Capacitor value

68 nF for all three. Anything from about 47 to 100 nF works and the tolerance does not matter, since nothing in the measurement depends on the value. Put the smallest of the three on C1, which is the only one whose settling is tight.

C1 | τ = 10 kΩ · C | settle, red V_F ≈ 2 V | settle, blue V_F ≈ 3 V
68 nF | 0.68 ms | 0.35 ms | 0.63 ms
100 nF | 1.0 ms | 0.51 ms | 0.92 ms
220 nF | 2.2 ms | 1.1 ms | 2.0 ms
1 µF | 10 ms | 5.1 ms | 9.2 ms

The slow node is FORCE with only the 10 kΩ branch on, at the bottom of the sweep, charging through t = R·C·ln(5/(5−V_F)). The sketch allows SETTLE_MS = 2, so 100 nF is the ceiling. Below about 30 nF the ADC's 14 pF sample-and-hold starts stealing a visible fraction of the charge on every one of the 256 oversampled reads.

### §4.5 of the background doc says up to 1 µF. It cannot.

At 1 µF a blue channel needs 9.2 ms to reach V_F on the lowest current step, against a 2 ms settle. The ADC would read a node still on its way up, the fit would see too little voltage at low current, and that lands squarely on R_s as series resistance that is not there. The same section's own worked example (0.7 ms at 68 nF, comfortably inside 2 ms) is the reasoning that rules out its own upper bound.

## Two things in the doc that do not agree

### The Build block still lists the old resistor values

The parts table in 2_ARDUINO_IV.md says 10 k, 5.1 k, 2 k, 1 k, 330 Ω, 220 Ω, and the current table underneath it (0.32 / 0.62 / 1.53 / 2.93 / 7.49 / 10.06 mA) is computed from exactly those. The ASCII Build block a few lines lower still says 4k7, 2k2 and 470, carried over from measurements/ARDUINO_IV_RIG.md. The drawing uses the parts table. The ASCII block is the one that needs editing.

### A0 and A2 land on the same node, so this is not Kelvin sensing

Section 4.2 of ARDUINO_IV_RIG.md puts A1 and A0 on the Tier-1 probe pads so that jumper wire and header contact resistance sit outside the sense loop. Round 2 instead takes both from the breadboard, which folds both female-male jumpers and both header contacts back into V(A1) − V(A0). That is a few tens to a couple of hundred mΩ, the same size as the bonds you are chasing.

It is not fatal, and it is the reason the plan already asks for seat2 and seat3 repeats: the wiring term is what re-seating changes. But quote R_s from this rig as die + wiring, and treat the seat-to-seat spread as the error bar on the wiring part rather than as noise.

Drawn from FINAL_MEASUREMENTS/2_ARDUINO_IV.md · pad mapping from round 1: pad 1 = red cathode, pad 2 = anode, pad 3 = green, pad 4 = blue · the “A KG KB KR” order silkscreened on board-probe-map.png is the old, wrong one.

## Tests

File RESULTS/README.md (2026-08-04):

# RESULTS

Live data from the round 1 bench session. **You do not write in these files. I do.**

Every row that can be known in advance is already filled in: board tag, sample number, die,
channel, which header pins to touch. The only empty cells are the ones that need a meter
reading.

Procedure: `../FINAL_MEASUREMENTS/1_MULTIMETER_ONLY.md`

---

## How to report a reading

Say the location and the number. Nothing else. Examples:

```
board 1, D3, red, 1.812, lit
board 1, D3, green, OL, dark
3/4 board, D6, blue, 2.71, lit
board 2, D1, pin 4 to pad, 0.3
lead zero rep 4, 0.1
TH1 through TH4 on board 1: 10240, 10190, 10210, 10230
```

Rules that matter:

- **Say `OL` when the meter says `OL`.** Never convert it to a number or skip it.
- Read the digits exactly as displayed, including trailing zeros. `1.810` and `1.81` are
  different pieces of information about the last digit.
- If you re-land a probe and get a different number, give me both. Do not pick one.
- Anything odd, say it in words. Bad contact, probe slipped, reading drifting, die looked
  wrong. It goes in the note column and it is often the finding.

You can report in any order and jump around between boards. Every row is addressable, so I
fill whichever one you name.

## Files

| File | Rows | Pre-filled | You supply |
|---|---:|---|---|
| `R1_meter.csv` | 19 | item, dial, range, REL state | the reading |
| `R1_board.csv` | 65 | board, check, which pins | the reading, pass/fail |
| `R1_temp.csv` | 5 | board tag | four NTC resistances per visit |
| `R1_dies.csv` | 76 | board, sample, die | present, alignment, solder, the three isolation readings |
| `R1_channels.csv` | 156 | board, sample, die, channel, both pin numbers | diode volts, lit/dark, two isolation readings |
| `R1_chain_ends.csv` | 4 | board, sample, chain | forward and reverse readings |

`R1_channels.csv` is the main one: **120 individual-die channels** across the five boards.
The 36 chain-die rows are present but marked `excluded`, see below.

## Daisy chains are excluded

The chains on boards 1 and 2 are **electrically dead by a board design fault**, not by any
bond failure. The dice sit rotated 90°, so the chain wiring joins each die's red cathode to
its blue cathode and leaves the anode floating. Every chain die is two back-to-back diodes
and no series path exists.

Measured: `OL` in resistance mode on all four chains, and 0 V under a torch where a working
6-die chain would have given 5-9 V. Full reasoning in `../measurements/DECISIONS.md` D3.

Samples 1 and 2 are therefore worth **7 and 6 dice**, not 25 and 24.

## Board 3/4 is contaminated

Heavy solder smear around the pads, not cleanable. Confirmed to cause shorts. Every row for
that board carries a flag.

Its readings characterise a **post-process contamination failure**, not the bond. Keep them
in the analysis as a process result, but exclude them from any V_F statistics, otherwise
they will poison the comparison between the other samples.

## Blind

Do not tell me which bonding process belongs to which tag until every reading is in. The
mapping gets joined on afterwards, by sample number.

## Timestamps

The `when` columns stay blank unless you say a time. Rough is fine, and it only matters for
correlating drift against the temperature log.

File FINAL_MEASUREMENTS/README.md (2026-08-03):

# FINAL_MEASUREMENTS

Bench procedures, in order. Self-contained: everything you need at the table is here.

| File | Hardware needed |
|---|---|
| `1_MULTIMETER_ONLY.md` | the 5 boards and the Thsinde 18B+ multimeter |
| `2_ARDUINO_IV.md` | the above, plus Arduino UNO, breadboard, jumpers, resistors, caps, and grabber clips for the chain dice |
| `board-probe-map.png` | where to put the probes, referenced by both |

Do round 1 completely before round 2. Round 1's short-and-bridge screen catches a fault
the Arduino rig cannot see.

Raw data goes into `data/` as it is collected:

```
FINAL_MEASUREMENTS/
└── data/
    ├── R1_meter.csv
    ├── R1_board.csv
    ├── R1_temp.csv
    ├── R1_dies.csv
    ├── R1_channels.csv
    ├── R1_chain_ends.csv
    ├── R1_photos/
    ├── R2_rig.csv
    ├── R2_index.csv
    ├── R2_selfheat.csv
    ├── R2_reverse.csv
    └── R2_sweeps/
```

Hand the folder back raw. No fitting, no averaging, no dropped rows.

Background and reasoning live in `../measurements/`: `EQUIPMENT_DMM.md` (what the meter
can and cannot resolve), `SAMPLES.md` (which tag owns which die, and the n = 4 problem),
`ARDUINO_IV_RIG.md` (rig theory, the sketch, the error budget), `DECISIONS.md` (why no SMU
yet).

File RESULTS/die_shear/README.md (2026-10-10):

# Die shear strength, 8 conditions

Die shear strength per assembly condition, measured by A. Abdelwahab and received on
9 October 2026. Not my measurement. He asked for it to be plotted in the same style as
the daisy chain resistance figure (`../daisy_chain/`).

| File | Contents |
|---|---|
| `die shear strength MPa.xlsx` | Source workbook as received (numbers stored as text, unit written "Mpa") |
| `die_shear_strength.csv` | Same numbers, machine readable |

Columns: `condition` 1-8, `shear_MPa` mean die shear strength, `shear_dev_MPa` the
deviation reported alongside it in the workbook.

## Figure

`../../deliverable/for_ahmed_2026-10-10/die_shear_figure.m` writes
`die_shear_strength_bars` (bars, matching the daisy chain bar figure he pasted back) and
`die_shear_strength` (markers). Same settings as `figures.m`: Helvetica 9 pt, 8.9 cm wide,
600 dpi PNG and vector PDF.

## Against the chain resistance

Conditions 5, 7 and 1 are the three strongest (44.2, 35.2, 32.1 MPa) and also the three
lowest chain resistances (0.22, 0.24, 0.40 ohm). Condition 4 breaks the pattern: mid-range
strength (25.1 MPa) but the highest chain resistance (0.61 ohm). Across all eight,
Spearman rho = -0.57, p = 0.14 (Pearson r = -0.73, p = 0.04). Against the LED channel
yield, rho = 0.59, p = 0.12. Eight points, so a trend at most.

## Caveats

- Number of dies sheared per condition, and whether the deviation is a standard deviation
  or a range, are not in the workbook. The figure calls it deviation, as for the chains.
- Which test vehicle and die type were sheared is not stated. Comparisons with the chain
  data or the LED coupons assume the condition numbering is shared, as before.
- Reported deviation is 6 to 13 % of the mean.

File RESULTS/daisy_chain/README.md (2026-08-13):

# Daisy-chain resistance, dummy dies, v1 board

Total daisy-chain resistance measured by A. Abdelwahab on the DC test structure of the
**v1 PCB**: a chain of six 1 x 1 mm2 Au-coated dummy dies, one chain per assembly
condition, eight conditions.

**This is a separate experiment.** Not my measurement, not my board, not the same session.
It was run on its own on the v1 board, which is the vehicle described in the ECTC 2025
paper (`../../docs/article/references/ECTC2025_Abdelwahab_pick_and_release.pdf`, Section E,
where the same DC structure and the same CDE ResMap 178 and Summit 11K/12K probe station
are described). The LED coupons in the rest of `RESULTS/` are a different test vehicle
measured in a different campaign.

Reproduced here because it is the one dataset that resolves bond resistance directly.

The v2 board carries daisy chains too, but **no daisy-chain measurements were taken from
it**. A layout fault left each chain die's anode floating, so those chains were diagnosed
as dead and excluded rather than characterized (`../README.md`, and
`../../measurements/DECISIONS.md` D3). The only daisy-chain data anywhere in this
repository is the v1 set on this page.

| File | Contents |
|---|---|
| `Total daisy chain resistance (8 conditions).xlsx` | Source workbook as received, 12 August 2026 |
| `daisy_chain_resistance.csv` | Same numbers, machine readable, used by the MATLAB figure |

Columns: `condition` 1-8, `R_total_ohm` mean total chain resistance, `R_dev_ohm` the
deviation reported alongside it in the workbook.

## Why it matters here

The LED coupons could not resolve bond resistance. Re-seating two jumpers moved the fitted
series resistance by 0.84 ohm, against bond resistances of 10 to 100 mohm, so the one-way
ANOVA over conditions was never going to find anything (`../R2_REPORT.md`, and the
repeatability section of the characterization report).

This structure does resolve it. The spread across conditions is 0.39 ohm from the lowest
(condition 5, 0.22 ohm) to the highest (condition 4, 0.61 ohm), carried by 12 joints, so
roughly 30 mohm per joint. The reported deviation is 11 to 20 mohm, about 20 to 35 times
smaller than the between-condition spread.

The ranking agrees with the LED yield ranking:

| | lowest chain resistance | highest chain resistance |
|---|---|---|
| Chain, v1 board | 5 (0.22), 7 (0.24) | 4 (0.61), 3 (0.56) |
| LED channel yield, my coupons | 5 (100 %), 7 (100 %) | 3 (25 %), 4 (66.7 %) |

Spearman rho = -0.92, p = 0.003 across the eight conditions.

**Read that as agreement between assembly conditions, not between two structures on one
coupon.** The two datasets share condition numbering, nothing else: different board,
different session, different operator, no shared hardware. So it is an independent
replication of the process ranking rather than a within-sample cross-check, and it carries
whatever session-to-session drift sits between the two campaigns.

It also rests on the assumption that conditions 1 to 8 mean the same eight recipes in both
datasets. That mapping came with the workbook and has not been independently confirmed. If
it is wrong the correlation is meaningless, so confirm it before the number goes in a paper.

## Figure

`figures.m` in `../../FINAL_MEASUREMENTS/analysis/` reads `daisy_chain_resistance.csv` and
writes `fig9_daisy_chain` (markers, matching the style of figures 4 and 6) and
`fig9b_daisy_chain_bars` (bar variant).

## Caveats

- Chain totals include the v1 board traces and the probe landing, which are common to all
  conditions but were not subtracted. The figures are comparative, not absolute per-joint
  resistances.
- Sample size behind each mean, and whether the deviation is a standard deviation or a
  range, are not recorded in the workbook. The figure calls it deviation for that reason.
- Dummy dies are Au-coated and unpatterned, so the chain measures the joint and the trace
  only. No junction is involved, unlike the LED channels.

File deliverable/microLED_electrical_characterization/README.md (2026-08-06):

# Micro-LED bonding: electrical characterization

Electrical characterization of eight micro-LED assembly conditions across five coupons.
Round 1 screened every channel with a DMM. Round 2 swept the current through each surviving
channel and fitted the diode equation.

## Result in one line

Channel yield and failure mode separate the eight conditions (chi-square, p = 2.2e-4) and
place conditions 5 and 7 ahead of the rest. Series resistance does not separate them, because
the measurement fixture repeats to only 0.84 ohm while bond resistances are 10 to 100 mohm.
A reverse-bias check on 34 channels found one partial shunt, on condition 3, and confirms the
yield ranking rather than adding to it.

| condition | yield | failure modes | assessment |
|---|---|---|---|
| 1 | 83.3 % | open 1, detached 3 | under-bonded |
| 2 | 58.3 % | open 4, detached 6 | under-bonded |
| 3 | 25.0 % | suspect 1, cross-lit 2, open 2, short 4 | over-bonded, 1 shunt confirmed |
| 4 | 66.7 % | suspect 1, cross-lit 1, open 1, short 1 | over-bonded |
| 5 | 100 % | none | in window |
| 6 | 75.0 % | detached 3 | under-bonded |
| 7 | 100 % | none | in window |
| 8 | 83.3 % | short 2 | over-bonded, survivors clean |

## Contents

    report/     the section as .docx and .pdf, figures embedded
    figures/    all 8 figures, PNG at 600 dpi and vector PDF
    matlab/     analysis code, R2025b
    data/       raw measurements, both rounds
    firmware/   the Arduino sketch and the rig wiring diagram

## Reproducing the figures

Open MATLAB in `matlab/`, adjust nothing, and run:

    figures

It reads `../data/`, refits every sweep, writes the eight figures into `figures/`, and prints
every number quoted in the report. Requires the Statistics and Machine Learning Toolbox for
`anova1` and `chi2cdf`.

    readsweep.m   read one sweep CSV
    fitdiode.m    three-parameter fit of V = V0 + n*VT*ln(I) + I*Rs
    collect.m     fit every channel, one table row each
    figures.m     main script

## Data

`data/round1_dmm/` is the DMM screening: one row per channel with the diode voltage and a
verdict. `data/round2_sweeps/` is one CSV per sweep, 63 current levels each, with columns
`level, i_mA, v_die_V, v_anode_V, v_cath_V, v_sense_V, v_gnd_V, vcc_V`. Files ending `_OPEN`
are channels that drew no current, kept because they confirm the round 1 verdict. Files
`heat_os*` are the self-heating study, `verify_100R_*` the fixture verification against a
100 ohm reference, and `_seat2`/`_seat3` the re-seating repeatability runs.

`data/fit_results.csv` holds the fitted parameters for every channel.
`data/R2_REPORT.md` is the working log of the round 2 campaign, including the four
instrument defects found and fixed during it.

## Caveats worth reading before using the numbers

Series resistance is not usable for comparing bonds in this build. Both voltage taps sit on
the breadboard rather than on the Tier-1 probe pads, so the two female-male jumpers fall
inside the measured loop. Re-seating them on an unchanged channel moves R_s by 0.84 ohm,
which is 85 % of the apparent die-to-die spread. Sensing at the probe pads would fix it.

Green and blue fits are not physical. Their ideality factors come out at 3.2 to 4.0 because
the 5 V rail leaves only a 20-fold current range at V_F near 2.8 V. Red only.

Reverse bias was measured as a shunt check, not as a leakage measurement. The die sits in a
divider with the 100 kohm and the meter reads across the die, so the floor is the meter's own
10 Mohm input impedance: it detects shunts below about 10 Mohm and cannot grade healthy dies.
Reading millivolts across the sense resistor instead does not work with a handheld meter, since
1 nA through 98 kohm is 0.1 mV. Results in `data/R2_leakage.csv`.

TLM, van der Pauw and impedance spectroscopy need instruments that were not available.

The DCL6 and DCL12 daisy chains read open on every coupon. The chain routes each die's
top-left pad to its top-right pad, and with the dice rotated 90 degrees those are the red and
blue cathodes, so every element is a pair of back-to-back diodes. Layout fault in this coupon
revision, not a bonding failure.

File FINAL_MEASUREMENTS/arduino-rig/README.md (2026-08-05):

# Arduino I-V rig, build drawings

Offline copy of the build sheet for `../2_ARDUINO_IV.md`. Drawn hole for hole, so nothing
in it needs interpreting against the ASCII in the markdown.

| File | What it is |
|---|---|
| `build.pdf` | the whole sheet: both drawings, wiring tables, build order, capacitor sizing. 4 pages, 330 x 470 mm |
| `build.html` | same thing, opens in a browser with no network |
| `breadboard.pdf` / `.png` / `.svg` | the full rig, one page, native size. Print this for the bench |
| `closeup.pdf` / `.png` / `.svg` | the RETURN cluster and both rails at 2x |

Breadboard conventions used in the drawings:

- Rail holes follow the column numbers. First one under column 3, five in a row, a one-hole
  gap, five more. Columns 8, 14, 20 and 26 are gaps and have no rail hole.
- Bottom outer rail is FORCE, bottom inner rail is GND. Both top rails and the whole top
  half of the board stay empty.
- Only eight hole numbers matter: A4, C4, D4, E4 and A8, B8, D8, E8. Everything else is a
  rail, where any hole on the strip is the same node.

Regenerate from `gen.py` / `closeup.py` if the wiring changes; they emit the SVGs, and the
PDFs come from `rsvg-convert -f pdf` and headless Chrome respectively.

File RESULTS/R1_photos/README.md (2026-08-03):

# R1_photos

| File | Board tag | Samples |
|---|---|---|
| `2026-08-03_board1_overview.jpg` | 1 | 1 |
| `2026-08-03_board2_overview.jpg` | 2 | 2 |
| `2026-08-03_board3-4_overview.jpg` | 3/4 | 3 (D1-D4), 4 (D5-D8) |
| `2026-08-03_board5-6_overview.jpg` | 5/6 | 5 (D1-D4), 6 (D5-D8) |
| `2026-08-03_board7-8_overview.jpg` | 7/8 | 7 (D1-D4), 8 (D5-D8) |

Strips of the LED row, about 1600 x 350 each.

## Do not use these photos to decide whether a die is present

An attempt was made to read die presence from them. It got **two of three calls wrong**:

| Site | Photo said | Truth (physical board) |
|---|---|---|
| board 2, D7 | absent | **present** |
| board 5/6, D6 | present | **absent** |
| board 1, D5 | absent | not yet confirmed |

The failure mode is that at the zoom needed to resolve a 0.95 mm die against its pads,
these images are already blurred, and glare on a bare pad looks like a die while a dark
die looks like bare board. The two errors went in opposite directions, so there is no
correction to apply. The photo-derived presence data has been discarded.

**Presence, alignment and solder all come from the physical board.** These photos are
useful only as a record of what the boards looked like on the day, and for locating
features.

Anything worth documenting properly needs a microscope pass at roughly 20x, one frame per
die.

## Observation that does survive

Boards 5/6 and 7/8 show noticeably more white residue around the die sites than 1, 2 and
3/4. Consistent with flux. Not a defect on its own, but worth remembering if those four
samples read oddly.

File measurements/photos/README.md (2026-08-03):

# measurements/photos

Reference photos for the lab sessions. Filenames are `YYYY-MM-DD_subject.jpg`.

| File | Date | What it shows |
|---|---|---|
| `2026-08-03_samples-01-08_overview.jpg` | 2026-08-03 | All 8 bonded samples on 5 v2 PCBs, laid out with paper number tags. Basis for `SAMPLES.md`. |
| `2026-08-03_dmm-thsinde-18B-plus.jpg` | 2026-08-03 | The digital multimeter available for phase 1. Basis for `EQUIPMENT_DMM.md`. |
| `2026-08-03_microcontrollers.jpg` | 2026-08-03 | Arduino UNO R3 (ATmega328P-PU) and Arduino Nano ESP32 (u-blox NORA-W106). Basis for `ARDUINO_IV_RIG.md`. The UNO is the one used; the Nano ESP32 is not suitable for the analog path. |

Notes on the overview photo:

- The handwritten purple marks are the sample numbers and, on PCBs C/D/E, the
  left/right divider line between the two bonding conditions on that PCB.
- Confirmed by the user, not readable from the photo: samples 1 and 2 (PCBs A and B)
  have D1 - D8 plus both daisy chains; samples 3 - 8 have **only** their four
  individual LEDs bonded, no chains. The DoE array, TLM ladders and Van der Pauw
  cloverleaves are bare ENIG on every board.
- Resolution is not sufficient to call per-site alignment or solder state. Do not use
  this photo as the site map. That comes from a microscope pass
  (`PHASE1_DMM_ONLY.md` step 0).

Photos to add as they are taken:

- One whole-board top shot per PCB, in focus, with the number tag in frame
- One close-up per LED daisy chain (DC-A N=6 and DC-B N=12)
- One close-up per anomaly (missing die, tombstone, bridge, shifted die), named
  `YYYY-MM-DD_<sample>_<site>_<anomaly>.jpg`

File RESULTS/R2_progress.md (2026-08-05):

# Round 2 progress and what to measure next

Written by the analysis side. Operator does not edit this file.

## Immediate next action

**Put the 100 Ω dummy back and run the closing verify for board 3/4.**
FORCE rail to B4, both F/M jumpers off the PCB. This is outstanding and it blocks
the sample 4 result below. Boards 1 and 2 each closed at 98.4 and 98.6 Ω; board 3/4
has no closing bracket at all yet.

## Done

| board | samples | live channels | opens confirmed | verify open | verify close |
|---|---|---|---|---|---|
| 1 | s1 | 20 | 1 | pass | 98.398 Ω, −0.72 mV |
| 2 | s2 | 14 | 4 | — | 98.626 Ω, −0.78 mV |
| 3/4 | s3, s4 | 12 | 0 (11 skipped on R1 verdicts) | — | **MISSING** |

Rig constants in use: `R_SENSE = 98.61`, `VCC_DMM = 5.034`, `VBG_X1024 = 1110.70`,
`ADC_OFFSET = 0.0144`, `OVERSAMPLE = 64`.

## Red R_s so far, the only colour with physical fits

| sample | n | mean | sd |
|---|---|---|---|
| 1 | 6 | 10.770 Ω | 0.785 |
| 2 | 5 | 11.120 Ω | 0.344 |
| 3 | 1 | 10.918 Ω | — |
| 4 | 3 | **12.788 Ω** | 0.650 |

s1 vs s2 not significant (t = −0.92). **s1 vs s4 t = −3.81 and s2 vs s4 t = −4.87, both
significant.** Provisional until board 3/4 has a closing verify.

Green and blue are not usable for R_s: green fits at ideality 3.2–4.0, which is
unphysical, because the 5 V rail only gives a 20× current range at V_F ≈ 2.8 V.
Blue at 2.2–2.5 is borderline. Report red only.

## Board 5/6 — next board. 21 channels, all pass on R1

Sample 5 = D1–D4, sample 6 = D5–D8. **D8 is die_detached, skip all three of it.**
This is the cleanest board in the set and should give a full n = 4 on sample 5.

| sample | die | FORCE pin | RETURN R / G / B |
|---|---|---|---|
| 5 | D1 | 2 | 1 / 3 / 4 |
| 5 | D2 | 6 | 5 / 7 / 8 |
| 5 | D3 | 10 | 9 / 11 / 12 |
| 5 | D4 | 14 | 13 / 15 / 16 |
| 6 | D5 | 18 | 17 / 19 / 20 |
| 6 | D6 | 22 | 21 / 23 / 24 |
| 6 | D7 | 26 | 25 / 27 / 28 |
| 6 | D8 | — | detached, skip |

## Board 7/8 — last board. 22 channels

Sample 7 = D1–D4 (all 12 pass), sample 8 = D5–D8.
**Skip s8 D5 green and s8 D8 red, both shorts on R1 (0.002 V).**

| sample | die | FORCE pin | RETURN R / G / B |
|---|---|---|---|
| 7 | D1 | 2 | 1 / 3 / 4 |
| 7 | D2 | 6 | 5 / 7 / 8 |
| 7 | D3 | 10 | 9 / 11 / 12 |
| 7 | D4 | 14 | 13 / 15 / 16 |
| 8 | D5 | 18 | 17 / **skip G** / 20 |
| 8 | D6 | 22 | 21 / 23 / 24 |
| 8 | D7 | 26 | 25 / 27 / 28 |
| 8 | D8 | 30 | **skip R** / 31 / 32 |

Samples 7 and 8 will both give a full n = 4 on red. With 5, 6, 7, 8 complete you get
four samples at n = 4 and two at n = 5–6, which is the strongest the DoE can be.

## Still outstanding

- **NTC readings.** Never taken, for any board. Four per board, read with the DMM off
  the TH1–TH4 pads. They separate ambient drift from self-heating and cannot be
  reconstructed later. Take them before each board goes on the bench.
- **Seat repeats.** One channel per board re-seated and re-swept as `_seat2` and
  `_seat3`. None taken. This is what measures the F/M jumper and contact term, and
  after the 2.9 Ω link episode it is not optional.
- **Opening verify** for boards 2 and 3/4 was never run, only closing. From board 5/6
  on, run the dummy at both ends of every board.

## Known open items on the rig

- ~1.3 mV residual on red not fully accounted for.
- Green ideality unphysical, headroom limited, not fixable at 5 V.
- Link contact resistance 0.4–0.5 Ω, outside the measurement loops but a sign of
  worn sockets. C4 is where the cathode jumper lives.
- USB path ~2.8 Ω, rail sag 20–46 mV, divided out per point by the bandgap.

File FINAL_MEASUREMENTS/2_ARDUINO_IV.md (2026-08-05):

# Round 2 — do this

Do round 1 first.

For single readings, read the value out to me. For sweeps, save the serial output to a file
and send me the file. I write everything into `../RESULTS/`. You write nothing.

Background if you ever want it: `../measurements/ARDUINO_IV_RIG.md`.

---

## Parts — built from what you have

**One of each. No duplicates needed.**

### Resistors — 8, all different values

| Value | Where it goes |
|---|---|
| 10 kΩ | bank, on D2 |
| 5.1 kΩ | bank, on D3 |
| 2 kΩ | bank, on D4 |
| 1 kΩ | bank, on D5 |
| 330 Ω | bank, on D6 |
| 220 Ω | bank, on D7 |
| 100 Ω | sense resistor, RETURN to GND |
| 100 kΩ | reverse leakage, step 6 only |

### Capacitors — 3

Any three from **68 nF / 72 nF / 66 nF / 60 nF / 33 nF / 31 nF**. The value is not
critical, they are only charge reservoirs for the ADC. One from each of A0, A1, A2 to GND.

### Everything else

| Part | How many |
|---|---|
| Breadboard | 1 |
| Male-to-male jumpers | 11 |
| Female-to-male jumpers | 2, plus spares |
| Arduino **UNO** | 1, not the Nano ESP32 |
| USB cable + computer | 1 |

### What this bank gives you

Currents on a red channel, one branch at a time:

| Branch | Current |
|---|---|
| 10 kΩ | 0.32 mA |
| 5.1 kΩ | 0.62 mA |
| 2 kΩ | 1.53 mA |
| 1 kΩ | 2.93 mA |
| 330 Ω | 7.49 mA |
| 220 Ω | 10.06 mA |
| all six | 15.6 mA |

63 combinations spanning 0.32 to 15.6 mA. Port D total peaks at 15.6 mA against its 30 mA
limit, and the busiest single pin carries 7.6 mA against 40 mA. Comfortable.

Tolerance does not matter anywhere. Step 1 measures the 100 Ω against the board's 0.1 %
reference, and every sweep point measures its own current. Use the same physical 100 Ω
every session and do not hold it between sweeps.

## Pads and pins

Left to right under each die:

| Pad | Is | Header pin, die Dn |
|---|---|---|
| 1 | red cathode, **common to all 8 dice** | 4n−3 |
| 2 | anode | 4n−2 |
| 3 | green cathode | 4n−1 |
| 4 | blue cathode | 4n |

So D1 is pins 1,2,3,4 and D2 is 5,6,7,8, up to D8 at 29,30,31,32.

---

## Build

Six resistors, one leg each into UNO **D2-D7**, other legs all into one breadboard rail
called **FORCE**:

```
  D2 ──[10k ]──┐
  D3 ──[4k7 ]──┤
  D4 ──[2k2 ]──┤
  D5 ──[1k  ]──┼── FORCE
  D6 ──[470 ]──┤
  D7 ──[220 ]──┘
```

Then:

```
  FORCE ────F/M jumper────► die's ANODE pin (4n−2)

  die's CATHODE pin ────F/M jumper────► breadboard node RETURN
        red   = pin 4n−3
        green = pin 4n−1
        blue  = pin 4n

  RETURN ──[100 Ω]── UNO GND

  FORCE  ─────────► UNO A1     (+ cap from A1 to GND)
  RETURN ─────────► UNO A0     (+ cap from A0 to GND)
  RETURN ─────────► UNO A2     (+ cap from A2 to GND)
```

No series resistors on the ADC inputs. They were only there for protection and filtering,
and neither is needed: nothing in this rig can exceed 5 V because it all runs off the UNO's
own rail, and the caps do the filtering. A cap straight onto the pin is the better
arrangement anyway, since it feeds the sample-and-hold from a low impedance.

UNO GND touches the board once, through the 100 Ω. No second ground wire.

---

## Step 1 — calibrate the sense resistor

DMM: dial 4 clicks clockwise from OFF, tips together, `RANGE` once, `REL Δ` once.

- Touch the two ends of `100R LOAD` on the board. **Read out.**
- Touch the two ends of your loose 100 Ω. **Read out.**
- Touch each of the six bank resistors. **Read out each.**
- Touch the 100 kΩ. **Read out.**

## Step 2 — measure the 5 V rail

DMM: dial **2 clicks** clockwise from OFF (DC volts). Leave on `AUTO`.

- Red probe on the UNO's `5V` pin, black on `GND`, USB plugged in. **Read out.**
- Repeat later with the rig sweeping at full current. **Read out.**

## Step 3 — verify the rig on a plain resistor

No LED in the loop yet.

- Put your loose 100 Ω where the die would be: `FORCE` to one leg, other leg to `RETURN`.
- Flash the sketch from `../measurements/ARDUINO_IV_RIG.md` section 5, with `R_SENSE` and
  `VCC` from steps 1 and 2.
- Capture the serial output:

```
stty -F /dev/ttyACM0 115200 raw -echo
cat /dev/ttyACM0 | tee verify.csv
```

- **Send me `verify.csv`.**

Do this at the start of every session.

## Step 4 — self-heating check

Pick one healthy red channel.

- Sweep it three times, changing only `OVERSAMPLE` in the sketch: **64**, then **256**,
  then **1024**.
- Save each to its own file: `heat_os64.csv`, `heat_os256.csv`, `heat_os1024.csv`.
- **Send me all three.**

Wait for my answer before step 5. It sets the `OVERSAMPLE` value you use for everything.

## Step 5 — sweep every channel

For each die, for each of red, green, blue:

- Move the two jumpers: `FORCE` to the anode pin, `RETURN` to that channel's cathode pin.
- Run one sweep.
- Save as `s<sample>_<die>_<channel>_seat1.csv`, e.g. `s1_D1_R_seat1.csv`.

Skip the four detached dice: board 1 D5, board 2 D1, board 2 D7, board 5/6 D8.

Re-seat and re-sweep **one channel per board** a second and third time, saving as
`_seat2` and `_seat3`.

Log the four NTC resistances with the DMM each time you pick up a different board, same as
round 1 step 3. **Read those out.**

Work through the boards in rotation, not one board at a time.

**Send me the files.**

## Step 6 — reverse leakage

Unplug the bank from `FORCE` first.

```
  UNO 5V ──[100 kΩ]──► die's CATHODE pin
  UNO GND ──────────► die's ANODE pin (4n−2)
```

DMM: dial 2 clicks clockwise from OFF (DC volts), `RANGE` until it shows `mV`.

- Probes across the 100 kΩ.
- Wait 5 seconds, then **read out the millivolts.**
- Red channel on every die. Green and blue only where round 1 flagged something.

---

## Done

Tell me when every step is finished. Only then, tell me which bonding process each tag was.

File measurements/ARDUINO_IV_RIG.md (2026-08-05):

# Arduino I-V rig: a real current sweep without a bench PSU

Photo: `photos/2026-08-03_microcontrollers.jpg`

Sits between `PHASE1_DMM_ONLY.md` (screening only) and `MEASUREMENT_PLAN.md` (bench PSU).
Built from an Arduino UNO, six resistors, a breadboard and jumper wires.

---

## 1. Why this beats the 9 V battery, and what it actually buys

The battery gives one or two operating points. That is not enough, and the reason is
worth stating precisely. An LED's forward characteristic is

```
  V(I)  =  V₀ + n·V_T·ln(I / I_s)  +  I·R_s
```

The first term is the diode's exponential; the second is the series resistance, which is
where the bond lives. Between 1 mA and 10 mA the exponential term alone contributes
n·V_T·ln(10) ≈ 0.12 V for n = 2, while I·R_s contributes about 0.05 V for R_s = 5 Ω.
**A two-point slope mixes them and reports neither.** You need enough points to fit and
separate them, which is exactly what a microcontroller gives you and a battery does not.

The standard separation, once you have a sweep:

```
   dV        n·V_T                    dV
  ────  =  ─────── + R_s     →    I·────  =  n·V_T + I·R_s
   dI          I                     dI
```

Plot I·(dV/dI) against I: the slope is R_s and the intercept is n·V_T. Or fit V(I)
directly by nonlinear least squares over all points, which is better conditioned.

| | 9 V battery + R | Arduino UNO rig |
|---|---|---|
| Points per channel | 1 - 2, by hand | 63, automatic |
| R_s extraction | impossible | yes, by fit |
| Self-heating control | none | pulsed, fixed duty cycle |
| 4-wire Kelvin sensing | needs 2 DMMs and 4 hands | native, 2 ADC channels |
| Time for 120 channels | days | about 4 h |
| Repeats and statistics | no | free |

## 2. Which board

**Use the UNO.** ATmega328P at 16 MHz, 5 V rail, 10-bit ADC.

**Do not use the Nano ESP32 in the measurement path.** Two reasons:

1. 3.3 V logic. A green or blue channel is V_F ≈ 3.0 V at 10 mA. After the current-sense
   drop there is no headroom left to push current through anything. Even red is marginal.
2. The ESP32-S3 ADC has substantial integral nonlinearity and a per-chip calibration
   curve. It is fine for reading a potentiometer, poor for a 0.1 % DC measurement.

Keep the Nano ESP32 for logging or wireless if you want it, driven over serial by the
UNO. It contributes nothing to the analog front end.

## 3. Resolution: what a 10-bit ADC can actually do here

Raw, a 10-bit ADC on a 5 V reference is 4.88 mV per LSB. Useless. Two techniques fix it.

**Oversampling.** Averaging 4ⁿ samples and right-shifting by n adds n effective bits,
provided there is at least 1 LSB of noise to act as dither, which a real circuit always
has (AVR121). 256 samples, shift 4, gives **14 effective bits**:

```
  5.0 V / 16384  =  0.305 mV effective LSB
```

**Set the ADC clock properly.** Arduino's default prescaler is /128, giving 125 kHz and
104 µs per conversion. 256 samples then take 27 ms, too long for a short pulse. Prescaler
/32 gives 500 kHz and 26 µs, so 256 samples take 6.7 ms. That is outside the datasheet's
50 - 200 kHz "maximum resolution" window, but with oversampling on top it is the better
trade. Verify empirically: sweep once at each prescaler and check R_s agrees.

### What that resolution means for the science

With R_sense = 100 Ω:

| Quantity | Resolution |
|---|---|
| Current | 0.305 mV / 100 Ω = **3 µA** (0.03 % at 10 mA) |
| V across the die | 0.43 mV (two channels subtracted, noise adds in quadrature) |
| R_total from a single point at 10 mA | 43 mΩ |
| **R_s from a 63-point fit** | **about ±10 mΩ, 1σ** |

That last number is the headline. A fit over the full sweep beats a single point by
roughly √N, and ±10 mΩ is genuinely at the scale of a solder bond.

**Read that as precision, not accuracy.** It is the statistical scatter of the fit.
Systematic errors are larger and are covered in section 7. For comparing eight samples
that is the right figure of merit, because systematics that are common to all samples
cancel in the comparison.

## 4. Circuit

### 4.1 Current source: a binary-weighted resistor bank on six pins

No op-amp, no transistor, no DAC. Six digital pins, each through a resistor, into the
common anode. A pin set to `OUTPUT`+`HIGH` sources current; set to `INPUT` it is
high-impedance and contributes nothing. 2⁶ − 1 = **63 distinct current levels**.

| Pin | Resistor | Approx. current (red, V_F ≈ 2.0 V) |
|---|---|---|
| D2 | 10 kΩ | 0.20 mA |
| D3 | 4.7 kΩ | 0.43 mA |
| D4 | 2.2 kΩ | 0.91 mA |
| D5 | 1 kΩ | 2.0 mA |
| D6 | 470 Ω | 4.3 mA |
| D7 | 220 Ω | 9.1 mA |

Currents assume 5 V minus V_F minus the 100 Ω sense drop. They do not need to be
accurate: **every point measures its own current.** The resistors only have to give a
spread of levels, so any E12 values you have will do.

Green and blue at V_F ≈ 3.0 V leave less headroom, so the same bank tops out around
10 mA instead of 17 mA. That is fine, 10 mA is the target anyway.

Pin loading, from the ATmega328P absolute maximum ratings table (see
`../docs/datasheets/INSTRUMENTS.md`):

| Limit | Value |
|---|---|
| DC current per I/O pin | 40.0 mA |
| DC current VCC and GND pins | 200.0 mA |
| **Maximum current per port** | **±30 mA** |

**The per-port limit binds, not the per-pin one.** Arduino D0 - D7 are all Port D, so the
six bank branches share one 30 mA budget. Solving the bank against the loop
(I = G·(5 − V_F) / (1 + 100·G), with G = 8.44 mS) gives **13.7 mA total on a red channel
and 9.2 mA on blue**, both under half the limit, and the largest single branch (220 Ω)
carries about 7.4 mA against a 40 mA pin limit. Adding branches means redoing that sum.
The pin's own output impedance (roughly 25 Ω) sits in series with each resistor and
shifts the levels slightly, which does not matter since the current is measured.

*Upgrade, if you have one NPN transistor:* PWM on a timer at 62.5 kHz into an RC filter,
into the base of an emitter follower with an emitter resistor, gives a smoothly
programmable current sink with 8-bit control. More elegant, and it removes the headroom
tangle. The resistor bank needs no active parts and is the safer starting point.

### 4.2 Sensing: 4-wire Kelvin, using the board's own probe pads

This is the part that makes the measurement worth doing, and the v2 board was laid out
for it. Force current through the **south header pins**, sense voltage at the **Tier-1
probe pads** on the same nets. The 0.1 - 0.5 Ω of header trace, jumper wire and contact
resistance then sits outside the sense loop and disappears from the result. The ADC draws
essentially no current, so the sense wires carry no drop.

Three ADC channels:

| Channel | Connect to | Reads |
|---|---|---|
| `A1` | `PP_Dn_A` probe pad (y = 81, x = 8.5 + 10·(n−1)) | anode-side potential |
| `A0` | `PP_Dn_Kc` probe pad (K_R at x = 14.5 + 10·(n−1)) | cathode-side potential |
| `A2` | breadboard node at the top of R_sense | current |

```
  V_die  =  V(A1) − V(A0)                 (Kelvin, trace and contact excluded)
  I      =  V(A2) / R_sense
```

**A2 is separate from A0 on purpose.** A0 sits at the probe pad, upstream of the header
pin, the jumper wire and the contact. A2 sits directly across R_sense. Using A0 for the
current would fold all of those resistances back into the measurement and undo the
Kelvin arrangement.

### 4.3 R_sense: use the board's own 100 Ω

`R_EIS_LOAD` is a Yageo RT0603BRB07100RL, **100 Ω at 0.1 % tolerance**, already on the
board with probe access at (75.5, 35.39), nets `EIS_LOAD_A` / `EIS_LOAD_B`. It is on the
board precisely to be a calibration artefact. Wiring it into the return path makes the
current measurement traceable to 0.1 % with no calibration step of your own.

If you would rather keep the board's resistor out of the loop, use an external 1 % metal
film 100 Ω and measure it against `R_EIS_LOAD` with the DMM (REL-zeroed, both on the
600 Ω range, take the ratio). Do not trust a 2-wire DMM reading of a 100 Ω resistor to
better than about 0.5 % on its own.

### 4.4 Full wiring for one channel

```
  UNO D2 ──[10k ]──┐
  UNO D3 ──[4k7 ]──┤
  UNO D4 ──[2k2 ]──┤
  UNO D5 ──[1k  ]──┼──── H_S pin 4(n−1)+1     (anode, common LED_VCC net)
  UNO D6 ──[470 ]──┤
  UNO D7 ──[220 ]──┘

                        PP_Dn_A  ─────────► A1      (+ cap to GND)
                            │
                       [ die Dn, channel c ]
                            │
                        PP_Dn_Kc ─────────► A0      (+ cap to GND)
                            │
  H_S pin 4(n−1)+1+k ───────┴──┬──[ R_sense 100 Ω ]── UNO GND
                               │
                               └─────────► A2       (+ cap to GND)
```

**Revised 2026-08-03: no series resistors, and the cap value is not critical.** The series
resistors were for protection and anti-aliasing. Neither is needed, because everything in
this rig runs off the UNO's own 5 V rail so no input can exceed it, and the caps alone do
the filtering. A cap straight onto the pin is in fact the better arrangement: it feeds the
sample-and-hold from a low impedance, which is what the datasheet's "approximately 10k or
less" recommendation is really asking for.

Anything from about 30 nF to 1 µF works. The cap has to recharge through the bank between
current levels, so with the largest branch at 10 kΩ and a 68 nF cap the time constant is
0.7 ms, comfortably inside the sketch's 2 ms settle.

Connect the UNO GND to the board **once**. Do not create a second ground path.

### 4.5 Working through 24 channels per board

The anode is a common net, so the force side never moves. Plug a ribbon from the south
header to a breadboard; then for each channel you move **one jumper** (the cathode into
R_sense) and **two sense needles** (to that die's probe pads). 24 channels per PCB, about
2 min each including the sweep, so roughly 50 min per PCB and 4 h for all five.
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

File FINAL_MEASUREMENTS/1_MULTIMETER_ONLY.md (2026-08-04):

# Round 1 — do this

Read every value out to me. I write it into `../RESULTS/`. You write nothing.

Say `OL` when the meter says `OL`. Read digits exactly, trailing zeros included.
If you re-land and get a different number, give me both.

Pad locations: `board-probe-map.png`.
Background, if you ever want it: `../docs/datasheets/INSTRUMENTS.md`.

---

## Setup

- Black probe into `COM`.
- Red probe into the far right jack (`VΩHz`).
- Dial: from `OFF`, **4 clicks clockwise**. Land on the orange cluster at the top.
- Wrist strap on. Hold boards by the edges.

**Getting to a function (measured on your meter):**

Turning the dial one click away and back always lands on **resistance**. From there:

| Want | Presses of `SELECT` from resistance |
|---|---|
| resistance `Ω` | 0 |
| continuity (wifi icon) | 1 |
| diode | 2 |
| capacitance `nF` | 3 |

So whenever a step below says a function, first flick the dial off and back, then press
`SELECT` that many times.

Work through the boards in rotation, not one board at a time.

## Pin numbers (bottom black header)

| Die | A | K_G | K_B | K_R |
|---|---|---|---|---|
| D1 | 1 | 2 | 3 | 4 |
| D2 | 5 | 6 | 7 | 8 |
| D3 | 9 | 10 | 11 | 12 |
| D4 | 13 | 14 | 15 | 16 |
| D5 | 17 | 18 | 19 | 20 |
| D6 | 21 | 22 | 23 | 24 |
| D7 | 25 | 26 | 27 | 28 |
| D8 | 29 | 30 | 31 | 32 |

---

## Step 1 — meter check (once)

**1a**
- Touch the two probe tips together and hold.
- Press `RANGE` **once**.
- **Read out the number.**
- Press `REL Δ` **once**. Display goes to `0.0`.

**1b**
- Pull the tips apart, touch them together again. **Read out.**
- Do that **10 times**.

**1c**
- Touch the two ends of the small grey part marked `100R LOAD`. **Read out.**

**1d**
- Touch the two gold pads marked `SHORT`. **Read out.**

**1e**
- Press `REL Δ` **once**. REL indicator goes off.
- Hold `RANGE` for **2 seconds**. `AUTO` appears.
- Hold the probes apart in the air. Press `RANGE` **once**.
- Touch the two gold pads marked `OPEN`. **Read out.**

**1f**
- Flick the dial off and back. Press `SELECT` **twice** (diode).
- Touch the two ends of `100R LOAD`. **Read out.**
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

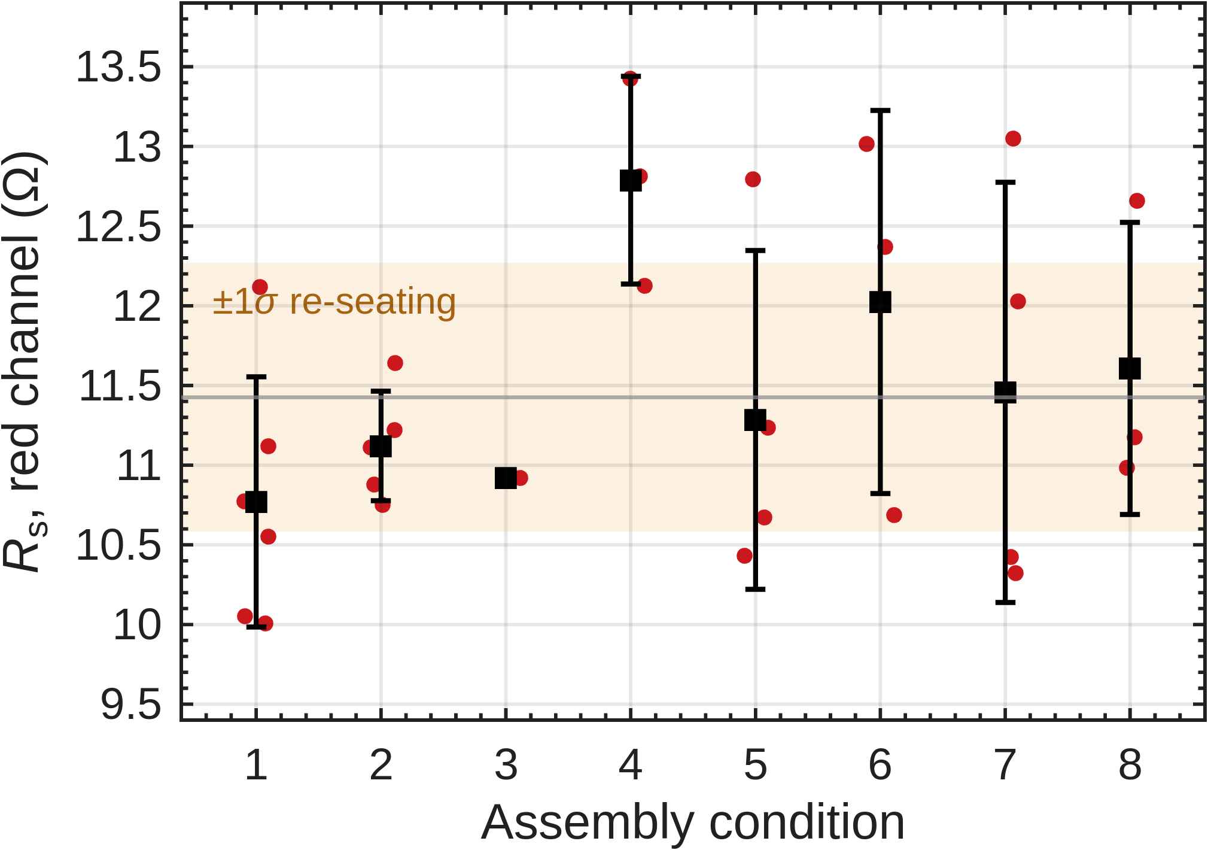
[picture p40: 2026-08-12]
FINAL_MEASUREMENTS/analysis/figures/fig4_rs_by_condition.png

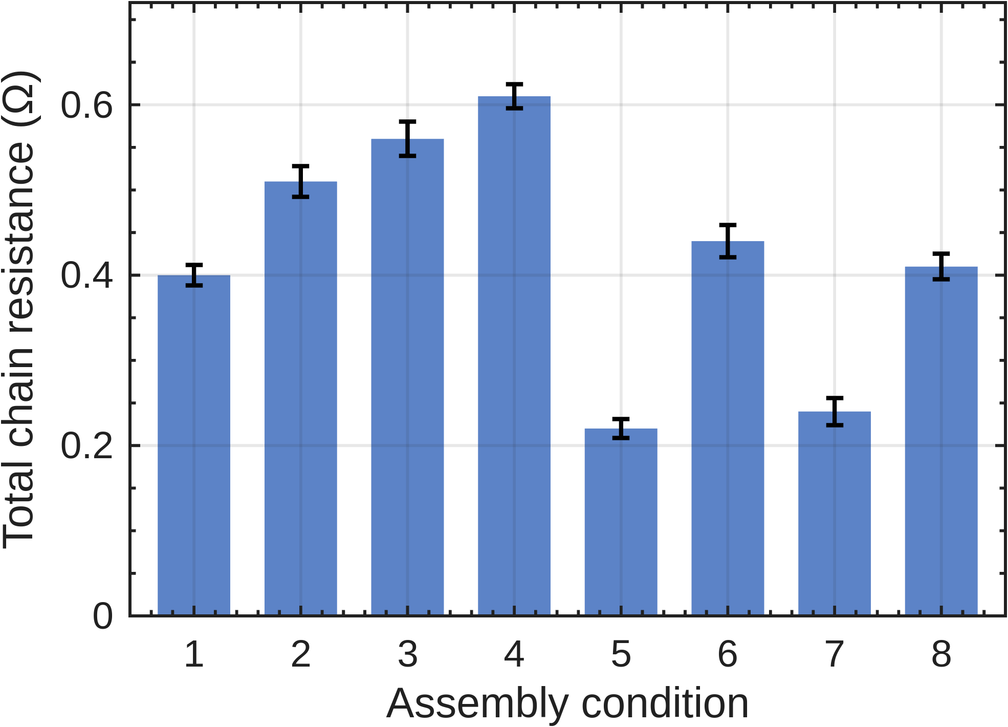
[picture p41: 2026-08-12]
FINAL_MEASUREMENTS/analysis/figures/fig9b_daisy_chain_bars.png

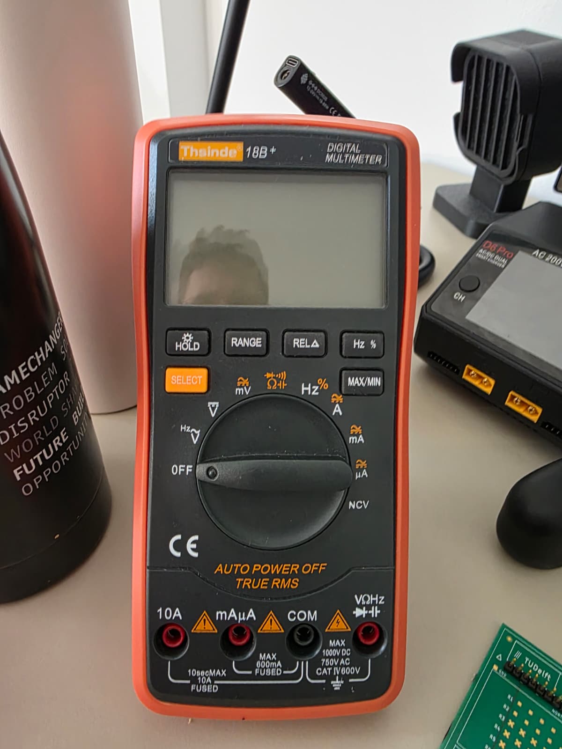
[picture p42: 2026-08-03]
measurements/photos/2026-08-03_dmm-thsinde-18B-plus.jpg

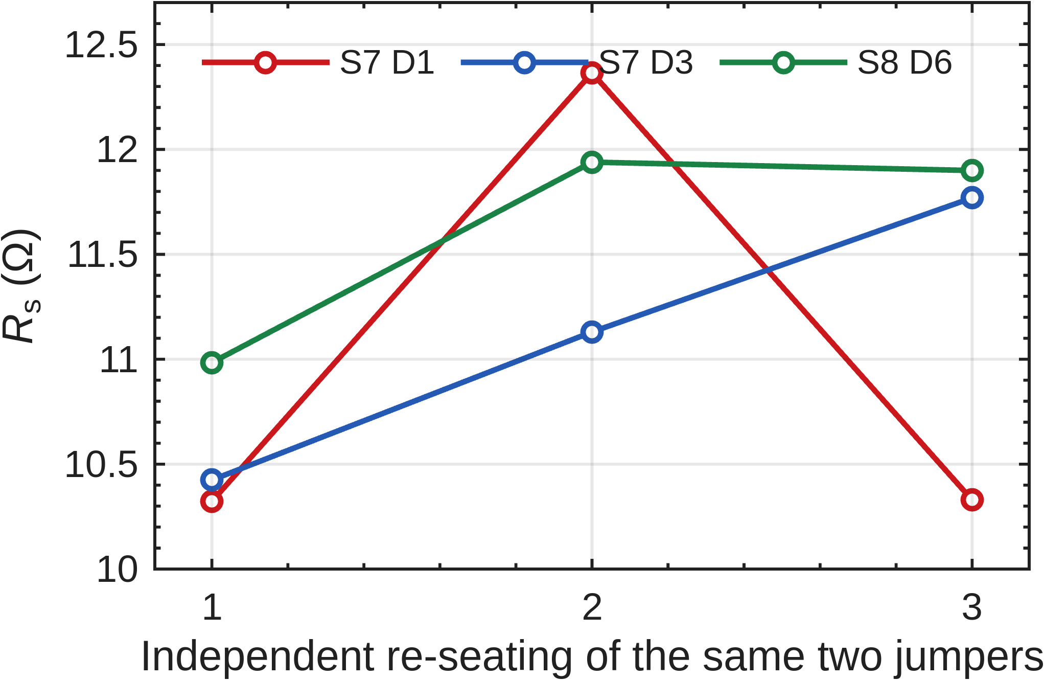
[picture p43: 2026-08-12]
FINAL_MEASUREMENTS/analysis/figures/fig5_reseat_repeatability.png

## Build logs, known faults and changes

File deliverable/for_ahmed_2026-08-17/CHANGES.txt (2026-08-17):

Edits to the electrical characterization section
Daniel Tyukov, 17 August 2026

Edited directly in the file you sent. Only the electrical characterization section was
touched. Citations are red, everything else is plain body text so it reads normally.

REFERENCES ADDED

  [R1]  daisy chain structure, and the ResMap sheet resistance
  [R2]  the ideality window of 1.2 to 2.4
  [R3]  the parallel leakage path, in the forward sweep and again under reverse bias
  [R4]  the 5 ms pulse, and the pulse-duration argument in the self-heating subsection
  [R5]  the forward-voltage temperature coefficient

  The full list is in red at the end of the document. Delete that block once the entries
  are in EndNote. The same five are in method_references.bib if importing is easier.

CORRECTIONS

  Shunt fraction. The meter sources 1.42 mA in diode mode, not 1 mA. That was measured
  directly as 0.142 V across a 100 ohm 0.1 % reference. At the 1.781 V reading the shunt
  carries 0.62 mA and the junction gets 0.80 mA, so the shunt takes about 44 %. The
  paragraph beginning "One numerical correction:" was an editing note in the first person
  and has been deleted; its 61 % assumed a 1 mA source. The measurement setup table and
  the reverse bias subsection now say 1.42 mA as well.

  Variance share. The draft had both 83 % and 85 %. From the unrounded standard
  deviations, 0.843 squared over 0.9147 squared is 84.9 %, so 85 %.

  Self-heating. The stated inputs of 200 K/W and -2 mV/K give 0.80 ohm, not 1.2, so the
  agreement to within 25 % did not hold. I inverted the calculation instead: the measured
  1.49 ohm implies a junction-to-board thermal resistance of about 370 K/W, or an 11 K
  rise at 28.4 mW. That is ordinary for a 0404 package on two-layer FR-4. The conclusion
  is unchanged, heating sets in between 20 and 80 ms and 5 ms is safe.

SMALLER FIXES

  Chi-square sentence was missing a word, now "assembly condition and channel outcome
  (p = 2.2 x 10-4)".
  "(2^6-1 =63)" spaced as "2^6 - 1 = 63".
  "the series resistance. which is the sum" had a full stop mid-sentence, now a comma.
  "2.86x 10-8" closed up to "2.86 x 10-8".
  Daisy chain figure caption now says what was measured and what the bars are.

TWO THINGS I FLAGGED LAST TIME THAT WERE WRONG

  The equation symbols are fine. They are equation objects, so they vanish when the file
  is read as plain text, which is how I checked. In Word they render correctly. Left
  untouched.

  The Section B, C and D cross-references are also correct. The subsections letter A
  channel screening, B forward characteristics, C defect detection, D measurement
  repeatability, E self-heating, F reverse bias, G summary. Left untouched.

  Sorry for the noise on both.

A PDF of the edited file is included so you can see the red without opening Word.

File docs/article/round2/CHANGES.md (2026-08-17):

# Edits to the electrical-characterization section

Daniel Tyukov, 17 August 2026. Source: `Article_from_Ahmed_2026-08-17.docx`. Output: `Article_edited_DanielTyukov_2026-08-17.docx`.

Numbers are paragraph indices in the source file. Citations are red, everything else is plain so it reads as normal body text.

- 31  daisy-chain and sheet-resistance sentences: added [R1] twice, closed the gap in '2.86× 10⁻⁸'
- 36  daisy-chain figure caption expanded to say what was measured
- 42  'between assembly condition and channel p = ...' was missing a word. Now 'channel outcome (p = ...)'
- 60  5 ms pulsing: added [R4], which reports self-heating bias for pulses of 10 ms and longer. Also spaced '(2⁶−1 =63)' as '2⁶ − 1 = 63'
- 64  equation legend: 'series resistance. which is the sum' had a full stop mid-sentence, changed to a comma. The symbols were left untouched
- 81  shunt fraction corrected. The meter sources 1.42 mA in diode mode, not 1 mA, so the shunt takes 0.62 mA and the junction 0.80 mA. Added [R3]
- 82  ideality window: added [R2], which reads n = 1 as radiative, n = 2 as SRH through defect levels and n > 2 as deep-level-assisted tunnelling
- 83  DELETED the paragraph beginning 'One numerical correction:'. It was an editing note written in the first person, and its 61 % figure assumed a 1 mA test current
- 88  variance share: the draft gave both 83 % and 85 %. From the unrounded standard deviations, 0.843² / 0.9147² = 84.9 %, so 85 %
- 95  pulse-duration argument: added [R4]
- 99  self-heating estimate rewritten. The stated inputs (200 K/W, −2 mV/K, 2.01 V) give 0.80 Ω, not 1.2 Ω, so the claimed agreement to within 25 % did not hold. Inverted the calculation instead: the measured 1.49 Ω implies about 370 K/W. Added [R5]
- 102 reverse-bias check: added [R3]
- 104 diode-test current corrected to 1.42 mA here as well
- T3  measurement-setup table: DMM diode-test excitation corrected from ≈1 mA to 1.42 mA, measured as 0.142 V across a 100 Ω 0.1 % reference
- END appended a red reference key listing [R1] to [R5] in full, to be deleted once the entries are in EndNote

## Checked and deliberately left alone

- The inline symbols in the equation legend, and in the sentence about the three correlated parameters. They are OMML objects: invisible to text extraction, correct in Word. I flagged these as missing in my previous mail. They are not missing.
- The Section B, C and D cross-references. They are correct as written. The subsections letter A Channel screening, B Forward characteristics, C Defect detection, D Measurement repeatability, E Self-heating, F Reverse bias, G Summary. I flagged these too, also wrongly.

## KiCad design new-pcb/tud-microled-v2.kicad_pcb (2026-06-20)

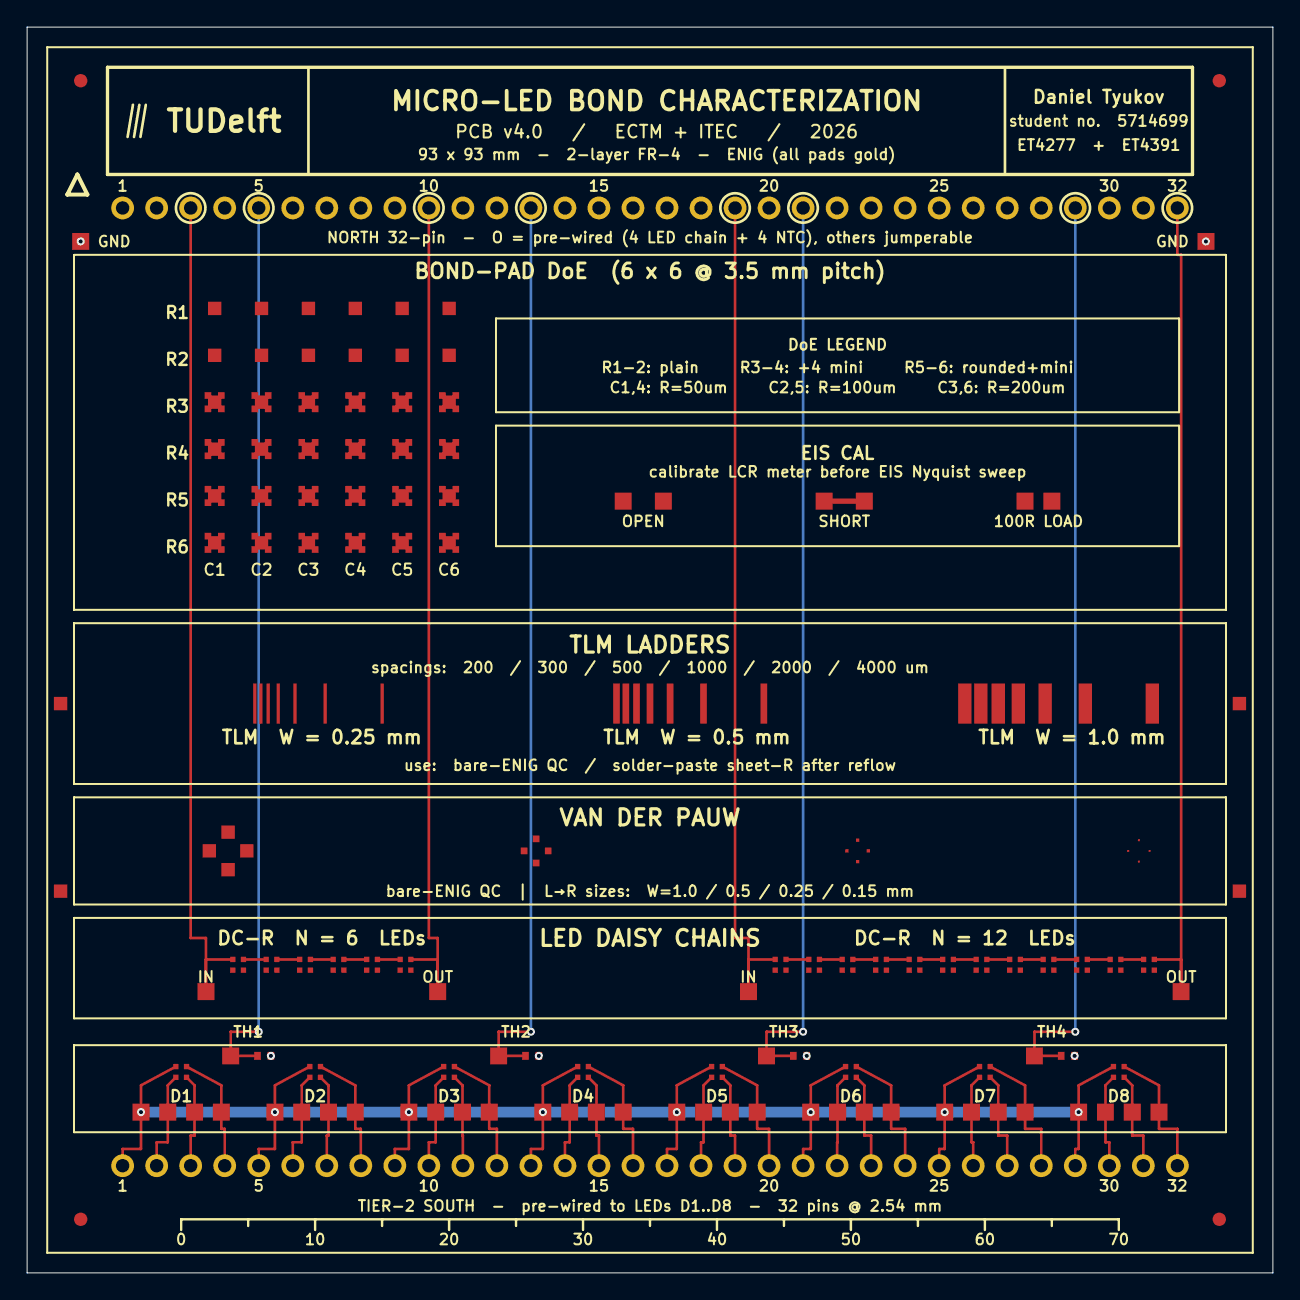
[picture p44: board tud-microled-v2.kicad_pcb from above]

Board: 2 copper layers, 93.0 x 93.0 mm, 130 parts (0 on the bottom side), 51 nets.

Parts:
BP_R1C1: BP_R1C1; BondPad_DoE
BP_R1C2: BP_R1C2; BondPad_DoE
BP_R1C3: BP_R1C3; BondPad_DoE
BP_R1C4: BP_R1C4; BondPad_DoE
BP_R1C5: BP_R1C5; BondPad_DoE
BP_R1C6: BP_R1C6; BondPad_DoE
BP_R2C1: BP_R2C1; BondPad_DoE
BP_R2C2: BP_R2C2; BondPad_DoE
BP_R2C3: BP_R2C3; BondPad_DoE
BP_R2C4: BP_R2C4; BondPad_DoE
BP_R2C5: BP_R2C5; BondPad_DoE
BP_R2C6: BP_R2C6; BondPad_DoE
BP_R3C1: BP_R3C1; BondPad_DoE
BP_R3C2: BP_R3C2; BondPad_DoE
BP_R3C3: BP_R3C3; BondPad_DoE
BP_R3C4: BP_R3C4; BondPad_DoE
BP_R3C5: BP_R3C5; BondPad_DoE
BP_R3C6: BP_R3C6; BondPad_DoE
BP_R4C1: BP_R4C1; BondPad_DoE
BP_R4C2: BP_R4C2; BondPad_DoE
BP_R4C3: BP_R4C3; BondPad_DoE
BP_R4C4: BP_R4C4; BondPad_DoE
BP_R4C5: BP_R4C5; BondPad_DoE
BP_R4C6: BP_R4C6; BondPad_DoE
BP_R5C1: BP_R5C1; BondPad_DoE
BP_R5C2: BP_R5C2; BondPad_DoE
BP_R5C3: BP_R5C3; BondPad_DoE
BP_R5C4: BP_R5C4; BondPad_DoE
BP_R5C5: BP_R5C5; BondPad_DoE
BP_R5C6: BP_R5C6; BondPad_DoE
BP_R6C1: BP_R6C1; BondPad_DoE
BP_R6C2: BP_R6C2; BondPad_DoE
BP_R6C3: BP_R6C3; BondPad_DoE
BP_R6C4: BP_R6C4; BondPad_DoE
BP_R6C5: BP_R6C5; BondPad_DoE
BP_R6C6: BP_R6C6; BondPad_DoE
D1, D2, D3, D4, D5, D6, D7, D8: WL-SFCC RGB (DNP); WL-SFCC_0404
DCL6_L1, DCL6_L2, DCL6_L3, DCL6_L4, DCL6_L5, DCL6_L6, DCL12_L1, DCL12_L2, DCL12_L3, DCL12_L4, DCL12_L5, DCL12_L6, DCL12_L7, DCL12_L8, DCL12_L9, DCL12_L10, DCL12_L11, DCL12_L12: WL-SFCC RGB (DNP); WL-SFCC_0404
FID1: FID1; Fiducial_1mm
FID2: FID2; Fiducial_1mm
FID3: FID3; Fiducial_1mm
FID4: FID4; Fiducial_1mm
H_N: TSW-140-07-G-S; Header_2.54mm
H_S: TSW-140-07-G-S; Header_2.54mm
PP_D1_A: PP_D1_A; Probe_1.27mm
PP_D1_KB: PP_D1_KB; Probe_1.27mm
PP_D1_KG: PP_D1_KG; Probe_1.27mm
PP_D1_KR: PP_D1_KR; Probe_1.27mm
PP_D2_A: PP_D2_A; Probe_1.27mm
PP_D2_KB: PP_D2_KB; Probe_1.27mm
PP_D2_KG: PP_D2_KG; Probe_1.27mm
PP_D2_KR: PP_D2_KR; Probe_1.27mm
PP_D3_A: PP_D3_A; Probe_1.27mm
PP_D3_KB: PP_D3_KB; Probe_1.27mm
PP_D3_KG: PP_D3_KG; Probe_1.27mm
PP_D3_KR: PP_D3_KR; Probe_1.27mm
PP_D4_A: PP_D4_A; Probe_1.27mm
PP_D4_KB: PP_D4_KB; Probe_1.27mm
PP_D4_KG: PP_D4_KG; Probe_1.27mm
PP_D4_KR: PP_D4_KR; Probe_1.27mm
PP_D5_A: PP_D5_A; Probe_1.27mm
PP_D5_KB: PP_D5_KB; Probe_1.27mm
PP_D5_KG: PP_D5_KG; Probe_1.27mm
PP_D5_KR: PP_D5_KR; Probe_1.27mm
PP_D6_A: PP_D6_A; Probe_1.27mm
PP_D6_KB: PP_D6_KB; Probe_1.27mm
PP_D6_KG: PP_D6_KG; Probe_1.27mm
PP_D6_KR: PP_D6_KR; Probe_1.27mm
PP_D7_A: PP_D7_A; Probe_1.27mm
PP_D7_KB: PP_D7_KB; Probe_1.27mm
PP_D7_KG: PP_D7_KG; Probe_1.27mm
PP_D7_KR: PP_D7_KR; Probe_1.27mm
PP_D8_A: PP_D8_A; Probe_1.27mm
PP_D8_KB: PP_D8_KB; Probe_1.27mm
PP_D8_KG: PP_D8_KG; Probe_1.27mm
PP_D8_KR: PP_D8_KR; Probe_1.27mm
PP_DCL6_IN: PP_DCL6_IN; Probe_1.27mm
PP_DCL6_OUT: PP_DCL6_OUT; Probe_1.27mm
PP_DCL12_IN: PP_DCL12_IN; Probe_1.27mm
PP_DCL12_OUT: PP_DCL12_OUT; Probe_1.27mm
PP_EIS_OPEN_A: PP_EIS_OPEN_A; Probe_1.27mm
PP_EIS_OPEN_B: PP_EIS_OPEN_B; Probe_1.27mm
PP_EIS_SHORT_A: PP_EIS_SHORT_A; Probe_1.27mm
PP_EIS_SHORT_B: PP_EIS_SHORT_B; Probe_1.27mm
PP_GND1: PP_GND1; Probe_1.27mm
PP_GND2: PP_GND2; Probe_1.27mm
PP_NTC1: PP_NTC1; Probe_1.27mm
PP_NTC2: PP_NTC2; Probe_1.27mm
PP_NTC3: PP_NTC3; Probe_1.27mm
PP_NTC4: PP_NTC4; Probe_1.27mm
R_EIS_LOAD: RT0603BRB07100RL; EIS_Load_0603
TC1: TC1; TC_Pad_1mm
TC2: TC2; TC_Pad_1mm
TC3: TC3; TC_Pad_1mm
TC4: TC4; TC_Pad_1mm
TH1, TH2, TH3, TH4: NTCG104BH103HT1; NTC_0402
TLM_W0.5: TLM_W0.5; TLM
TLM_W0.25: TLM_W0.25; TLM
TLM_W1.0: TLM_W1.0; TLM
VDP_W0.5: VDP_W0.5; VDP
VDP_W0.15: VDP_W0.15; VDP
VDP_W0.25: VDP_W0.25; VDP
VDP_W1.0: VDP_W1.0; VDP

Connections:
DCL6_IN: DCL6_L1.1, H_N.3, PP_DCL6_IN.1
DCL6_J1: DCL6_L1.2, DCL6_L2.1
DCL6_J2: DCL6_L2.2, DCL6_L3.1
DCL6_J3: DCL6_L3.2, DCL6_L4.1
DCL6_J4: DCL6_L4.2, DCL6_L5.1
DCL6_J5: DCL6_L5.2, DCL6_L6.1
DCL6_OUT: DCL6_L6.2, H_N.10, PP_DCL6_OUT.1
DCL12_IN: DCL12_L1.1, H_N.19, PP_DCL12_IN.1
DCL12_J1: DCL12_L1.2, DCL12_L2.1
DCL12_J2: DCL12_L2.2, DCL12_L3.1
DCL12_J3: DCL12_L3.2, DCL12_L4.1
DCL12_J4: DCL12_L4.2, DCL12_L5.1
DCL12_J5: DCL12_L5.2, DCL12_L6.1
DCL12_J6: DCL12_L6.2, DCL12_L7.1
DCL12_J7: DCL12_L7.2, DCL12_L8.1
DCL12_J8: DCL12_L8.2, DCL12_L9.1
DCL12_J9: DCL12_L9.2, DCL12_L10.1
DCL12_J10: DCL12_L10.2, DCL12_L11.1
DCL12_J11: DCL12_L11.2, DCL12_L12.1
DCL12_OUT: DCL12_L12.2, H_N.32, PP_DCL12_OUT.1
EIS_SHORT: PP_EIS_SHORT_A.1, PP_EIS_SHORT_B.1
GND: PP_GND1.1, PP_GND2.1, TH1.2, TH2.2, TH3.2, TH4.2
LED1_KB: D1.3, H_S.3, PP_D1_KB.1
LED1_KG: D1.4, H_S.2, PP_D1_KG.1
LED1_KR: D1.2, H_S.4, PP_D1_KR.1
LED2_KB: D2.3, H_S.7, PP_D2_KB.1
LED2_KG: D2.4, H_S.6, PP_D2_KG.1
LED2_KR: D2.2, H_S.8, PP_D2_KR.1
LED3_KB: D3.3, H_S.11, PP_D3_KB.1
LED3_KG: D3.4, H_S.10, PP_D3_KG.1
LED3_KR: D3.2, H_S.12, PP_D3_KR.1
LED4_KB: D4.3, H_S.15, PP_D4_KB.1
LED4_KG: D4.4, H_S.14, PP_D4_KG.1
LED4_KR: D4.2, H_S.16, PP_D4_KR.1
LED5_KB: D5.3, H_S.19, PP_D5_KB.1
LED5_KG: D5.4, H_S.18, PP_D5_KG.1
LED5_KR: D5.2, H_S.20, PP_D5_KR.1
LED6_KB: D6.3, H_S.23, PP_D6_KB.1
LED6_KG: D6.4, H_S.22, PP_D6_KG.1
LED6_KR: D6.2, H_S.24, PP_D6_KR.1
LED7_KB: D7.3, H_S.27, PP_D7_KB.1
LED7_KG: D7.4, H_S.26, PP_D7_KG.1
LED7_KR: D7.2, H_S.28, PP_D7_KR.1
LED8_KB: D8.3, H_S.31, PP_D8_KB.1
LED8_KG: D8.4, H_S.30, PP_D8_KG.1
LED8_KR: D8.2, H_S.32, PP_D8_KR.1
LED_VCC: D1.1, D2.1, D3.1, D4.1, D5.1, D6.1, D7.1, D8.1, H_S.1, H_S.5, H_S.9, H_S.13, H_S.17, H_S.21, H_S.25, H_S.29, PP_D1_A.1, PP_D2_A.1, PP_D3_A.1, PP_D4_A.1, PP_D5_A.1, PP_D6_A.1, PP_D7_A.1, PP_D8_A.1
NTC1: H_N.5, PP_NTC1.1, TH1.1
NTC2: H_N.13, PP_NTC2.1, TH2.1
NTC3: H_N.21, PP_NTC3.1, TH3.1
NTC4: H_N.29, PP_NTC4.1, TH4.1

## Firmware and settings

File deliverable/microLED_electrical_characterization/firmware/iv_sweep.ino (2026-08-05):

// ===========================================================================
//  iv_sweep.ino  -  micro-LED bond characterisation, I-V sweep rig
//  Arduino UNO R3 (ATmega328P @ 16 MHz).  AVCC is the ADC reference.
//
//  Wiring:  FINAL_MEASUREMENTS/arduino-rig/breadboard.pdf
//    FORCE   six resistors on D2..D7 -> FORCE rail -> die anode, header pin 4n-2
//    RETURN  die cathode -> RETURN node -> R_SENSE -> UNO GND
//    A1 reads FORCE.  A0 and A2 both read RETURN: they are the same node in
//    this build, so v_cath and v_sense are equal by construction. That is
//    intended for round 2 and it is why R_s from this rig is die + wiring.
//    A3 reads the GND rail, in the same five-hole group as the 100 R's lower
//    leg. The current is then a DIFFERENCE, i = (A2 - A3)/R_SENSE, which
//    cancels the ADC's own offset and takes the GND jumper's IR drop out of
//    the measurement. Verified necessary: step 3 on a 100 R dummy showed a
//    common ~10 mV offset on every channel, worth 26 % of the current at the
//    bottom of the sweep. See RESULTS/R2_meter.csv, fault1_adc_offset.
//
//  Capture one file per channel:
//    stty -F /dev/ttyACM0 115200 raw -echo
//    cat /dev/ttyACM0 | tee s1_D1_R_seat1.csv
// ===========================================================================

// --------------------------------------------------------- bench constants
// Both of these come from RESULTS/R2_meter.csv. Re-measure VCC every session.
const float R_SENSE = 98.61f;   // ohm. 99.0 read, x0.99602 transferred from the
                                // board's 0.1 % R_EIS_LOAD. Same physical
                                // resistor every session, do not swap it.
const float VCC_DMM = 5.034f;   // V, measured at the 5V pin with the rig idle.

// Bandgap calibration. Leave at 0 for the first flash: setup() prints the
// number to paste in here. Once set, every sweep point divides by the LIVE
// rail instead of this constant, which removes rail sag from R_s. Sag is
// current-dependent, so it lands on R_s and does not cancel within a sweep.
const float VBG_X1024 = 1110.70f;  // = VCC_DMM x bandgap raw 220.641, taken idle

// Common-mode ADC offset. Every channel reads LOW by this. Measured three
// independent ways on the 100 R dummy (constant mV deficit vs theory; AVR pin
// HIGH consistency; and the model-free series-divider fit v_anode = K*v_sense
// + c, which needs no assumption beyond "two resistors in series"). It cancels
// in v_die, which is a difference, but NOT in the current. Re-measure it from
// the step 3 verify sweep at the start of every session.
const float ADC_OFFSET = 0.0144f;   // V

const uint16_t OVERSAMPLE = 64;    // step 4 decided this: 5 ms on-time, no measurable heating
const uint16_t SETTLE_MS  = 2;     // after switching current, before reading
const uint16_t COOL_MS    = 250;   // current OFF between points. Fixed duty cycle.

// D2=10k  D3=5.1k  D4=2k  D5=1k  D6=330  D7=220
const uint8_t SRC_PIN[6] = {2, 3, 4, 5, 6, 7};

char label[40] = "";               // whatever you type between channels

// ------------------------------------------------------------------ current
// A pin set OUTPUT+HIGH sources through its resistor. Set INPUT it is high-Z
// and contributes nothing, which is what makes 6 pins give 63 distinct levels.
void setLevel(uint8_t mask) {
  for (uint8_t i = 0; i < 6; i++) {
    if (mask & (1 << i)) { pinMode(SRC_PIN[i], OUTPUT); digitalWrite(SRC_PIN[i], HIGH); }
    else                 { pinMode(SRC_PIN[i], INPUT); }
  }
}

// --------------------------------------------------------------- rail track
// Measures the 1.1 V bandgap against AVCC. The bandgap's absolute value is only
// specified to 1.0-1.2 V, but we do not need absolute: calibrated once against
// the DMM, its ratio between readings tracks AVCC exactly.
// Returns a FLOAT on purpose. Truncating this to an integer count quantises
// the rail to 1/220 = 0.45 %, and since vcc multiplies every voltage that put a
// 2-3 mV noise floor on v_die and cost a factor of ~13 in the R_s fit precision.
// 64 samples, undivided, gives 1/64 count and makes the term negligible.
float bandgapRaw() {
  ADMUX = _BV(REFS0) | _BV(MUX3) | _BV(MUX2) | _BV(MUX1);
  delayMicroseconds(500);                       // bandgap source is high-Z
  ADCSRA |= _BV(ADSC);                          // throw the first one away
  while (bit_is_set(ADCSRA, ADSC)) { }
  (void)ADCL; (void)ADCH;
  uint32_t acc = 0;
  for (uint8_t i = 0; i < 64; i++) {
    ADCSRA |= _BV(ADSC);
    while (bit_is_set(ADCSRA, ADSC)) { }
    uint8_t lo = ADCL, hi = ADCH;
    acc += (uint16_t)((hi << 8) | lo);
  }
  return (float)acc / 64.0f;
}

float readVcc() {
  if (VBG_X1024 <= 0.0f) return VCC_DMM;        // uncalibrated: fall back
  return VBG_X1024 / bandgapRaw();
}

// ------------------------------------------------------------------ sensing
// The four channels are interleaved sample by sample, not read in four blocks.
// A block read puts ~7 ms between v_anode and v_cath, during which the die is
// heating and its forward voltage is falling. Interleaving spreads all four
// evenly over the same window, so drift is common to them and cancels in both
// differences we care about, v_die and (v_sense - v_gnd).
//
// No dummy read after a mux change. That is not an assumption: the step 3
// diagnostic swept prescaler /32, /64, /128 against discard on and off, six
// combinations, and every one gave the same answer to within noise. The 68 nF
// cap on each pin is what makes that true.
void sampleQuad(uint32_t &acc1, uint32_t &acc0, uint32_t &acc2, uint32_t &acc3) {
  acc1 = acc0 = acc2 = acc3 = 0;
  analogRead(A1); analogRead(A0); analogRead(A2); analogRead(A3);   // discarded
  for (uint16_t i = 0; i < OVERSAMPLE; i++) {
    acc1 += analogRead(A1);
    acc0 += analogRead(A0);
    acc2 += analogRead(A2);
    acc3 += analogRead(A3);
  }
}

// Straight division by 1024*OVERSAMPLE. The original sketch right-shifted by a
// hardcoded SHIFT=4, which is only correct at OVERSAMPLE=256. Step 4 asks you
// to change OVERSAMPLE to 64 and 1024, which would have silently rescaled every
// voltage by 4x and 1/4x and made the self-heating check meaningless.
float volts(uint32_t acc, float vcc) {
  return (float)acc * vcc / (1024.0f * (float)OVERSAMPLE) + ADC_OFFSET;
}

// A3 sits on the GND rail at about 0 V. A channel reading LOW cannot report a
// negative count, so the offset is clipped there and v_gnd is not recoverable.
// That is why subtracting A3 does not fix the current, and why the offset is
// added explicitly instead. A3 stays as a monitor: if the GND path ever goes
// bad, v_gnd climbs out of the clip and shows up.
float voltsRaw(uint32_t acc, float vcc) {
  return (float)acc * vcc / (1024.0f * (float)OVERSAMPLE);
}

// ------------------------------------------------------------------- serial
void readLabel() {
  uint8_t n = 0;
  unsigned long t0 = millis();
  while (millis() - t0 < 50 || n == 0) {
    if (Serial.available()) {
      char c = Serial.read();
      if (c == '\n' || c == '\r') { if (n) break; else continue; }
      if (n < sizeof(label) - 1) label[n++] = c;
      t0 = millis();
    }
  }
  label[n] = '\0';
}

void printHeader() {
  Serial.print(F("# iv_sweep  R_SENSE=")); Serial.print(R_SENSE, 2);
  Serial.print(F("  VCC_DMM="));           Serial.print(VCC_DMM, 3);
  Serial.print(F("  OVERSAMPLE="));        Serial.print(OVERSAMPLE);
  Serial.print(F("  prescaler=/32  adc_off=")); Serial.print(ADC_OFFSET * 1000.0f, 2);
  Serial.print(F("mV  vbg_cal=")); Serial.println(VBG_X1024, 1);
  Serial.print(F("# rail_tracking="));
  Serial.println(VBG_X1024 > 0 ? F("live") : F("fixed VCC_DMM"));
  if (label[0]) { Serial.print(F("# label=")); Serial.println(label); }
  Serial.println(F("level,i_mA,v_die_V,v_anode_V,v_cath_V,v_sense_V,v_gnd_V,vcc_V"));
}

// --------------------------------------------------------------------- main
void setup() {
  Serial.begin(115200);
  ADCSRA = (ADCSRA & ~0x07) | 0x05;      // prescaler /32 -> 500 kHz, 26 us/conv
  setLevel(0);
  delay(200);
  float raw = bandgapRaw();
  Serial.println(F("# ---------------------------------------------------------"));
  if (VBG_X1024 <= 0.0f) {
    Serial.print(F("# BANDGAP NOT CALIBRATED. Raw count now: ")); Serial.println(raw, 3);
    Serial.print(F("# Set VBG_X1024 = ")); Serial.print(VCC_DMM * raw, 2);
    Serial.println(F("  and reflash, then the rail is tracked per point."));
    Serial.println(F("# Do that with the rig idle and the DMM agreeing with VCC_DMM."));
  } else {
    Serial.print(F("# bandgap raw ")); Serial.print(raw, 3);
    Serial.print(F("  ->  rail now ")); Serial.print(VBG_X1024 / raw, 4);
    Serial.println(F(" V"));
  }
  Serial.println(F("# ---------------------------------------------------------"));
}

void loop() {
  printHeader();

  float i_max = 0.0f, vdie_at_max = 0.0f, vcc_min = 99.0f, vcc_max = 0.0f, vg_max = 0.0f;

  for (uint8_t m = 1; m < 64; m++) {
    setLevel(m);
    delay(SETTLE_MS);

    uint32_t a1, a0, a2, a3;
    sampleQuad(a1, a0, a2, a3);
    float vcc = readVcc();               // read while still loaded, to catch sag
    setLevel(0);                         // current OFF immediately

    float va = volts(a1, vcc);
    float vk = volts(a0, vcc);
    float vs = volts(a2, vcc);
    float vg = voltsRaw(a3, vcc);       // GND rail, uncorrected: it is clipped
    float i  = vs / R_SENSE;            // vs already has ADC_OFFSET added back

    if (i > i_max) { i_max = i; vdie_at_max = va - vk; }
    if (vg > vg_max) vg_max = vg;
    if (vcc < vcc_min) vcc_min = vcc;
    if (vcc > vcc_max) vcc_max = vcc;

    Serial.print(m);                Serial.print(',');
    Serial.print(i * 1000.0f, 4);   Serial.print(',');
    Serial.print(va - vk, 5);       Serial.print(',');
    Serial.print(va, 5);            Serial.print(',');
    Serial.print(vk, 5);            Serial.print(',');
    Serial.print(vs, 5);            Serial.print(',');
    Serial.print(vg, 5);            Serial.print(',');
    Serial.println(vcc, 4);

    delay(COOL_MS);
  }

  setLevel(0);

  // Bench sanity checks. These catch the two mistakes that actually happen.
  Serial.print(F("# i_max=")); Serial.print(i_max * 1000.0f, 3);
  Serial.print(F(" mA  v_die@i_max=")); Serial.print(vdie_at_max, 4);
  Serial.print(F(" V  rail ")); Serial.print(vcc_min, 4);
  Serial.print(F(" to ")); Serial.print(vcc_max, 4);
  Serial.print(F(" V  sag=")); Serial.print((vcc_max - vcc_min) * 1000.0f, 1);
  Serial.println(F(" mV"));
  if (i_max < 0.0002f)
    Serial.println(F("# WARNING no current. Open loop: check both F/M jumpers, "
                     "the link E4-E8, and that GND reaches the rail."));
  else if (vdie_at_max < 0.4f)
    Serial.println(F("# WARNING v_die near zero at full current. Shorted die, or "
                     "FORCE and RETURN jumpers on the same header pin."));
  if (vg_max > 0.005f)
    Serial.println(F("# WARNING GND rail is more than 5 mV above the UNO's ground. "
                     "Reseat the GND jumper: its IR drop is entering the current."));
  if ((vcc_max - vcc_min) > 0.010f)
    Serial.println(F("# WARNING rail sag over 10 mV. Shorter or thicker USB cable, "
                     "and make sure VBG_X1024 is set so the sag is divided out."));

  Serial.println();
  Serial.println(F("# sweep done. Move the two F/M jumpers, then type the next "
                   "channel label (e.g. s1_D1_R_seat1) and press enter."));
  readLabel();
}

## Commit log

2026-05-16 Initial commit: reorganize repo, vendor Würth WL-SFCC library, draft v2 plan
    - Move PDFs and the Ahmed work-plan note into docs/.
    - Move the existing 'Electrical test + LED-no solder' KiCad project into old-pcb/ (v1, ECTC-2025 paper).
    - Scaffold new-pcb/ for v2 design work.
    - Vendor official Würth Elektronik KiCad library for the WL-SFCC family
    (symbol, both 0404 footprints, both STEP 3D models) so the design is
    self-contained.
    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
    [Electrical test + LED-no solder.kicad_pcb]
2026-05-16 Add electrical characterization plan (ports, lab tools, workflow)
    ELECTRICAL_CHARACTERIZATION.md covers:
    - Measurement strategy (Kelvin sensing, reference structures to isolate bond contribution from LED V_F)
    - What we can measure: V_F, I-V slope (R_s), daisy chain R, TLM rho_c, VDP R_sh, per-site bond R, leakage, lifetime drift, failure-mode signatures
    - 3-tier connector strategy: 1.27mm probe pads, 2.54mm headers, optional FFC edge connector
    - Lab tooling (day-one vs nice-to-have, TU Delft EKL equivalents)
    - End-to-end workflow diagram for cross-material comparison studies
    - Cross-references from PCB_DESIGN_PLAN.md and root README.
2026-05-16 v2 PCB: fab-ready 100x80mm bond-characterization board
    DRC: 0 violations, 0 unconnected pads, 0 footprint errors.
    Generated procedurally by new-pcb/tools/generate_pcb_text.py (re-runnable).
    Footprints: 153 placed. Nets: 139.
    Structures (top → bottom):
    - 6x6 DoE bond-pad array (36 sites) with shape/radius/mini-pad sweep
    - 3 TLM ladders W=0.25/0.5/1.0mm, 6 contact spacings (5-200 µm)
    - 4 VDP cloverleaves (arm widths 1.0/0.5/0.25/0.1 mm)
    - 2 daisy chains N=6, N=12 with 4-wire probe pads (N=24 deferred to v2.1)
    - 8 Würth WL-SFCC 0404 RGB LEDs with common-anode bus on B.Cu
    - 4 corner fiducials, asymmetric L-mark, 2x 30-pin headers, mm ruler
    Fab outputs in new-pcb/fab/: Gerbers (zipped), STE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
    [tud-microled-v2-bom.csv, tud-microled-v2.kicad_pcb, tud-microled-v2.kicad_sch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]
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2026-05-16 Refactor PCB design settings and update electrical test configuration
    - Added a new user-edited backup file for the PCB design with comprehensive settings for design defaults, rules, and dimensions.
    - Updated the electrical test configuration by modifying the column widths to ensure proper alignment and sorting in the report.
    [tud-microled-v2.kicad_pcb]
2026-05-16 v3 PCB: 100x100mm board, full silkscreen polish, south header pre-wired
    Major changes vs prior v2:
    - Board grown 100x80 -> 100x100 mm (room for proper silkscreen)
    - Title block redesigned with 3 zones (TUDelft mark / project / student info)
    - Section frames around DoE, TLM, VDP, DC, LED rows
    - DoE LEGEND box on right with row/column descriptions
    - mm ruler at the bottom
    - Back-side silkscreen: FABRICATION, ASSEMBLY, DESIGNER, TIER-2 SOUTH PINOUT
    - Daniel Tyukov / student no. 5714699 / ET4277 + ET4391 in title + back
    - TUDelft mark (stylized flame + wordmark) on both sides
    - South header extended to 32 pins, covers ALL 8 LEDs (D1-D8 x A/KG/KB/KR)
    - South pre-wired via short F.Cu Manhattan rou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
    [tud-microled-v2-B_Courtyard.gbr, tud-microled-v2-B_Cu.gbl, tud-microled-v2-B_Fab.gbr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]
2026-05-16 v3.5: add hardware for advanced LED electrical characterization
    NEW HARDWARE ADDITIONS (LED-characterization focused):
    - 4 x 0402 NTC thermistors (TH1-TH4) between LED pairs for V_F-TSP and
    aging temperature monitoring (Murata NCP15XH103 or compatible)
    - 4 x GND probe pads at corners with vias to B.Cu GND pour
    - 4 x 1mm gold TC pads (TC1-TC4) at TLM/VDP section edges for soldering
    fine-wire thermocouples during reflow profile measurement
    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
    [tud-microled-v2-B_Courtyard.gbr, tud-microled-v2-B_Cu.gbl, tud-microled-v2-B_Fab.gbr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]
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2026-05-16 Refactor PCB generation scripts and update layout parameters
    - Updated `gen_aisler_bom.py` to use CSV for reading component positions, improving readability and maintainability.
    - Adjusted lane Y positions in `generate_pcb_text.py` to ensure proper spacing and compliance with design rules.
    - Modified segment endpoints in `tud-microled-v2.kicad_pcb` to reflect updated lane positions, enhancing layout accuracy.
    - Updated binary PDF file for the PCB design to reflect the latest changes.
    [tud-microled-v2-B_Courtyard.gbr, tud-microled-v2-B_Cu.gbl, tud-microled-v2-B_Fab.gbr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]
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2026-05-16 Implement feature X to enhance user experience and fix bug Y in module Z
    [tud-microled-v2.step]
2026-05-16 Refresh docs + add schematic PNG to README
    - Root README.md: replace stale "not started" status table with current
    fab-ready state; embed board top/bottom renders + schematic PNG; add
    Aisler order quickstart.
    - new-pcb/README.md: full rewrite — folder layout now includes the
    generated PCB/schematic + fab outputs, design summary table, quickstart
    for KiCad workflow.
    - docs/datasheets/README.md: fix Würth header alternative MPN reference
    (61301021121 → 61304011121 single-row).
    - new-pcb/V2_DESIGN_NOTES.md: mark "schematic = future iteration" as
    superseded; document the new single-sheet A2 schematic added in v4.0.7
    via KiCad MCP tools (36 components, 129 net labels, 24 NC mar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
2026-05-17 Add new reference paper and update download links in references_to_download.md
    - Added "Polymer Reinforced Solder Paste for Improving Impact Energy Absorption Capability in Micro LED Laser-Assisted Mass Transfer" PDF to the references.
    - Updated the download links for all cited papers to clarify access via TU Delft proxy and indicate which references are bundled in the repository.
2026-05-17 Add references for cited papers and include download links
    - Added a new PDF reference: "Polymer Reinforced Solder Paste for Improving Impact Energy Absorption Capability in Micro LED Laser-Assisted Mass Transfer."
    - Created a markdown file listing all cited papers with direct download links, including access notes for TU Delft resources.
    [tud-microled-v2-aisler-bom.csv, tud-microled-v2.kicad_pcb, tud-microled-v2.kicad_sch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]
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2026-05-17 Update PCB documentation and scripts for Eurocircuits compatibility
    - Enhanced README.md to reflect support for both Aisler and Eurocircuits, including updated ordering instructions and BOM generation.
    - Revised V2_DESIGN_NOTES.md to clarify compatibility with Eurocircuits Class-4 capabilities.
    - Updated VERIFICATION_v4.md to indicate copper thickness specifications for both Aisler and Eurocircuits.
    - Added new fab-neutral BOM generation script (gen_fab_bom.py) to accommodate both Aisler and Eurocircuits assembly processes.
    - Created new BOM file (tud-microled-v2-fab-bom.csv) for unified fabrication output.
    - Modified EMAIL.md to specify options for placing orders with either Aisler or Euroc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
    [tud-microled-v2-aisler-bom.csv, tud-microled-v2-fab-bom.csv]
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2026-05-19 Remove email correspondence and related documents for ET4277/ET4391 project; update KiCad project zip file; fix BOM issues for Eurocircuits; switch to bare PCB order for faster turnaround.
    [tud-microled-v2-B_Courtyard.gbr, tud-microled-v2-B_Cu.gbl, tud-microled-v2-B_Fab.gbr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]
2026-05-19 Update KiCad project files for microLED design; modified project archive to reflect recent changes.
    [tud-microled-v2-B_Courtyard.gbr, tud-microled-v2-B_Cu.gbl, tud-microled-v2-B_Fab.gbr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]
2026-05-19 Finalize PCB for Eurocircuits order: - Updated Yageo resistor MPN from RT0603BRD07100RL to RT0603BRB07100RL for better availability and performance. - Added 3D model references for various footprints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
    [tud-microled-v2-B_Courtyard.gbr, tud-microled-v2-B_Cu.gbl, tud-microled-v2-B_Fab.gbr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]
2026-05-20 Update Gerber files and PCB design for tud-microled-v2
    - Updated creation dates in Gerber files to 2026-05-20.
    - Added F.Paste layer to NTC_0402 and EIS_Load_0603 pads in the PCB design.
    - Restored F.Paste apertures for specific components in the SMT paste file.
    - Modified various user and eco files to reflect the new creation date.
    - Updated STEP file with new timestamp and minor directional adjustments.
    - Added a new script to automate the restoration of F.Paste for specific footprints.
    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
    [tud-microled-v2-B_Courtyard.gbr, tud-microled-v2-B_Cu.gbl, tud-microled-v2-B_Fab.gbr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]
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2026-06-20 Add corrected solder-paste stencil (F.Paste) for v2 board
    The first stencil had apertures on only 10 pads (TH1-4 + R_EIS_LOAD) because
    those were the sole pads carrying F.Paste, so it came back effectively
    "reversed" - open only where solder was already hand-applied.
    This rebuilds the F.Paste layer so the new mask snug-fits and prints paste
    where it's actually needed:
    - Add 1:1 paste apertures to all 327 exposed conductive pads (BondPad_DoE,
    WL-SFCC LEDs, probe pads, TLM/VDP, TC pads, fiducials).
    - Replace pad paste on already-populated parts with body-clearance reliefs
    drawn around the component so the foil lies flat with no bulges:
    H_N/H_S headers, TH1-4 thermistors, R_EIS_LOAD resi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
    [tud-microled-v2.kicad_pcb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]
2026-06-20 Stencil v2: exclude probe/test/fiducial pads, widen header reliefs
    Per assembly intent, paste only goes on pads that get bonded/soldered:
    - Keep paste on DoE bond pads (BP_*), LED lands (D1-8, DCL6/DCL12), TC pads.
    - Remove paste from everything the probe station or vision touches: all PP_*
    probe pads (daisy-chain, per-LED, NTC, GND, EIS open/short cal), TLM/VDP
    test structures, and FID fiducials (87 pads -> bare copper, mask only).
    - Widen the H_N/H_S header reliefs (now 3.8 mm) so the already-soldered pins
    and body clear the foil and it lays flat on the PCB.
    240 paste apertures, 7 body reliefs. DRC clean (0 violations).
    Claude-Session: https://claude.ai/code/session_011vFFhLhzgMnAt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
    [tud-microled-v2.kicad_pcb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]
2026-06-20 Stencil v2: keep solder on TLM ladders and Van der Pauw structures
    TLM/VDP are part of the solder/contact-resistance characterization, so they
    need paste after all. Re-added F.Paste to TLM_* and VDP_* (37 pads).
    Now 277 paste apertures. Still bare: PP_* probe pads + FID fiducials only.
    Noted that the 0.15/0.25 mm VDP squares are below reliable paste-release.
    DRC clean (0 violations).
    Claude-Session: https://claude.ai/code/session_011vFFhLhzgMnAtLoSZsN5RL
    [tud-microled-v2.kicad_pcb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]
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2026-08-03 Add measurement results and documentation for round 1
    - Created new CSV files for measurement results: R1_dies.csv, R1_meter.csv, R1_temp.csv.
    - Added README.md to explain the results files and reporting procedure.
    - Included datasheets for Arduino UNO R3 and Thsinde 18B+ multimeter.
    - Documented specifications and characteristics of the Thsinde 18B+ multimeter in INSTRUMENTS.md.
    - Updated README.md in datasheets to include test-equipment documentation.
    - Added independent review PDF for Thsinde 18B+ multimeter.
    - Updated measurement plans and sample metadata to reflect blind measurement process.
    - Corrected NTC thermistor B-value in various documentation files.
    [R1_board.csv, R1_chain_ends.csv, R1_channels.csv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]
2026-08-03 Update measurement documentation and results for Round 1, including detailed procedures, new data entries, and overview photos for boards.
    [R1_channels.csv, R1_dies.csv, R1_meter.csv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]
2026-08-03 Update measurement results in CSV files for Round 1, adding detailed readings for all boards and enhancing temperature data entries.
    [R1_board.csv, R1_temp.csv]
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2026-08-03 Update measurement documentation and results for Round 1, clarifying anode identification and correcting pad mapping for accurate probing.
    [R1_channels.csv]
2026-08-03 Update measurement results in R1_channels.csv, correcting pad mapping and adding detailed readings for D2, D3, D4, D6, D7, and D8.
    [R1_channels.csv]
2026-08-04 Update results for R1 channels and dies; address die detachment and contamination issues
    - Marked detached dies in R1_channels.csv with detailed failure descriptions.
    - Updated R1_dies.csv to reflect die detachment and corrected previous errors regarding die presence.
    - Added notes in README.md regarding contamination on boards 3/4, emphasizing the need to treat readings as process failures and exclude from V_F statistics.
    [R1_board.csv, R1_channels.csv, R1_dies.csv]
2026-08-04 Refactor measurement documentation and update results for daisy chain exclusions
    - Updated `R1_dies.csv` to reflect that daisy chains on boards 1 and 2 are electrically dead due to design faults, with detailed explanations for each die.
    - Revised `README.md` to clarify the exclusion of daisy chains and their impact on sample counts.
    - Added a new decision entry in `DECISIONS.md` regarding the electrical status of daisy chains and the necessary design corrections.
    - Adjusted `MEASUREMENT_PLAN.md` to indicate that chain sections are void due to the design fault.
    - Modified `PHASE1_DMM_ONLY.md` to exclude daisy chains from the measurement scope and updated the sample count accordingly.
    - Update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
    [R1_chain_ends.csv, R1_channels.csv, R1_dies.csv]
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2026-08-05 Add measurement data for R2 sweeps and verification results
    - Introduced new CSV files for measurement data:
    - s1_D2_R_seat1.csv: Contains raw bandgap measurements and IV sweep data.
    - verify_100R_step3_FAILED.csv: Records failed verification results for a 100 ohm dummy load.
    - verify_100R_step3_PASS.csv: Contains successful verification results for a 100 ohm dummy load.
    - Added R2_meter.csv: A comprehensive log of resistance measurements and calibration notes, including details on faults and corrective actions for the measurement setup.
    These additions enhance the dataset for analysis and troubleshooting of the measurement system.
    [R2_meter.csv, adc_diag_prescaler_discard.csv, heat_os1024_D1_R.csv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]
2026-08-05 Add new measurement data for R2 sweeps and update results
    - Added new CSV files for measurements: s1_D7_R_seat1.csv, s1_D8_B_seat1.csv, s1_D8_G_seat1.csv, and s1_D8_R_seat1.csv.
    - Each file contains detailed IV sweep data including current, voltage readings, and notes on rail voltage and sag.
    - Updated R2_meter.csv with a new entry confirming the open circuit status of channel D6.
    [R2_meter.csv, s1_D2_B_seat1.csv, s1_D2_G_seat1.csv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]
2026-08-05 Add new measurement data for bandgap and verify 100R close board
    - Added s1_D8_G_seat1.csv and s1_D8_R_seat1.csv with detailed IV sweep data for bandgap measurements.
    - Introduced verify_100R_close_board1.csv containing measurements for the 100R resistor verification.
    - Updated R2_meter.csv with findings related to measurement precision and identified a bug in bandgap quantization affecting voltage readings.
    [R2_meter.csv, s1_D1_B_seat1.csv, s1_D1_G_seat1.csv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]
2026-08-05 Add new measurement data for various channels and update results
    - Added new CSV files for measurements on channels s2_D8_B, s2_D8_G, s2_D8_R, and verification of 100R close on board 2.
    - Each file includes detailed measurement data including current, voltage readings, and notes on the conditions and observations during the sweeps.
    - Updated RESULTS/R2_meter.csv to reflect the findings from the new measurements, confirming open circuits on specific channels and reinforcing the reliability of previous screening results.
    [R2_meter.csv, s2_D2_B_seat1.csv, s2_D2_G_seat1.csv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]
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2026-08-06 Add new measurement data for R2 sweeps in seat1
    - Created s8_D7_G_seat1.csv with bandgap raw 220.891 and rail at 5.0283 V.
    - Created s8_D7_R_seat1.csv with bandgap raw 221.016 and rail at 5.0254 V.
    - Created s8_D8_B_seat1.csv with bandgap raw 221.031 and rail at 5.0251 V.
    - Created s8_D8_G_seat1.csv with bandgap raw 220.797 and rail at 5.0304 V.
    All files include detailed IV sweep data and warnings regarding rail sag.
    [s7_D1_B_seat1.csv, s7_D1_G_seat1.csv, s7_D1_R_seat1.csv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]
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2026-08-06 Add Round 2 report and update meter CSV with leakage step note
    - Created a new markdown report (R2_REPORT.md) detailing the results and conclusions from the Round 2 Arduino I-V sweep, including findings on series resistance, yield, measurement reliability, and identified rig defects.
    - Updated the R2_meter.csv file to include a note regarding the skipped Step 6 reverse leakage measurement, emphasizing its significance in understanding shunt paths and contact resistance.
    [R2_meter.csv]
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2026-08-06 Refactor leakage.py and update leakage documentation
    - Updated text descriptions in leakage.py for clarity on reverse leakage measurements.
    - Adjusted DMM probe annotations and added details on measurement methodology.
    - Modified SVG output to reflect changes in text and layout for better readability.
    - Increased height of reading section in SVG to accommodate additional information.
    - Revised notes for DMM settings and measurement expectations.
    - Added new CSV file (R2_leakage.csv) with detailed leakage test results for multiple boards, including voltage readings and verdicts.
    [R2_leakage.csv]
2026-08-06 Add reverse bias check results and update electrical characterization documentation
    [R2_leakage.csv]
2026-08-08 Rewrite README as a presentable project front page
    Leads with the headline result (yield separates the eight assembly
    conditions, series resistance cannot, and the fixture repeatability
    proves why), then walks board design, cleanroom bonding and electrical
    characterization. Embeds the fab render, bonding photos, rig drawing and
    the yield, defect-map, I-V and shunt-detection figures. Adds a known
    limits table, a full repository map with links, reproduction steps and
    credits.
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2026-08-12 Refactor method references and update documentation
    - Updated method references in the bibliography to reflect the latest IEEE sources.
    - Added new PDF references for recent publications related to LED characterization.
    - Revised the method-reference document generation script for clarity and accuracy.
    - Adjusted the structure and content of the method references section in the draft notes.
    - Corrected discrepancies in numerical values and clarified statistical methods used in the analysis.
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2026-08-13 Refactor email to Ahmed with updated references and corrections; add daisy chain figure generation script and contents for deliverable
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
